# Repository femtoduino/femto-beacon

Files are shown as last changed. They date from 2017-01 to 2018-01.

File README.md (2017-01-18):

# femto-beacon
FemtoBeacon - Atmel SAM R21 (ARM Cortex M0+, SAM D21 with built in AT86RF233)

To contribute work, please do the following:

 - Fork https://github.com/femtoduino/femto-beacon
 - Checkout your fork of femto-beacon to your machine. You should now have something like `https://github.com/<your_username>/femto-beacon`
 - Add the femtoio/femto-beacon repository as the 'upstream' remote repository of your fork.

```
# Inside the checkout of your fork, add us as the remote repository named 'upstream'
git remote add upstream https://github.com/femtoduino/femto-beacon.git

# Remember to fetch from upstream to get all branch information
git fetch upstream
```

Now, you can pull the latest changes from 'upstream' into your fork, and push all work to your own fork
```
# To list branches.
git branch -a

# To pull changes from upstream 'master' branch into your 'master' branch (assuming you're in the master branch already)
git pull upstream master

# To switch into an existing branch named 'develop'
git checkout develop

# To create a new branch based on the develop branch
git checkout develop
# ...then, make sure you get the latest from upstream
git pull upstream develop
# ...now, create your new branch.
git checkout -b my-new-branch

# To push your new branch to your github fork
git push origin my-new-branch
```

...Once you push your changes to your fork, you may submit a Merge Request via github.
We will review and assess the changes before accepting or rejecting your changes.

## Requirements

For Arduino support, see https://github.com/femtoduino/ArduinoCore-atsamd21e18a/

For bare-metal programming, see below.

On Ubuntu machines, you will need Terry Guo's arm-none-eabi-* toolchain, along with the build-essentials package, openocd 0.9.x with cmsis-dap and hidapi-libusb enabled, and the BOSSA utility.

See the following on how to build OpenOCD on your machine: https://github.com/RIOT-OS/RIOT/wiki/OpenOCD
You must assert the required libraries are installed on your machine.

Compile OpenOCD with the following flags to enable cmsis-dap and hidapi support:
```
# Inside the openocd source code folder...
./configure --enable-maintainer-mode --enable-cmsis-dap --enable-hidapi-libusb
make
sudo make install
```

Install Eclipse C++, and the GNU ARM Eclipse plugins.

Install the BOSSA utility.

See https://github.com/shumatech/BOSSA

## Setup
Download the Atmel Software Framework into the libraries/ folder before compiling examples.
If you have the Atmel Software framework files in a directory named `asf-3.21.0`, then you would need it as `femto-beacon/libraries/asf-3.21.0`

Symlink the boards/femtobeacon folder into your copy of the ASF framework (libraries/asf-x.xx.x/sam0/boards/femtobeacon).
Symlink the femtoIO MPU9250 library folder into your copy of the ASF framework (libraries/asf-x.xx.x/thirdparty/MPU9250).

You can symlink the femto-beacon examples to your Eclipse workspace folder. For example, if you want to make the 'sam-r21-blink' project availabe in Eclipse:

```
# Use ~ or full path! Do not use ./
ln -s /path/to/femto-beacon/examples/sam-r21-blink /path/to/eclipse/workspace/sam-r21-blink
```

...Refresh the Project Explorer panel to view it as a project.

Update the example's config.mk file accordingly
```
# Path to top level ASF directory relative to this project directory.
PRJ_PATH = ../../libraries/asf-3.21.0
```

Then, open up the example in Eclipse, and build. This should generate a BIN file you can then upload to your board using the BOSSA shell.

## How to create a new project
Create a new C project in Eclipse, symlink the libraries/ folder from femto-beacon/libraries into your project's directory.
```
cd MyNewProject/
ln -s /path/to/femto-beacon/libraries libraries
```
You can then copy/modify the asf.h, config.mk, and Makefile into your new project. Remember to modify config.mk to include the paths of the ASF modules you wish to use.

## FemtoBeacon BT support (Nordic nRF52832 Bluetooth 4.2 + NFC, ARM Cortex M4L)
This board is unreleased at this time. These notes are here for future use.
For toolchain setup, see https://devzone.nordicsemi.com/tutorials/7/

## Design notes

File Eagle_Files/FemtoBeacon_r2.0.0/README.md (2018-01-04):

eagle-pcb-helpers
=================

A collection of JS utilities to help with Eagle PCB grunt work.

## Panelizer helper
A utility to help you panelize stuff outside the board size limits.

Image of the Panelizer helper

### Requires

 - Node http-server `npm install -g http-server`

### Usage
Use a terminal, navigate to this folder, and run `http-server ./`, then open up [https://localhost:8080/panelizer_helper.html](https://localhost:8080/panelizer_helper.html) in your favorite browser.

### About
Due to the artificially (and arbitrarily) imposed board size limitations of EAGLE PCB licensing, it becomes impossible to panelize large amounts of small boards.
This tool allows one to copy a column of board outlines, components, and text, and create the corresponding XML with updated part names (such as "IC1...IC5" to "IC6...IC10", etc), while applying a shift value to the X coordinates.

You still need to manually open the .brd file, and locate the last column of `<element>` nodes, but you can simply copy and paste that XML into this helper, set an X offset value, and process the text to generate the next column.

EAGLE PCB doesn't have any problem copying vias and traces outside the artificial boundry limits, so you really only need this tool for dimensions and components.

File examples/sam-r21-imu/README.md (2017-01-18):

You will need to symlink the libraries/ directory to your project.

The libraries/ folder should contain a symlink to your copy of the 
Atmel Software Framework (such as asf-3.21.0/).

Symlink the boards/femtobeacon/ folder to make it available as 
libraries/<your asf folder>/sam0/boards/femtobeacon/

Finally, grab a checkout of the Femto.io "MPU9250" library from git at 
https://github.com/femtoio/MPU9250, and symlink it to the 
libraries/<your asf folder>/thirdparty/ folder, resulting in a directory 
that looks like this:

libraries/<your asf folder/thirdparty/MPU9250

...Eclipse C++ with the GNU ARM Eclipse plugin should compile your project 
just fine now.

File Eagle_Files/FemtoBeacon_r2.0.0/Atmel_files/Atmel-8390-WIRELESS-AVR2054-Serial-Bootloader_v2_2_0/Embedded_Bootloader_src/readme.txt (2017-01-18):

Bootloader. Revision 2.1

Supported devices:
         MCU                                           external flash memory          RF4CE boot func  
atxmega128a1  (not tested):                                  nothing                         no 
atxmega256a3  (both compilers):                              at45db041                       no 
atmega1281    (both compilers):                              at25f2048, at45db041            yes
atmega2561    (both compilers):                              nothing                         no 
atmega128rfa1 (both compilers):                              at25f2048, at45db041            yes
atmega256rfr2 (both compilers):                              AT25DF041A                      yes
atxmega256d3  (both compilers):                              at45db041                       no

Fuse bytes for xmega:            (with and without OTAU)
FUSEBYTE0                                 0xFF
FUSEBYTE1                                 0x00
FUSEBYTE2                                 0xBF
FUSEBYTE4                                 0xFE
FUSEBYTE5                                 0xFF

Fuse bytes for atmega:       (without OTAU)     (with OTAU)     (with RF4CE boot functions)
EXTENDED                        0xFF              0xFF                    0xFF  
HIGH                            0x9C              0x9A                    0x9A 
LOW                             0x62              0x62                    0x62

Fuse bytes for atmega128rfa1/256rfr2:(without OTAU)     (with OTAU)     (with RF4CE boot functions)
EXTENDED                                  0xFE              0xFE                    0xFE   
HIGH                                      0x9C              0x9A                    0x9A
LOW                                       0x62              0x62                    0x62

Revision history:

1.0 - Initial revision.

1.1 - ATmega1281\2561 is supported.

1.2 - SPI serializer support is added for xMega, with the following parameters:
 - frequency is less or equal to 200kHz
 - start of SPI clock after slave select greater or equal to 100ns
 - delay between consecutive transfers greater or equal to 100us

spiFlasher is added to test the SPI part of the embedded bootloader (valid for the SAM7X evaluation board only).
Hardware sources used by spiFlasher:
 - IRQ1 - interrupt line for the slave data ready station (A15 on S3)
 - SPI1 - SPI interface (clock - A23, mosi - A24, miso - A25, ss - A26 on S3)

1.3 - Loading from external flash is supported for ATmega1281. The AT25f2048 external SPI flash is used. 
USART0 is used in MSPI mode; pin F3 is set as chip select. Size of boot section is 4 kbytes.

1.4 - Service area are increased (by 1 byte) for the external flash loader.

1.5 - ATmega128rfa1 is supported.

1.6 - ATxmega256d3 is supported. AT45db041 can be used for the bootloader with OTAU support.
xMega(ATxmega256a\d3) supports external flash. Both MCUs use SPI on port D to connect to external flash.
ATmega1281 and ATmega128rfa1 support AT25f2058 and AT45db041.
ATxmega256a3 and ATxmega256d3 support AT45db041.
Workaround is introduced for the following problem with xMega:
"Writing EEPROM or Flash while reading any of them will not work".

1.7 - Functions for RF4CE OTAU are added (only for ATmega1281 and ATmega128rfa1 and compilation with GCC)

1.8 - Start procedure was refactored: several interfaces are supported in a single
bootloader assembly; all interfaces scan for host's activity for 200ms by turn with 
one interface becoming main when host's activity is detected. 
IAR support is dropped.

2.0 - IAR projects are restored. AVR Studio 5 projects are added.

AT91SAM3S4C is supported, and the device firmware upgrade class of usb is supported.
Cortex bootloader is placed in the last 4kb of the internal flash memory (exclude vectors). Vectors are eliminated upon the
first image downloading (exclude reset vector). Bootloader stores the reset vector of the user's application and runs it 
by itself. A user's application can initiate a bootloading process by the use of the DFU application part from the BitCloud package 
or by writing the key byte 0x5A into the fifth byte to the end of the internal flash memory. Besides, the restoring mode 
can be initiated by connecting PB7 to the ground and turning it off\on. To load an image to a device the user can use
Bootloader PC Tool from the BitCloud package or dfu-util.exe (an open source utility, with max packet size equal to 64 bytes).

2.2 - ATmega256RFR2 device support,Atmel Studio 6 projects, Bootloading through TWI interface are added.

TWI interface is added for bootloading. The TWI boot loader allows loading of firmware images to target devices from Bootloader PC tool over the TWI interface.TWI cannot be used for direct communication with PC, an XMEGA-A1 Xplained kit is used in between for bridge functionality. The TWI module on ATxmega128A1 of XMEGA-A1 Xplained kit is configured in TWI master mode and the device running the TWI boot loader is configured in TWI slave mode. ATmega256RFR2 device support is added with projects in Atmel Studio 6 and IAR compiler. RF4CE, OTAU project support is also added for ATmega256RFR2 device. AVR Studio 4 and AVR Studio 5 projects are removed. Atmel Studio 6 projects are created for all supported devices

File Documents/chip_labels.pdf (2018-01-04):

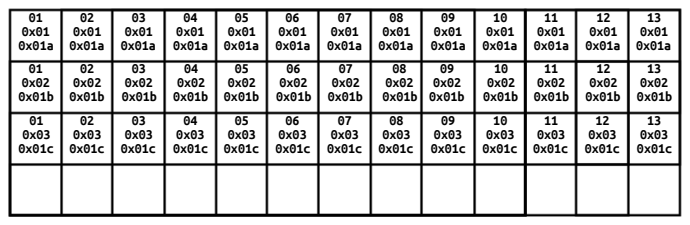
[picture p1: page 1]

02
0x03
0x01c

03
0x03
0x01c

04
0x03
0x01c

05
0x03
0x01c

06
0x03
0x01c

07
0x03
0x01c

08
0x03
0x01c

09
0x03
0x01c

10
0x03
0x01c

11
0x03
0x01c

12
0x03
0x01c

13
0x03
0x01c

01
0x01
0x01a

03
0x01
0x01a

02
0x01
0x01a

04
0x01
0x01a

05
0x01
0x01a

06
0x01
0x01a

07
0x01
0x01a

08
0x01
0x01a

09
0x01
0x01a

10
0x01
0x01a

11
0x01
0x01a
11
0x02
0x01b

12
0x02
0x01b

13
0x02
0x01b
01
0x03
0x01c

12
0x01
0x01a

13
0x01
0x01a
01
0x02
0x01b

02
0x02
0x01b

03
0x02
0x01b

04
0x02
0x01b

05
0x02
0x01b

06
0x02
0x01b

07
0x02
0x01b

08
0x02
0x01b

09
0x02
0x01b

10
0x02
0x01b

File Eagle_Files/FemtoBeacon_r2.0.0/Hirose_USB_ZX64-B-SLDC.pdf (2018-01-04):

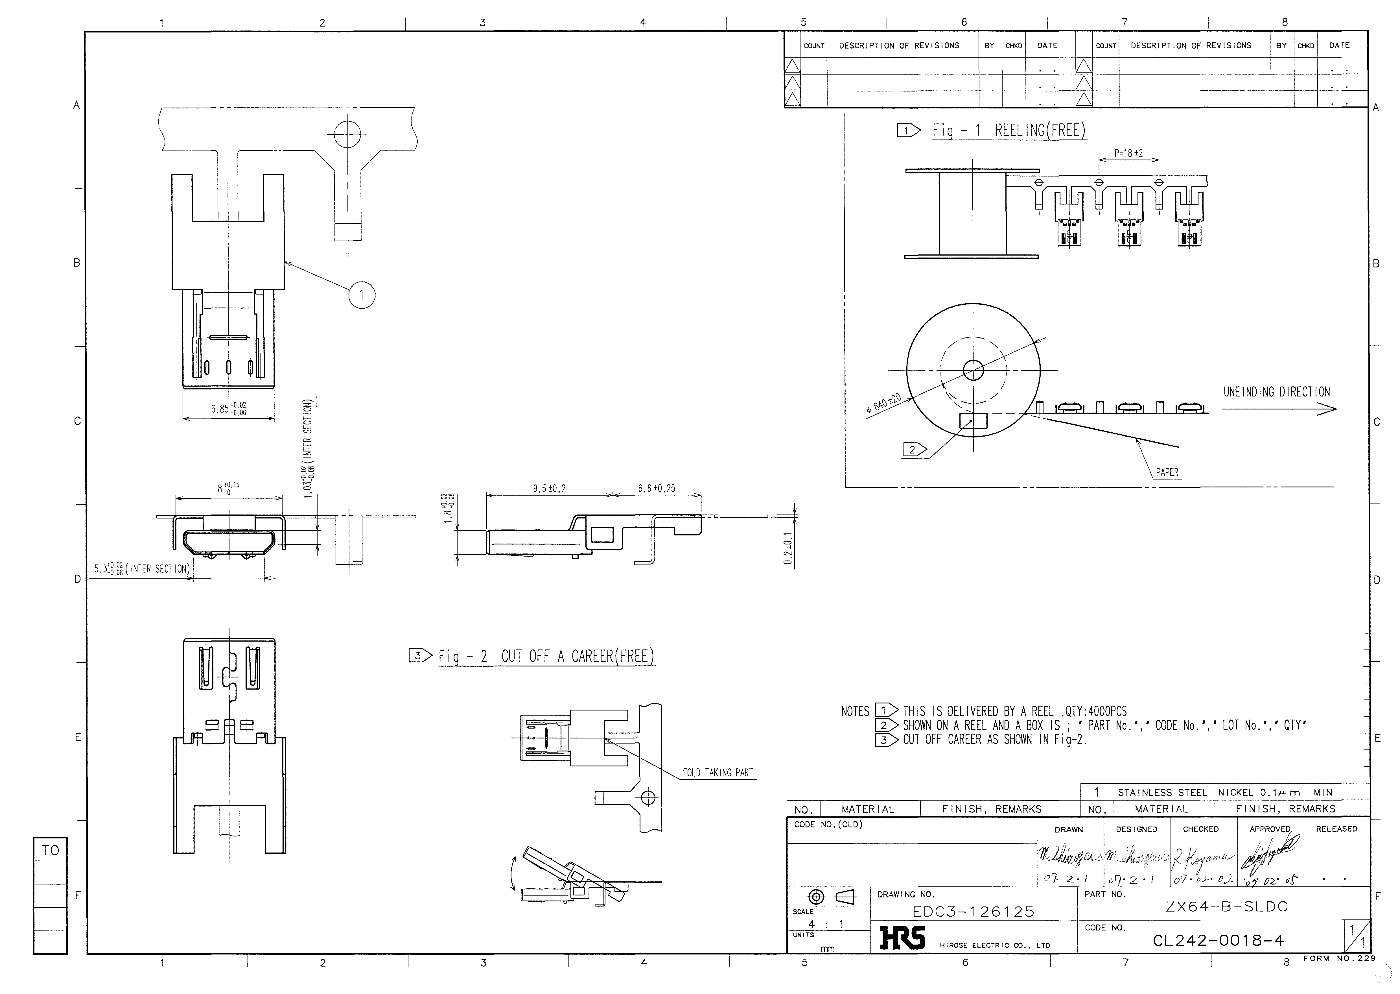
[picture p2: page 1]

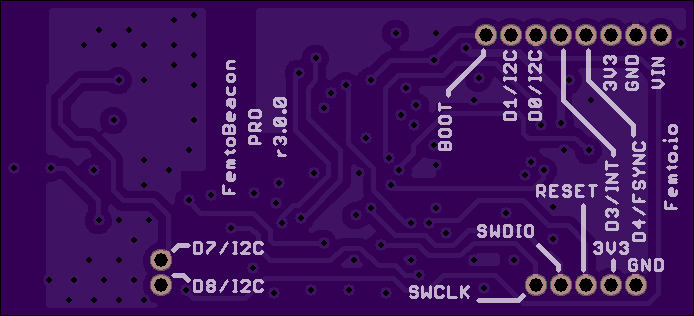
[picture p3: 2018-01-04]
Eagle_Files/FemtoBeacon_r2.0.0/femtoBeacon_PRO_r3.0.0-bottom.png

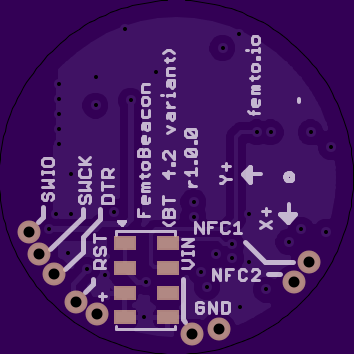
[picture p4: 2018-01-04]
Eagle_Files/FemtoBeacon_BLE_r1.0.0/FemtoBeacon_coin_nRF52832_BT4.2_r1.0.0_bottom.png

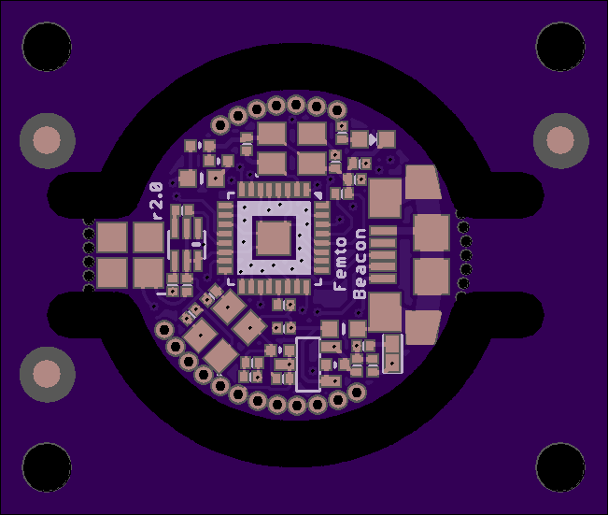
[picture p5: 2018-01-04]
Blender3d_Files/femtoBeacon_r2.0.3_top.png

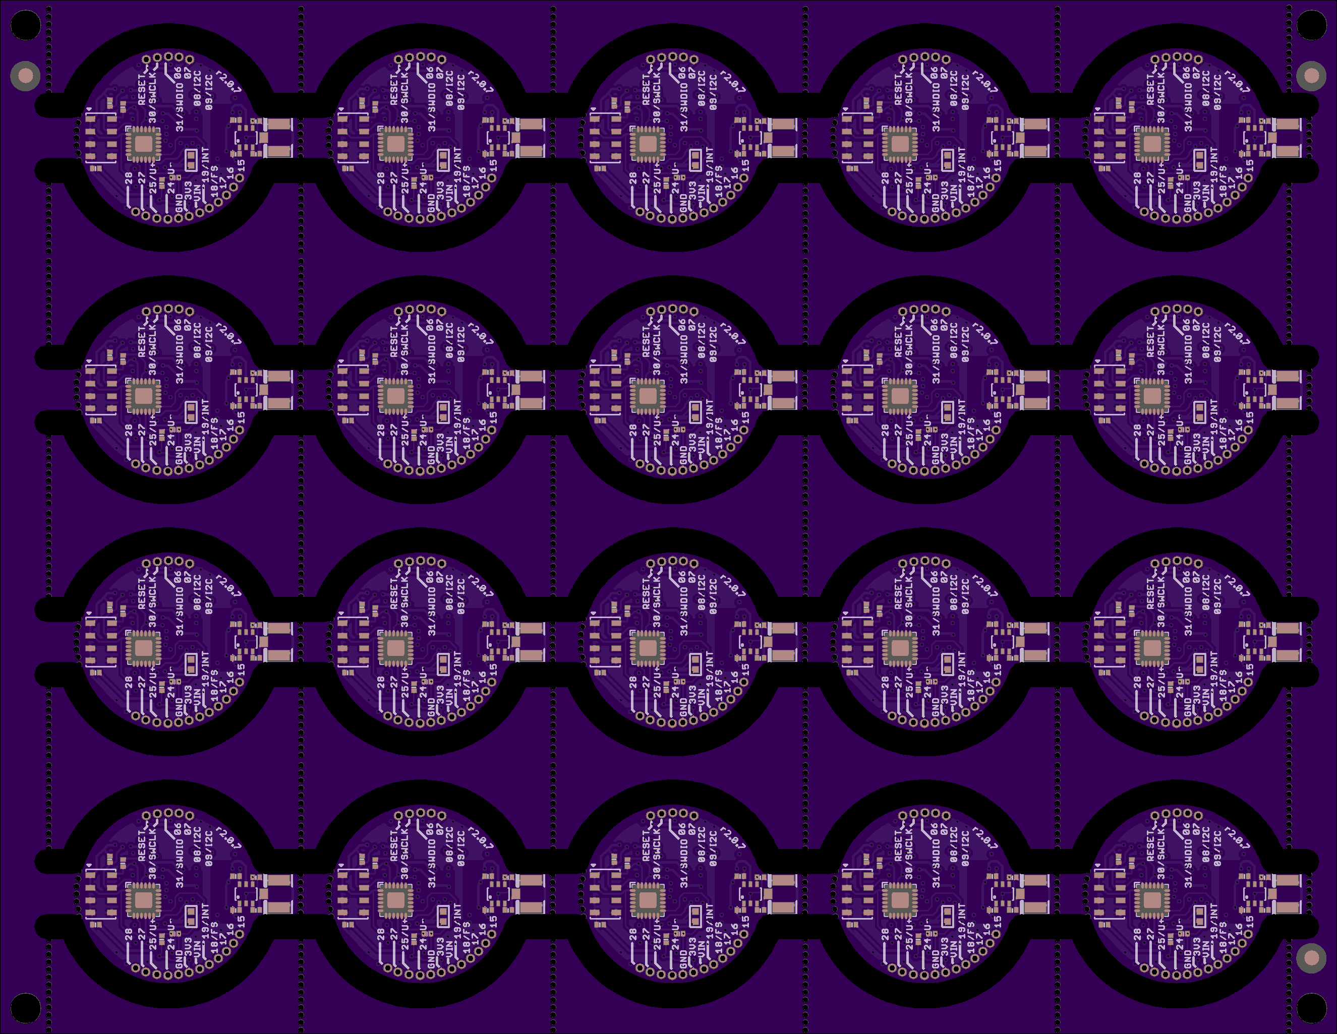
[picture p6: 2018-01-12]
Eagle_Files/FemtoBeacon_r2.0.0/femtoBeacon_r2.0.7_RGB_OTG_PANELIZED-bottom.png

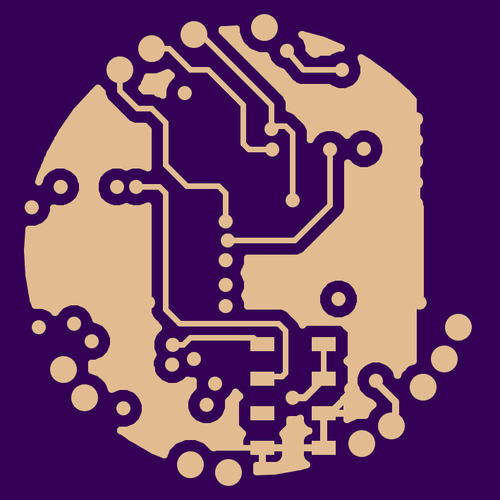
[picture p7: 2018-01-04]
Eagle_Files/FemtoBeacon_BLE_r1.0.0/femtoBeacon_BT_art1.png

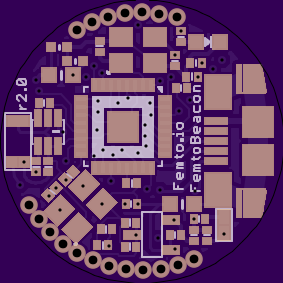
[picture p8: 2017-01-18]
Eagle_Files/FemtoBeacon_r2.0.0/femtoBeacon_r2.0.1-top.png

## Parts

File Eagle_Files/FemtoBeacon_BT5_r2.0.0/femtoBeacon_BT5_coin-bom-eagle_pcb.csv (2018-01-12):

Qty | Value | Device | Package | Parts | Description | MFR_ID
1 |  | PTCFUSE-1206 | R1206 | F1 | PTC fuses, resettable thermistors | 1206L050/15YR
1 | 0.1uF | CAPACITOR_0201 | PART | C2 |  | GRM033C80J104KE84D
1 | 10UH | INDUCTOR_0402MP | _0402MP | L2 | Inductors | LQM18FN100M00D
1 | 15nH | INDUCTOR_FIXED_0201 | PART | L1 |  | LQP03HQ15NJ02D
9 | 1X1_ROUND_MM | 1X1_ROUND_MM | 1X1_ROUND_MM | U$16, U$17, U$18, U$19, U$20, U$21, U$22, U$23, U$24
1 | 1X5_ROUND | 1X5_ROUND | 1X5_ROUND | U$6
3 | 330 | RESISTOR_0201 | PART | R1, R2, R3 |  | CRCW0201330RJNED
1 | 4.7uF | CAP_CERAMIC_0402MP | _0402MP | C1 | Ceramic Capacitors | CC0402KRX5R6BB475
3 | FIDUCIAL | FIDUCIAL | FIDUCIAL_1MM | FID1, FID2, FID3 | For use by pick and place machines to calibrate the vision/machine, 1mm
1 | LRTB_R48G | LRTB_R48G | LRTB_R48G | LED1
1 | SCHOTTKY | LED0603_NOOUTLINE | CHIPLED_0603_NOOUTLINE | LED2 | LED | SD0603S040S0R2
1 | TY_BLE_EYSHSNZWZ | TY_BLE_EYSHSNZWZ | MODULE | IC |  | EYSHSNZWZ

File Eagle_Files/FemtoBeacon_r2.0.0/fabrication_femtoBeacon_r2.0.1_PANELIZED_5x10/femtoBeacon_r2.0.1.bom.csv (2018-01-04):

Qty | Value | Device | Package | Parts | Description | DIGIKEY_PART
1 |  | FERRITE_0603MP | _0603MP | FB1 | Ferrite Bead
10 | 0.1uF | CAPACITOR_0201 | PART | C1, C2, C8, C9, C10, C16, C17, C29, C30, C32 |  | 490-3194-1-ND
1 | 0.47uF | CAPACITOR_0201 | PART | C7
1 | 10K | RESISTOR_0201 | PART | R2
1 | 10nF | CAPACITOR_0201 | PART | C31 |  | 490-3194-1-ND
2 | 10pF | CAPACITOR_0201 | PART | C3, C4 |  | 490-3194-1-ND
2 | 10uF | CAP_CERAMIC_0402MP | _0402MP | C21, C22 | Ceramic Capacitors
1 | 10uH | INDUCTOR_0603MP | _0603MP | L6 | Inductors
1 | 12MHz | TSX-3225 | TSX-3225 | XOSC
1 | 16MHz | TSX-3225 | TSX-3225 | XOSCRF
2 | 2.2K | RESISTOR_0201 | PART | R8, R9
2 | 2.2uF | CAP_CERAMIC_0402MP | _0402MP | C5, C6 | Ceramic Capacitors
2 | 22pF, C0G, 5% | CAPACITOR_0201 | PART | C11, C12 |  | 490-3194-1-ND
2 | 330 | RESISTOR_0201 | PART | R1, R4
2 | 9pF | CAPACITOR_0201 | PART | C14, C15 |  | 490-3194-1-ND
1 | ATSAMR21E18A-MUT | ATSAMR21E18A-MUT | QFN32 | IC | This is the ATMEL SAMR21E QFN-32. ATSAMR21E18A
1 | BLUE | LED0603_NOOUTLINE | CHIPLED_0603_NOOUTLINE | LED2 | LED
1 | JOHANSON_2450BM15A0015E | JOHANSON_2450BM15A0015E | 0805_BALUN | BAL
1 | MCP1700T-3302E/TT | MCP1700T-3302E/TT | MCP1700T-3302E/TT | LDO_VREG | Microchip LDO "MCP1700" in a 3-Pin SOT-23 package.
1 | MPU-9250 | MPU-9250 | QFN_3X3MM | IMU
1 | MS5611-01BA03 | MS5611-01BA03 | MS5611-01BA03 | BARO
1 | PULSE_ANT_2.4GHZ | PULSE_ANT_2.4GHZ | ANT_BAR | ANT1 | Manufacturer part #W3008
1 | USB_MICROB | USB_MICROB | USB_MICROB_PACKAGE | USB | This is the hirose ZX62-B-5PA(11) MICRO-USB B Type female connection.

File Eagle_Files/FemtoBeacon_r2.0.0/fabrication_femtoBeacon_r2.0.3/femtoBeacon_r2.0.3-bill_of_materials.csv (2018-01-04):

Qty | Value | Device | Package | Parts | Description
1 |  | FERRITE_0603MP | _0603MP | FB1 | Ferrite Bead
10 | 0.1uF | CAPACITOR_0201 | PART | C1, C2, C8, C9, C10, C16, C17, C29, C30, C32
1 | 0.47uF | CAPACITOR_0201 | PART | C7
1 | 0479480001 | 0479480001 | 0479480001 | U$8
1 | 10K | RESISTOR_0201 | PART | R2
1 | 10nF | CAPACITOR_0201 | PART | C31
2 | 10pF | CAPACITOR_0201 | PART | C3, C4
2 | 10uF | CAP_CERAMIC_0402MP | _0402MP | C21, C22 | Ceramic Capacitors
1 | 10uH | INDUCTOR_0603MP | _0603MP | L6 | Inductors
1 | 12MHz | TSX-3225 | TSX-3225 | XOSC
1 | 16MHz | TSX-3225 | TSX-3225 | XOSCRF
19 | 1X1_ROUND | 1X1_ROUND | 1X1_ROUND | U$1, U$2, U$5, U$7, U$9, U$10, U$35, U$36, U$37, U$38, U$39, U$41, U$42, U$43, U$45, U$46, U$47, U$48, U$54
2 | 2.2K | RESISTOR_0201 | PART | R8, R9
2 | 2.2uF | CAP_CERAMIC_0402MP | _0402MP | C5, C6 | Ceramic Capacitors
2 | 22pF, C0G, 5% | CAPACITOR_0201 | PART | C11, C12
2 | 330 | RESISTOR_0201 | PART | R1, R4
2 | 9pF | CAPACITOR_0201 | PART | C14, C15
1 | ATSAMR21E18A-MUT | ATSAMR21E18A-MUT | QFN32 | IC | This is the ATMEL SAMR21E QFN-32. ATSAMR21E18A
1 | BLUE | LED0603_NOOUTLINE | CHIPLED_0603_NOOUTLINE | LED2 | LED
1 | DNP | CAPACITOR_0201 | PART | C13
1 | DNP | SPST_SMD | SPST_SMD | BTN
6 | FIDUCIAL | FIDUCIAL | FIDUCIAL_1MM | FID1, FID2, FID3, FID4, FID5, FID6 | For use by pick and place machines to calibrate the vision/machine, 1mm
1 | JOHANSON_2450BM15A0015E | JOHANSON_2450BM15A0015E | 0805_BALUN | BAL
1 | MCP1700T-3302E/TT | MCP1700T-3302E/TT | MCP1700T-3302E/TT | LDO_VREG | Microchip LDO MCP1700" in a 3-Pin SOT-23 package."
1 | MPU-9250 | MPU-9250 | QFN_3X3MM | IMU
1 | MS5611-01BA03 | MS5611-01BA03 | MS5611-01BA03 | BARO
1 | SOLDER_JUMPER_CLOSED | SOLDER_JUMPER_CLOSED | SOLDER_JUMP_CLOSED | SJ1
1 | USB_MICROB | USB_MICROB | USB_MICROB_PACKAGE | USB | This is the hirose ZX62-B-5PA(11) MICRO-USB B Type female connection.

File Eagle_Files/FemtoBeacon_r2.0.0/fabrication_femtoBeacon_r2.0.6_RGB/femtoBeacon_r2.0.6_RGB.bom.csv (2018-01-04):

Qty | Value | Device | Package | Parts | Description | MFR_ID
1 |  | ANTENNA_U.FL | U.FL | UFLANT | U.FL Antenna Connector | 734120110
1 |  | FERRITE_0603MP | _0603MP | FB1 | Ferrite Bead | BLM18RK102SN1D
10 | 0.1uF | CAPACITOR_0201 | PART | C1, C2, C8, C9, C10, C16, C17, C29, C30, C32 |  | CL03A104KP3NNNC
1 | 0.47uF | CAPACITOR_0201 | PART | C7 |  | C0603X5R0J474K030BC
1 | 479480001 | 479480001 | 479480001 | ANT_SMD |  | 479480001
1 | 1.2pF | CAP_CERAMIC_0402MP | _0402MP | C11 | Ceramic Capacitors | GRM1555C1H1R2BA01D
1 | 1.8nH | INDUCTOR_0603MP | _0603MP | L1 | Inductors | L-14C1N8SV4T
1 | 10K | RESISTOR_0201 | PART | R2 |  | RC0402FR-0710KL
1 | 10nF | CAPACITOR_0201 | PART | C31 |  | GRM033R71A103KA01D
2 | 10uF | CAP_CERAMIC_0402MP | _0402MP | C21, C22 | Ceramic Capacitors | 490-13233-1-ND
1 | 10uH | INDUCTOR_0603MP | _0603MP | L6 | Inductors | LQM18FN100M00D
1 | 16MHz | TSX-3225 | TSX-3225 | XOSCRF |  | TSX-3225 16.0000MF09Z-AC0
2 | 2.2K | RESISTOR_0201 | PART | R8, R9 |  | CRCW02012K20JNED
2 | 2.2uF | CAP_CERAMIC_0402MP | _0402MP | C5, C6 | Ceramic Capacitors | C1005X5R1A225K050BC
5 | 22pF, C0G, 5% | CAPACITOR_0201 | PART | C12, C18, C19, C20, C23 |  | GRM0335C1E220JA01D
4 | 330 | RESISTOR_0201 | PART | R1, R4, R6, R7 |  | CRCW0201330RJNED
1 | 330 | RESISTOR_0402 | _0402 | R3 | Resistors | CRCW0402330RJNED
2 | 9pF | CAPACITOR_0201 | PART | C14, C15 |  | C0603C0G1E090B030BG
1 | AS222-92LF | AS222-92LF | AS222-92LF | ASWITCH |  | AS222-92LF
1 | ATSAMR21E18A-MUT | ATSAMR21E18A-MUT | QFN32 | IC | This is the ATMEL SAMR21E QFN-32. ATSAMR21E18A | ATSAMR21E18A-MFT
1 | JOHANSON_2450BM15A0015E | JOHANSON_2450BM15A0015E | 0805_BALUN | BALUN |  | 2450BM15A0015E
1 | LRTB_R48G | LRTB_R48G | LRTB_R48G | RGBLED |  | LRTBR48G-P9Q7-1+R7S5-26+N5P-68-ZB
1 | MCP1700T-3302E/TT | MCP1700T-3302E/TT | MCP1700T-3302E/TT | LDO_VREG | Microchip LDO "MCP1700" in a 3-Pin SOT-23 package. | MCP1700T-3302E/TT
1 | MPU-9250 | MPU-9250 | QFN_3X3MM | IMU |  | MPU-9250
1 | MS5611-01BA03 | MS5611-01BA03 | MS5611-01BA03 | BARO |  | MS561101BA03-50
1 | USB_MICROB | USB_MICROB | USB_MICROB_PACKAGE | USB | This is the hirose ZX62-B-5PA(11) MICRO-USB B Type female connection. | ZX62-B-5PA(33)

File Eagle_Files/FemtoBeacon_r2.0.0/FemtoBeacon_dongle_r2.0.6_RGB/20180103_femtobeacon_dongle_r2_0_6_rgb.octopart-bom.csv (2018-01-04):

Qty | Line Item | Manufacturer | MPN | Octopart URL | Schematic Reference | Internal Part Number | Description | Total Qty (@ Batch Size: 100) | SKU | SKU | SKU | Packaging | Packaging | Packaging | Unit Price (@ Batch Size: 100) | Unit Price (@ Batch Size: 100) | Unit Price (@ Batch Size: 100) | In Stock | In Stock | In Stock | MOQ | MOQ | MOQ | URL | URL | URL | Distributor [Lowest Price (Overall)] | SKU [Lowest Price (Overall)] | Packaging [Lowest Price (Overall)] | Unit Price (@ Batch Size: 100) [Lowest Price (Overall)] | Line Total [Lowest Price (Overall)] | Batch Total [Lowest Price (Overall)] | In Stock [Lowest Price (Overall)] | MOQ [Lowest Price (Overall)] | URL [Lowest Price (Overall)] | Notes
 |  |  |  |  |  |  |  |  | Digi-Key | Mouser | Newark | Digi-Key | Mouser | Newark | Digi-Key | Mouser | Newark | Digi-Key | Mouser | Newark | Digi-Key | Mouser | Newark | Digi-Key | Mouser | Newark
2 | BLM18RK102SN1D | Murata | BLM18RK102SN1D | https://octopart.com/blm18rk102sn1d-murata-755186 | FB1, FB2 | FERRITE_0603MP | Ferrite Bead | 200 | 490-5228-1-ND | BLM18RK102SN1D | 73M9117 | Cut Tape |  | Cut Tape | 0.047 | 0.038 | 0.038 | 465161 | 54056 | 0 | 1 |  | 1 | https://octopart.com/click/track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 | https://octopart.com/click/track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 | https://octopart.com/click/track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 | LCSC | C88986 |  | 0.0139 | 0.0278 | 2.78 | 6050 | 50 | https://octopart.com/click/track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
1 | 931 | Keystone | 931 | https://octopart.com/931-keystone-7166852 | CN1 | USB_TYPEA | USB - Type A Connectors | 100 | 36-931-ND | 931 | 22M3566 | Bulk |  |  | 0.66 | 0.667 | 0.75 | 9287 | 1317 | 0 | 1 |  | 1 | https://octopart.com/click/track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 | https://octopart.com/click/track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 | https://octopart.com/click/track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 | TME | KEYS931 |  | 0.5753 | 0.5753 | 57.53 | 463 | 1 | https://octopart.com/click/track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
7 | GRM033C80J104KE84D | Murata | GRM033C80J104KE84D | https://octopart.com/grm033c80j104ke84d-murata-46692001 | C1, C2, C8, C9, C10, C16, C17 | CAPACITOR_0201 |  | 700 | 490-9980-1-ND | GRM033C80J104KE84D |  | Cut Tape |  |  | 0.00932 | 0.014 |  | 253 | 0 |  | 1 |  |  | https://octopart.com/click/track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 | https://octopart.com/click/track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 |  | Arrow | GRM033C80J104KE84D**MULT |  | 0.0069 | 0.048299999999999996 | 4.83 | 14500 | 1 | https://octopart.com/click/track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
1 | C0603X5R0J474K030BC | TDK | C0603X5R0J474K030BC | https://octopart.com/c0603x5r0j474k030bc-tdk-28166569 | C7 | CAPACITOR_0201 |  | 100 | 445-13653-1-ND | C0603X5R0J474K030BC | 78Y9870 | Cut Tape |  | Cut Tape | 0.0808 | 0.068 | 0.068 | 416854 | 76671 | 3180 | 1 |  | 10 | https://octopart.com/click/track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 | https://octopart.com/click/track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 | https://octopart.com/click/track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 | Chip One Stop Japan | C1S741000789620 | Cut Tape | 0.0262 | 0.0262 | 2.62 | 9926 | 50 | https://octopart.com/click/track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
1 | 51T4020 | Molex | 47948-0001 | https://octopart.com/47948-0001-molex-20326346 | U$6 | 479480001 |  | 100 |  | 47948-0001 | 51T4020 |  |  | Cut Tape |  | 1.18 | 0.819 |  | 5669 | 0 |  |  | 1 |  | https://octopart.com/click/track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 | https://octopart.com/click/track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 | Newark | 51T4020 | Cut Tape | 0.819 | 0.819 | 81.89999999999999 | 0 | 1 | https://octopart.com/click/track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
1 | GRM1555C1H1R2BA01D | Murata | GRM1555C1H1R2BA01D | https://octopart.com/grm1555c1h1r2ba01d-murata-18814399 | C11 | CAP_CERAMIC_0402MP | Ceramic Capacitors | 100 | 490-6209-1-ND | GRM1555C1H1R2BA01D | 31Y1753 | Cut Tape |  | Cut Tape | 0.0223 | 0.023 | 0.023 | 1910 | 101362 | 30286 | 1 |  | 10 | https://octopart.com/click/track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 | https://octopart.com/click/track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 | https://octopart.com/click/track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 | LCSC | C76954 |  | 0.0041 | 0.0041 | 0.41000000000000003 | 750 | 50 | https://octopart.com/click/track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
1 | L-14C1N8SV4T | Johanson | L-14C1N8SV4T | https://octopart.com/l-14c1n8sv4t-johanson-12565139 | L1 | INDUCTOR_0603MP | Inductors | 100 | 712-1426-1-ND | L-14C1N8SV4T |  | Cut Tape |  |  | 0.0411 | 0.035 |  | 4289 | 15070 |  | 1 |  |  | https://octopart.com/click/track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 | https://octopart.com/click/track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 |  | Mouser | L-14C1N8SV4T |  | 0.035 | 0.035 | 3.5000000000000004 | 15070 |  | https://octopart.com/click/track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
1 | RC0402FR-0710KL | Yageo | RC0402FR-0710KL | https://octopart.com/rc0402fr-0710kl-yageo-55458461 | R2 | RESISTOR_0201 |  | 100 | 311-10.0KLRCT-ND | RC0402FR-0710KL | 98K7499 | Cut Tape |  | Cut Tape | 0.0056 | 0.003 | 0.006 | 10142433 | 2551721 | 323566 | 1 |  | 10 | https://octopart.com/click/track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 | https://octopart.com/click/track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 | https://octopart.com/click/track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 | LCSC | C60490 |  | 0.0017 | 0.0017 | 0.16999999999999998 | 493200 | 100 | https://octopart.com/click/track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
2 | AMK105CBJ106MV-F | Taiyo Yuden | AMK105CBJ106MV-F | https://octopart.com/amk105cbj106mv-f-taiyo+yuden-24529245 | C21, C22 | CAP_CERAMIC_0402MP | Ceramic Capacitors | 200 | 587-3237-1-ND | AMK105CBJ106MV-F | 29X9101 | Cut Tape |  | Cut Tape | 0.1 | 0.104 | 0.104 | 346664 | 51023 | 20000 | 1 |  | 1 | https://octopart.com/click/track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 | https://octopart.com/click/track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 | https://octopart.com/click/track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 | Chip One Stop Japan | C1S758100418570 | Cut Tape | 0.0623 | 0.1246 | 12.46 | 11700 | 50 | https://octopart.com/click/track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
1 | LQM18FN100M00D | Murata | LQM18FN100M00D | https://octopart.com/lqm18fn100m00d-murata-387572 | L6 | INDUCTOR_0603MP | Inductors | 100 | 490-4025-1-ND | LQM18FN100M00D |  | Cut Tape |  |  | 0.0893 | 0.089 |  | 137411 | 49320 |  | 1 |  |  | https://octopart.com/click/track?country=US&ak=68b25f31&sig=0e2d062&sid=459&ppid=387572&vpid=1864289&ct=offers | https://octopart.com/click/track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 |  | LCSC | C86083 |  | 0.0455 | 0.0455 | 4.55 | 16910 | 10 | https://octopart.com/click/track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
1 | TSX-3225 16.0000MF09Z-AC0 | Epson | TSX-3225 16.0000MF09Z-AC0 | https://octopart.com/tsx-3225+16.0000mf09z-ac0-epson-12822835 | XOSCRF | TSX-3225 |  | 100 | SER4069CT-ND | TSX-3225 16.0000MF09Z-AC0 |  | Cut Tape |  |  | 0.374 | 0.34 |  | 55482 | 374 |  | 1 |  |  | https://octopart.com/click/track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 | https://octopart.com/click/track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 |  | Mouser | TSX-3225 16.0000MF09Z-AC0 |  | 0.34 | 0.34 | 34 | 374 |  | https://octopart.com/click/track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
2 | C1005X5R1A225K050BC | TDK | C1005X5R1A225K050BC | https://octopart.com/c1005x5r1a225k050bc-tdk-25947534 | C5, C6 | CAP_CERAMIC_0402MP | Ceramic Capacitors | 200 | 445-7392-1-ND | C1005X5R1A225K050BC | 05X9833 | Cut Tape |  | Cut Tape | 0.1518 | 0.112 | 0.112 | 209061 | 0 | 55521 | 1 |  | 10 | https://octopart.com/click/track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 | https://octopart.com/click/track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 | https://octopart.com/click/track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 | TTI | C1005X5R1A225K050BC. |  | 0.101 | 0.202 | 20.200000000000003 | 15200 |  | https://octopart.com/click/track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
5 | GRM0335C1E220JA01D | Murata | GRM0335C1E220JA01D | https://octopart.com/grm0335c1e220ja01d-murata-22235265 | C18, C19, C20, C23, C24 | CAPACITOR_0201 |  | 500 | 490-1253-1-ND | GRM0335C1E220JA01D | 80X8548 | Cut Tape |  | Cut Tape | 0.004 | 0.006 | 0.004 | 7140 | 11200 | 6685 | 1 |  | 10 | https://octopart.com/click/track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 | https://octopart.com/click/track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 | https://octopart.com/click/track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 | LCSC | C76919 |  | 0.0017 | 0.008499999999999999 | 0.8499999999999999 | 600 | 100 | https://octopart.com/click/track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
4 | CRCW0201330RJNED | Vishay | CRCW0201330RJNED | https://octopart.com/crcw0201330rjned-vishay-39985897 | R1, R4, R6, R7 | RESISTOR_0201 |  | 400 | 541-330AGCT-ND | CRCW0201330RJNED | 48P7351 | Cut Tape |  | Tape & Reel | 0.0286 | 0.028 |  | 17953 | 22577 | 0 | 1 |  | 10000 | https://octopart.com/click/track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 | https://octopart.com/click/track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 | https://octopart.com/click/track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 | Mouser | CRCW0201330RJNED |  | 0.028 | 0.112 | 11.200000000000001 | 22577 |  | https://octopart.com/click/track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
2 | C0603C0G1E090B030BG | TDK | C0603C0G1E090B030BG | https://octopart.com/c0603c0g1e090b030bg-tdk-26012936 | C14, C15 | CAPACITOR_0201 |  | 200 | 445-5562-1-ND |  |  | Cut Tape |  |  | 0.1442 |  |  | 22259 |  |  | 1 |  |  | https://octopart.com/click/track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 |  |  | Digi-Key | 445-5562-1-ND | Cut Tape | 0.1442 | 0.2884 | 28.84 | 22259 | 1 | https://octopart.com/click/track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
1 | AS222-92LF | Skyworks Solutions | AS222-92LF | https://octopart.com/as222-92lf-skyworks+solutions-3998133 | ASWITCH | AS222-92LF |  | 100 | 863-1240-1-ND | AS222-92LF |  | Cut Tape |  |  | 0.6369 | 0.603 |  | 48789 | 10101 |  | 1 |  |  | https://octopart.com/click/track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 | https://octopart.com/click/track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 |  | Component Distributors Inc. | AS222-92LF | Tape & Reel | 0.377 | 0.377 | 37.7 | 3000 | 1 | https://octopart.com/click/track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
1 | ATSAMR21E18A-MFT | Microchip | ATSAMR21E18A-MFT | https://octopart.com/atsamr21e18a-mft-microchip-77761734 | U$76 | ATSAMR21E18A-MUT | This is the ATMEL SAMR21E QFN-32. ATSAMR21E18A | 100 | ATSAMR21E18A-MFTTR-ND |  |  | Tape & Reel |  |  |  |  |  | 0 |  |  | 5000 |  |  | https://octopart.com/click/track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 |  |  | Verical | ATSAMR21E18A-MFT |  | 5.814 | 5.814 | 581.4 | 5000 | 7 | https://octopart.com/click/track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
1 | 2450BM15A0015E | Johanson | 2450BM15A0015E | https://octopart.com/2450bm15a0015e-johanson-28515455 | U$12 | JOHANSON_2450BM15A0015E |  | 100 | 712-1576-1-ND | 2450BM15A0015E | 09X1325 | Cut Tape |  | Cut Tape | 0.6753 | 0.692 | 0.661 | 104419 | 12153 | 6433 | 1 |  | 10 | https://octopart.com/click/track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 | https://octopart.com/click/track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 | https://octopart.com/click/track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 | Newark | 09X1325 | Cut Tape | 0.661 | 0.661 | 66.10000000000001 | 6433 | 10 | https://octopart.com/click/track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
1 | LRTBR48G-P9Q7-1+R7S5-26+N5P-68-ZB | Osram Opto | LRTBR48G-P9Q7-1+R7S5-26+N5P-68-ZB | https://octopart.com/lrtbr48g-p9q7-1%2Br7s5-26%2Bn5p-68-zb-osram+opto-71774791 | RGBLED | LRTB_R48G |  | 100 |  | LRTBR48G-P9Q7-1+R7S5-26+N5P-68-ZB |  |  |  |  |  | 0.222 |  |  | 96435 |  |  |  |  |  | https://octopart.com/click/track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 |  | Mouser | LRTBR48G-P9Q7-1+R7S5-26+N5P-68-ZB |  | 0.222 | 0.222 | 22.2 | 96435 |  | https://octopart.com/click/track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
1 | MCP1700T-3302E/TT | Microchip | MCP1700T-3302E/TT | https://octopart.com/mcp1700t-3302e%2Ftt-microchip-535742 | LDO_VREG | MCP1700T-3302E/TT | Microchip LDO "MCP1700"" in a 3-Pin SOT-23 package." | 100 | MCP1700T3302ETTCT-ND | MCP1700T-3302E/TT | 88H9817 | Cut Tape |  | Cut Tape | 0.2968 | 0.28 | 0.28 | 107494 | 83650 | 0 | 1 |  | 1 | https://octopart.com/click/track?country=US&ak=68b25f31&sig=071bb1d&sid=459&ppid=535742&vpid=1805989&ct=offers | https://octopart.com/click/track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 | https://octopart.com/click/track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 | LCSC | C39051 |  | 0.186 | 0.186 | 18.6 | 10229 | 1 | https://octopart.com/click/track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
1 | 734120110 | Molex | 73412-0110 | https://octopart.com/73412-0110-molex-2500696 | UFLANT | ANTENNA_U.FL | U.FL Antenna Connector | 100 |  | 73412-0110 | 35M2151 |  |  | Cut Tape |  | 0.438 | 0.438 |  | 43329 | 0 |  |  | 1 |  | https://octopart.com/click/track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 | https://octopart.com/click/track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 | Arrow | 734120110**MULT1 | Cut Tape | 0.3817 | 0.3817 | 38.17 | 25647 | 1 | https://octopart.com/click/track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

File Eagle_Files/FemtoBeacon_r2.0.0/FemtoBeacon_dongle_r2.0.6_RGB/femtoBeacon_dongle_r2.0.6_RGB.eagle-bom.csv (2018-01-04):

Qty | Value | Device | Package | Parts | Description | MFR_ID
2 |  | FERRITE_0603MP | _0603MP | FB1, FB2 | Ferrite Bead | BLM18RK102SN1D
1 |  | USB_TYPEA | USB_A-SMT | CN1 | USB - Type A Connectors | Keystone 931
7 | 0.1uF | CAPACITOR_0201 | PART | C1, C2, C8, C9, C10, C16, C17 |  | GRM033C80J104KE84D
1 | 0.47uF | CAPACITOR_0201 | PART | C7 |  | C0603X5R0J474K030BC
1 | 479480001 | 479480001 | 479480001 | U$6 |  | 51T4020
1 | 1.2pF | CAP_CERAMIC_0402MP | _0402MP | C11 | Ceramic Capacitors | GRM1555C1H1R2BA01D
1 | 1.8nH | INDUCTOR_0603MP | _0603MP | L1 | Inductors | L-14C1N8SV4T
1 | 10K | RESISTOR_0201 | PART | R2 |  | RC0402FR-0710KL
2 | 10uF | CAP_CERAMIC_0402MP | _0402MP | C21, C22 | Ceramic Capacitors | AMK105CBJ106MV-F
1 | 10uH | INDUCTOR_0603MP | _0603MP | L6 | Inductors | LQM18FN100M00D
1 | 16MHz | TSX-3225 | TSX-3225 | XOSCRF |  | TSX-3225 16.0000MF09Z-AC0
1 | DNP | 1X5_ROUND | 1X5_ROUND | U$1
2 | 2.2uF | CAP_CERAMIC_0402MP | _0402MP | C5, C6 | Ceramic Capacitors | C1005X5R1A225K050BC
5 | 22pF | CAPACITOR_0201 | PART | C18, C19, C20, C23, C24 |  | GRM0335C1E220JA01D
4 | 330 | RESISTOR_0201 | PART | R1, R4, R6, R7 |  | CRCW0201330RJNED
2 | 9pF | CAPACITOR_0201 | PART | C14, C15 |  | C0603C0G1E090B030BG
1 | AS222-92LF | AS222-92LF | AS222-92LF | ASWITCH |  | AS222-92LF
1 | ATSAMR21E18A-MUT | ATSAMR21E18A-MUT | QFN32 | U$76 | This is the ATMEL SAMR21E QFN-32. ATSAMR21E18A | ATSAMR21E18A-MFT
1 | DNP | CAPACITOR_0201 | PART | C13
1 | DNP | SPST_SMD | SPST_SMD | BTN
3 | FIDUCIAL | FIDUCIAL | FIDUCIAL_1MM | FID1, FID2, FID3 | For use by pick and place machines to calibrate the vision/machine, 1mm
1 | JOHANSON_2450BM15A0015E | JOHANSON_2450BM15A0015E | 0805_BALUN | U$12 |  | 2450BM15A0015E
1 | LRTB_R48G | LRTB_R48G | LRTB_R48G | RGBLED |  | LRTB R48G
1 | MCP1700T-3302E/TT | MCP1700T-3302E/TT | MCP1700T-3302E/TT | LDO_VREG | Microchip LDO "MCP1700" in a 3-Pin SOT-23 package. | MCP1700T-3302E/TT
1 | uFL | ANTENNA_U.FL | U.FL | UFLANT | U.FL Antenna Connector | 734120110

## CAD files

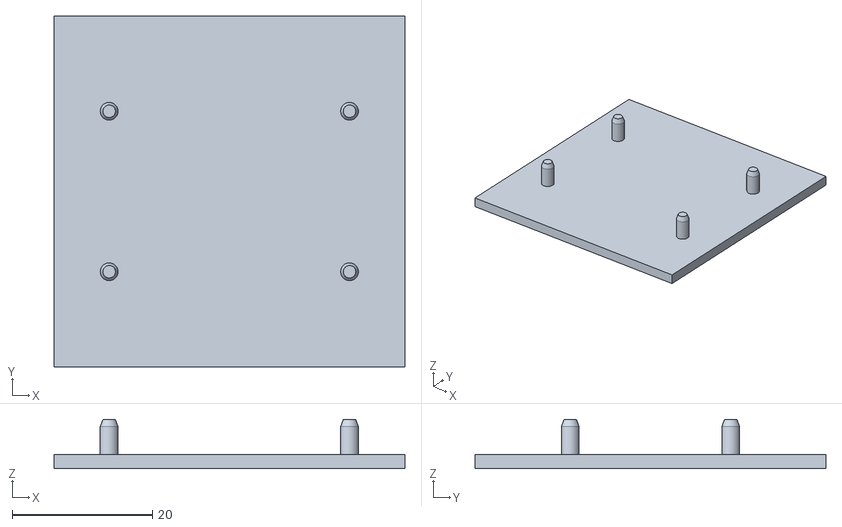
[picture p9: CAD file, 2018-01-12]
Blender3d_Files/femtoBeacon_dongle_r2.0.6_SOLDER_PASTE_JIG-Cube.stl
50.0 x 50.0 x 7.00

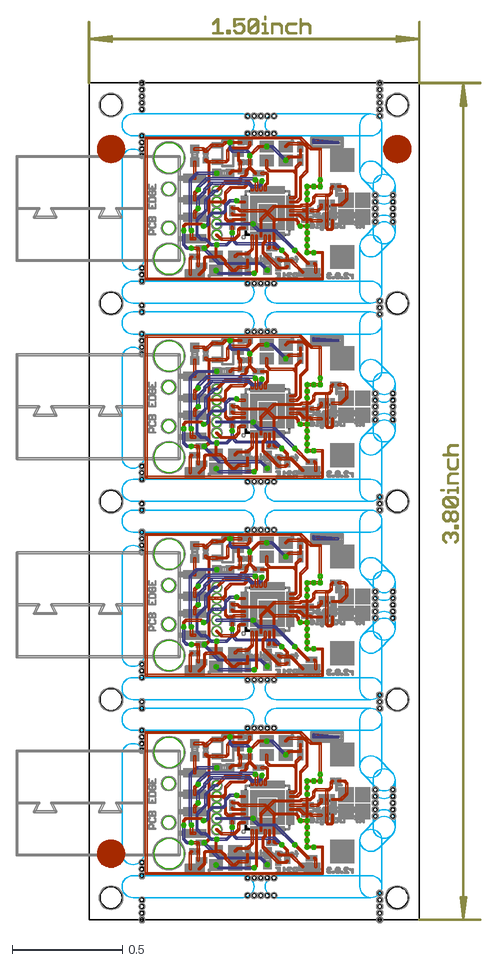
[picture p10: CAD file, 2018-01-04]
Eagle_Files/FemtoBeacon_r2.0.0/fabrication_femtoBeacon_Dongle_r2.0.3_PANELIZED/femtoBeacon_dongle_r2.0.3_PANELIZED.dxf
2.11 x 4.12

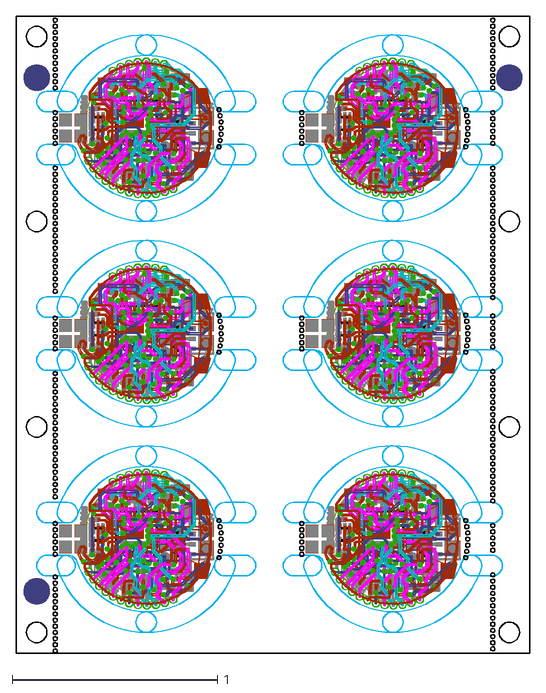
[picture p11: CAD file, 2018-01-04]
Eagle_Files/FemtoBeacon_r2.0.0/fabrication_femtoBeacon_r2.0.3/femtoBeacon_r2.0.3_PANELIZED.dxf
2.50 x 3.10

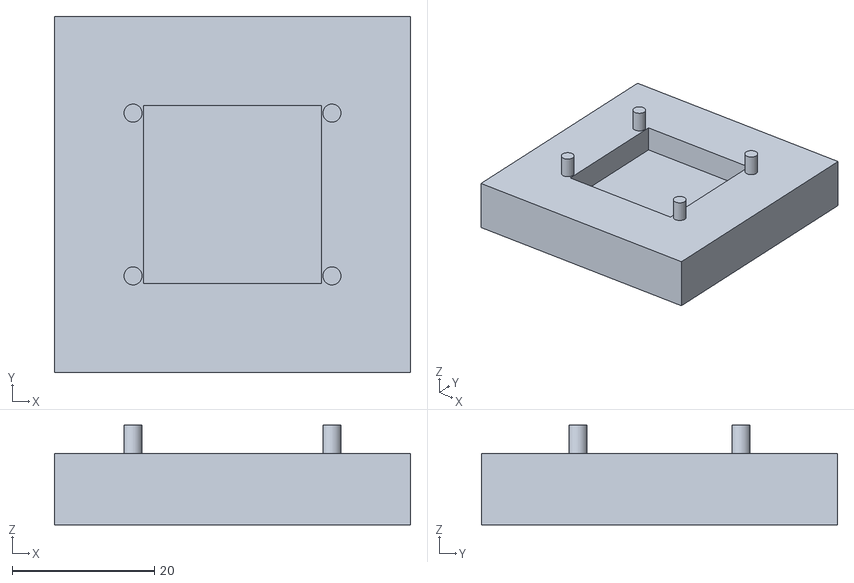
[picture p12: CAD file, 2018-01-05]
Blender3d_Files/femtoBeacon_r2.0.7_SOLDER_PASTE_JIG-Cube_001.stl
50.0 x 50.0 x 14.0

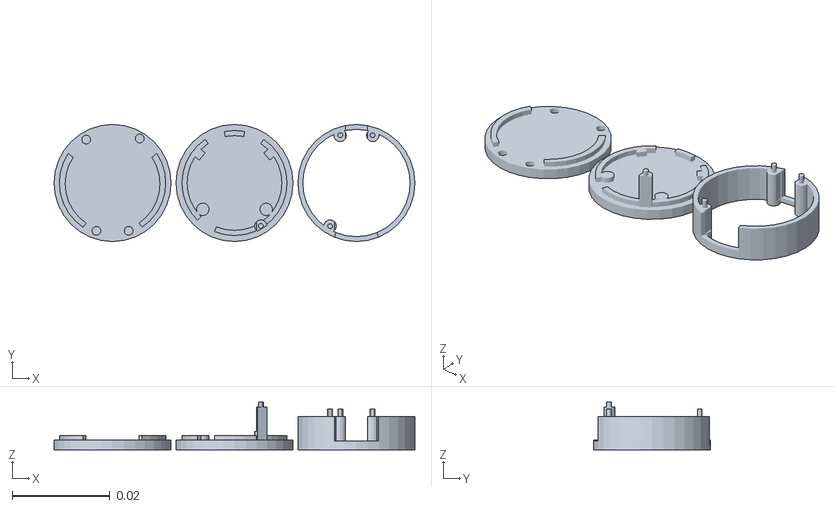
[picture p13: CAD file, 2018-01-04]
Blender3d_Files/femtoBeacon_r2.0.3_casing_v0.0.2-Cylinder_009.stl
0.074 x 0.024 x 0.0098

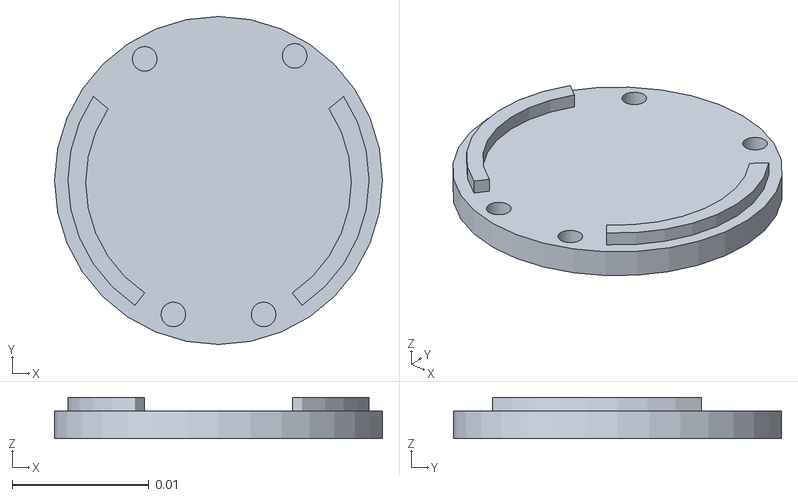
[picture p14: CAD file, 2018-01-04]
Blender3d_Files/femtoBeacon_r2.0.3_LID_TOP_v0.0.2-Cylinder.stl
0.024 x 0.024 x 0.003

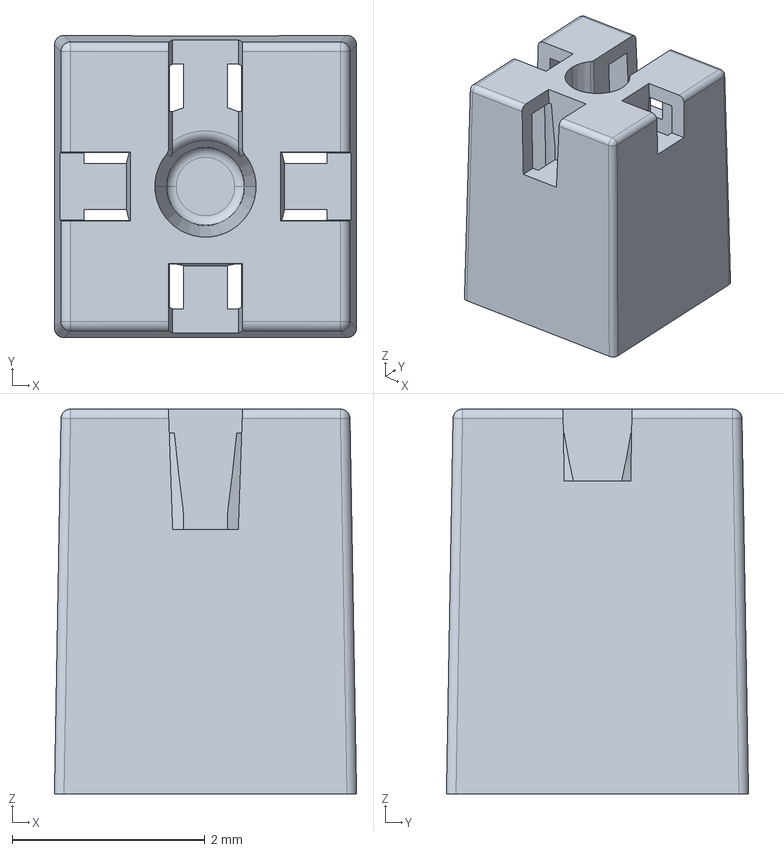
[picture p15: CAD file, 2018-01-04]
Blender3d_Files/479480001-molex-2.4GHz-smd-omnidirectional.stp
3.14 x 3.14 x 4.00 mm

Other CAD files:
Blender3d_Files/femtoBeacon_r2.0.3_casing_v0.0.2-Cylinder_010.stl
Blender3d_Files/479480001-molex-2.4GHz-smd-omnidirectional.igs
Blender3d_Files/479480001-molex-2.4GHz-smd-omnidirectional.prt
Blender3d_Files/femtoBeacon_dongle_r2.0.6_SOLDER_PASTE_JIG.blend
Blender3d_Files/femtoBeacon_r2.0.3.blend
Blender3d_Files/femtoBeacon_r2.0.3_casing_v0.0.2.blend
Blender3d_Files/femtoBeacon_r2.0.7_SOLDER_PASTE_JIG.blend

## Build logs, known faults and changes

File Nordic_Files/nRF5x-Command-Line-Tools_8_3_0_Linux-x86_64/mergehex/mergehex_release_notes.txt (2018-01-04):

Release 8.3.0
Changelog
---------------------------------------
- No changes, updated to synchronize with nRFTools.

Release 8.2.0
Changelog
---------------------------------------
- OSX support.

Release 8.1.0
Changelog
---------------------------------------
- No changes, updated to synchronize with nRFTools.

Release 8.0.0
Changelog
---------------------------------------
- Linux support.

Release 7.6.0
Changelog
---------------------------------------
- Updated the help.

Release 7.5.2
Changelog
---------------------------------------
- No changes, updated to synchronize with nRFTools

Release 7.5.1
Changelog
---------------------------------------
- No changes, updated to synchronize with nRFTools

Release 7.5.0
Changelog
---------------------------------------
- Added the possibility of a third hex file to merge in the same command.

Release 7.2.0
Changelog
---------------------------------------
- Adapted mergehex to nRF52 devices.
- Solved some bugs in parsing of the arguments.

Release 1.1.4
Changelog
---------------------------------------
- Modified a library. No change in  functionality.

Release 1.1.3
Changelog
---------------------------------------
- Modified a library. No change in  functionality.

Release 1.1.2
Changelog
---------------------------------------
- Modified a library. No change in  functionality.

Release 1.1.1
Changelog
---------------------------------------
- Corrected a minor typo in the help.

Release 1.1.0
Changelog
---------------------------------------
- Cleaned up general structure, and use the facilities existing developed for nrfjprog. 
    It should now be faster to merge two files.

Release 1.0.0
Changelog
---------------------------------------
- First version of Mergehex.exe

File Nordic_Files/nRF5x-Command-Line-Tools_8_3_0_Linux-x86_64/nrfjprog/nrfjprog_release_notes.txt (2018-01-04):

Release 8.3.0
Changelog
---------------------------------------
- (Exe)     Fixed bug in parsing a hex file in --program and --verify when hex file contained a line with less than 4 bytes of data.

- (Dll)     Improved write() function to handle non multiple of 4 write lengths.
- (Dll)     Added NRFJPROG_rtt_is_control_block_found() function.
- (Dll)     Fixed bug in NRFJPROG_rtt_stop(). If the sequence NRFJPROG_rtt_start() -> NRFJPROG_rtt_stop() -> NRFJPROG_rtt_start() was executed, the second
            NRFJPROG_rtt_start () only searched for the RTT Control Block in the address the block was found in the first NRFJPROG_rtt_start().  The side-effect  
            of this fix is that if you were performing NRFJPROG_rtt_start() -> NRFJPROG_rtt_stop() -> NRFJPROG_rtt_start() with the RTT Control Block in the 
            same address, the second NRFJPROG_rtt_start() will take longer than before.
- (Dll)     Modifed the way devices are identified.

- (Python)  Change made in API.py to remove Python 3 warning of deprecated os function call.
- (Python)  Added rtt_is_control_block_found() function.

Release 8.2.0
Changelog
---------------------------------------
- (Dll)     Corrected header file documentation for function NRFJPROG_disconnect_from_emulator(). One possible return value for nRF52 devices was missing.

Changelog
---------------------------------------
- (WindowsRelease)    Updated Segger JLinkARM installer to Setup_JLinkV510i.exe

- (OSXRelease)  Added OSX release in nRF5x-Command-Line-Tools_8_2_0_OSX.tar

- (Exe)     Ported to OSX.
- (Exe)     Fixed bug in --recover for NRF52 devices.
- (Exe)     Fixed bug in --reset and --run. The CPU core was halted some ms after the operation took effect and restarted restart later.

- (Dll)     Ported to OSX.
- (Dll)     Fixed bug in NRFJPROG_recover() function for NRF52 devices.

- (Python)  Ported to OSX.
- (Python)  Added object MultiAPI to be able to debug more than one device at the same time.
- (Python)  Fixed bug in get_latest_dll() in file JLink.py. In Python 3 this function failed because you cannot compare an int to a string.

Release 8.1.0
Changelog
---------------------------------------
- (Exe)     Eliminated sys_reset when performing --erasepage operation.
- (Exe)     Fixed small bug in --memrd. If the device was an nRF52 EngA version, the checking of the power state of the RAM was wrong. See Errata-65 for nRF52 devices for details.
- (Exe)     Fixed small bug in --memwr. If the device was an nRF52 EngA version, the checking of the power state of the RAM was wrong. See Errata-65 for nRF52 devices for details.
- (Exe)     Fixed small bug in --ramwr. If the device was an nRF52 EngA version, the checking of the power state of the RAM was wrong. See Errata-65 for nRF52 devices for details.

- (Dll)     Added NRFJPROG_step() function.
- (Dll)     Updated commentary in NRFJPROG_unpower_ram_section() function. Referenced Errata-65 for nRF52 devices EngA version.
- (Dll)     Updated commentary in NRFJPROG_is_ram_powered() function. Referenced Errata-65 for nRF52 devices EngA version.

- (Python)  Added step() function.
- (Python)  Fixed mix of tabs and spaces in program_multiple_hex_files.py.

Release 8.0.0
Changelog
---------------------------------------
- (WindowsRelease)    Renamed installer to nRF5x-Command-Line-Tools_x_x_x_Installer.exe.
- (WindowsRelease)    Added nrfjprog.h to release.
- (WindowsRelease)    Updated installer to Setup_JLinkV510d.exe

- (LinuxRelease)    Added nrfjprog.h to release. 
- (LinuxRelease)    Changed structure of release. 
- (LinuxRelease)    Included 32-bit versions of tools.

- (Exe)     Fixed bug in --sectoranduicrerase option for NRF51.
- (Exe)     Changed how shared libraries are found on Linux.
- (Exe)     Fixed minor bug in Segger JLinkARM dll version when minor version was 0x in --version.
- (Exe)     Added 32-bit support for Linux.
- (Exe)     Updated help text for clockspeed option.
- (Exe)     Added --debugreset option.
- (exe)     Improved detection of error in --family parameter.

- (Dll)     Fixed bug in enum_emu_snr() and connect_to_emu_without_snr(). Could sometimes cause a freeze of the Segger emulator.
- (Dll)     Sped up read_u32() and write_u32() functions.
- (Dll)     Added functions for RTT.
- (Dll)     Renamed exported functions to avoid collision with a C++ library in OSX.
- (Dll)     Renamed device NRF52_FP1_MPW3 to NRF52_FP1_ENGA and NRF52_FP1 to NRF52_FP1_ENGB.
- (Dll)     Added device NRF52_FP1.
- (Dll)     Added 32-bit support for Linux.
- (Dll)     Changed JLINKARM_SWD_MAX_SPEED_KHZ from 12000 to 50000.
- (Dll)     Change all functions calls that are with connection to the device to return a new error if the device is not of the family used in open_dll() function.

- (Python)  Added functions for RTT.
- (Python)  Adapted to name change in exported functions.
- (Python)  Changed location of dll in installation.
- (Python)  Renamed DeviceVersion enumerations NRF52_FP1_MPW3 to NRF52_FP1_ENGA and NRF52_FP1 to NRF52_FP1_ENGB.
- (Python)  Added DeviceVersion enumeration NRF52_FP1.
- (Python)  Added 32-bit support for Linux.
- (Python)  Added debug_reset function.
- (Python)  Added new error from the dll.
- (Python)  Updated examples to changes from the dll.
- (Python)  In Windows, JLink.py now finds most recent JLinkARM.dll in default SEGGER directory when folders other than Jlink software packs are present.

Release 7.7.0
Changelog
---------------------------------------
- (Exe)     Ported to linux.
- (Exe)     Clockspeed default is now read from the nrfjprog.ini file.

- (Dll)     Ported to linux.
- (Dll)     Added fix for write function for FPGA problem.

- (Python)  Ported to linux.
- (Python)  Changed import of nrfjprog dll from ordinal linking to symbolic linking.

Release 7.6.0
Changelog
---------------------------------------
- (Bundle)  Updated installer to Setup_JLinkV502.exe

- (Exe)     Added --sectoranduicrerase for --program operations and NRF52.
- (Exe)     Added --verify as a stand alone operation.
- (Exe)     Improved the --help output.

- (Dll)     Updated minimum JLinkARM.dll version to 5.02.
- (Dll)     Eliminated disabling of Supply Power to device in connexion to the emulator.
- (Dll)     Cleared the header commentaries.

- (Python)  Added new example for pynrfjprog (program_multiple_hex_files.py).
- (Python)  Updated hex files used by program_hex.py to work on development boards.
- (Python)  Cleared the commentaries.

Release 7.5.2
Changelog
---------------------------------------
- (Exe)     Changed functionality of --program --sectorerase with respects to UICR.

- (Dll)     Fixed problem in dll closing.

Release 7.5.1
Changelog
---------------------------------------
- (Exe)     Fixed problem with programming files whose length of segments were not multiple of 4.
- (Exe)     Eliminated --clean option in --program.
- (Exe)     Added --chiperase and --sectorerase in --program.

- (Dll)     Added disabling of trace resources when disconnecting.
- (Dll)     Improved speed.
- (Dll)     Corrected problems in recover() for nrf52.
- (Dll)     Corrected problems in pin_reset() for nrf52.
- (Dll)     Workaround for Errata 44 "Read flash after erase is unpredictable" added for nrf52.

- (Python)  Added BSD license to project.
- (Python)  Fixed api for function disconnect_from_emu().
- (Python)  Updated Hex.py with extended segment address.
- (Python)  Added comments and new example.

Release 7.5.0
Changelog
---------------------------------------
- (Bundle)  Updated installer to Setup_JLinkV498c.exe. Corrects a bug in OBD for our device programming.

- (Msi)     Pynrfjprog is no longer copied with nrfjprog installation. Own installation will be provided.
- (Msi)     Solved problem of installing into older versions.
- (Msi)     Added documentation folder for the release notes.
- (Msi)     Added header folder for the dll header files.

- (Exe)     Modified default family, it is now taken from nrfjprog.ini file.
- (Exe)     Modified --family and --rbp to accept the parameters in any combination of lower and upper case.
- (Exe)     Added --quiet option.
- (Exe)     Eliminated change introduced in 7.3.2 to avoid problems with our OBD. Program is fast again.
- (Exe)     Fixed bug in --eraseuicr. It could not be executed.
- (Exe)     Made return codes for nrfjprog POSIX compliant.
- (Exe)     Added --erasepage function.
- (Exe)     Eliminated --erasecode function.
- (Exe)     Enforcing that PC address in --run must be thumb mode.
- (Exe)     It is now possible to make unaligned reads. Default width depends on the alignment.
- (Exe)     Fixed bug in --ficrwr. It will not masserase if it is not necessary.
- (Exe)     Modified --memwr so it fails if the area to write is not erased.

- (Dll)     Renamed power_ram() function to power_ram_all().
- (Dll)     Added unpower_ram_section() function.
- (Dll)     Modified read() function so addresses no longer need to be word aligned.
- (Dll)     Corrected bug in readback_protect for XLR and XLR2 devices.

- (Python)  Adapted to dll api changes.
- (Python)  Eliminated Enums.py. Used library available in Python 2.7.9 enum34. Installed automatically by the egg.
- (Python)  Eliminated unnecessary check for length 0 in read(). The dll already takes care of that case.
- (Python)  Added header files to the egg.
- (Python)  Added examples to egg.
- (Python)  Moved headers to own folder.

Release 7.4.0
Changelog
---------------------------------------
- (Bundle)  Updated installer to Setup_JLinkV498b.exe
- (Exe)     Corrected bug introduced in 7.2.2 release. -d will reset the device and run.
- (Exe)     Eliminated --disablepinreset and --enablepinreset. The functionality is not going to be present in the ASIC.
- (Dll)     Updated minimum JLinkARM.dll version to 4.98.
- (Dll)     Extending waiting time for NVMC operations hundredfold. Some operations were failing.
- (Dll)     Eliminated disable_pin_reset() and enable_pin_reset(). The functionality is not going to be present in the ASIC.
- (Dll)     Eliminated read_debug_register(). Added read_debug_port_register() and read_access_port_register() instead.
- (Dll)     Eliminated write_debug_register(). Added write_debug_port_register() and write_access_port_register() instead.
- (Python)  Adapted to dll api changes.
- (Python)  Added JLink.py that helps in finding the latest dll.
- (Python)  Modified open() function api. Eliminated redundant parameter, since the constructor already receives it.

Release 7.3.2
Changelog
---------------------------------------
- (Exe)     Fixed bug in --program for NRF51 introduced in 7.3.1
- (Exe)     Modified --program to avoid problems with the OBD debugger in our boards. Side effect is that now program uses more time.

Release 7.3.1
Changelog
---------------------------------------
- (Exe)     Adapted for NRF52_FP1.
- (Dll)     Eliminated all use of pin_reset() for NRF52. It might not be enabled in the UICR.
- (Dll)     Added NRF52_FP1 type device.
- (Python)  Make a proper package installation for pynrfjprog.

Release 7.2.3
Changelog
---------------------------------------
- (Exe)     Corrected bug introduced in 7.2.2 release. -r and -p will reset the device and run. all other operations will not.
- (Python)  Optimized Hex.py to accelerate downloading.

Release 7.2.2
Changelog
---------------------------------------
- (Exe)     Corrected serious bug. When closing the core was restarted. If there was no code in the device, a hardfault and lockup reset was produced, resetting the device and clearing write operations.

Release 7.2.1
Changelog
---------------------------------------
- (Exe)     Corrected serious bug. When the Dll returned error, the close_dll() function was not called. After several errors the Segger emulator needed to be unpowered since there were too many connexions open to it.
- (Exe)     Corrected minor bug. After erasing an nRF51 device protected by MPU, a reset was not performed, so the device still thought it was protected. A sys_reset is performed after --eraseall and --clean during program.

Release 7.2.0
Changelog
---------------------------------------
- (Exe)     Renamed --rawwr to --ramwr.
- (Dll)     recover() functions now switches on all RAM.
- (Dll)     Segger debugger unpowers the debug port when close_dll() is called.
- (Python)  Added Hex.py to parse hex files to use with API.API.write function.

Release 7.1.0
Changelog
---------------------------------------
- (Exe) Added --clean option to --program. --clean erases all user available flash (including UICR).
- (Exe) RAM is turned on in the --program operation.
- (Exe) Added error and corresponding user feedback for a too old version of JLinkARM.dll used in the machine.
- (Exe) Added warning when --family is not used.
- (Exe) A --memrd, --memwr, --rawwr and --readram will fail if the target RAM is unpowered.
- (Dll) Added function is_ram_powered().
- (Dll) Added function power_ram().
- (Dll) Added function read_debug_register().
- (Dll) Added function write_debug_register().
- (Dll) Function open_dll() returns new error JLINKARM_DLL_TOO_OLD.
- (Dll) Fixed connexion problems under certain circumstances. Device selection was missing.
- (Dll) Fixed caching problems when reading after erase.

Release 7.0.0
Changelog
---------------------------------------
- (Exe) Added support for NRF52. In order to accomplish this, required option --family is added.
- (Exe) Added used JLinkARM.dll version to --version output.
- (Exe) Simplified interface. No longer is possible to concatenate program, erase and reset operations.
- (Exe) Simplified interface. Eliminated all options that dealt with SoftDevice: --programs, --recovers, --eraseapp, --erasecr1 and --programapp.
- (Exe) Simplified interface. --program can no longer have two hex files as parameters.
- (Exe) --program does not automatically erase target area. --clean option added to --program to erase all flash (same as --eraseall) before programming.
- (Exe) Eliminated --quiet option.
- (Exe) Eliminated --logids option. Use pipes for the same effect.
- (Exe) Eliminated deprecated option --dso.
- (Exe) Modified --eraseall. Now it erases all user available flash. It will automatically handle SoftDevice programmed at Nordic factory.
- (Exe) Added --erasecode operation.
- (Exe) Eliminated --erasepage operation.
- (Exe) Eliminated --hexuicrinfo operation.
- (Exe) Memory operations do not automatically check result. Added --verify for verification. Eliminated --ramwr since it does not have sense any more.
- (Dll) Published dll interface and python bindings for use by customer.

Release 5.1.3
Changelog
---------------------------------------
- (Micro) Now nrfjprog.dll and nrfjprog.exe versions upgrade together.

Release 5.1.1
Changelog
---------------------------------------
- (Major) Corrected error with --dfu option of --programs.

Release 5.1.0
Changelog
---------------------------------------
- (Dll.Minor) Eliminated all pop-ups.
- (Dll.Micro) Corrected minor error in loading several JLinkARM.dll functions that were not used.
- (Dll.Micro) Added loading of JLinkARM.dll GetHWInfo() function.

Release 5.0.1
Changelog
---------------------------------------
- (EXE.Micro) Corrected bug in new SDV download (SDV.hex does not contain UICR values). Version 5.0.0 is useless for the purpose it was intended.

Release 5.0.0
Changelog
---------------------------------------
- (EXE.Major) Changed to look for the location of the nrfjprog.dll in the local directory of the executable, not in the registry.
- (EXE.Major) Adapted --recovers, --eraseapp,  --eraseall, --eraseuicr, --erasecr1, programapp and --programs to take into account the new SDV Info struct and maybe no protection.
- (EXE.Minor) Eliminated options --clenr0 and --fwid to --programs.
- (EXE.Micro) Added several parameters for the SoftDevice information. Memory buffers now take into account the size of the SDV, not of region 0.
- (EXE.Micro) Cleaned --ids and --logids to prepare for future changes.
- (EXE.Micro) Cleaned the initialization of path strings.
- (EXE.Micro) Corrected the feedback with incompatible arguments in the --help option.
- (EXE.Micro) Corrected the loading of the nrfjprog dll library. It now occurs with LoadLibraryW as it should.
- (DLL.Major) Added new function read_softdevice_info().
- (DLL.Micro) Corrected minor bug in length of the m_jlink_arm_dll_path array.
- (DLL.Micro) Eliminated extra popup window when disabling system off.
- (DLL.Micro) Changed default value for no emulator selected.
- (DLL.Micro) Disabled caching of the flash.

Release 4.0.5
Changelog
---------------------------------------
- (Micro) Adapted to XLR3+ device.
- (Micro) UICR is not read from the device when programming unless the hex file(s) provided have UICR. Speeds programming.

Release 4.0.4
Changelog
---------------------------------------
- (Micro) Optimized the dynamic memory allocation and deallocation.
- (Micro) Optimized the information functions to DeviceInfo.
- (DLL) Made function pin_reset_ignore_pall work for Quark MPW1.

Release 4.0.3
Changelog
---------------------------------------
- (Micro) Eliminated some safety check that was not needed.
- (Micro) Eliminated a deprecated safety check.
- (Micro) For some device FICR and UICR sizes and code page sizes are different. Now really changed everywhere.

Release 4.0.2
Changelog
---------------------------------------
- (Micro) For some device FICR and UICR sizes and code page sizes are different. Changed everywhere.

Release 4.0.1
Changelog
---------------------------------------
- (DLL)   Fixed problem identifying MPW1.
- (DLL)   Added a lot of functionality related to the MPU to the nrf51dll.dll.

Release 4.0.0
Changelog
---------------------------------------
- (DLL)   Adapted to deprecation in SIZERAMBLOCK[i] registers.
- (Major) Added Quark MPW1 as one of the valid devices.
- (Micro) Eliminated several bugs in parsing the page number in --erasepage.
- (Micro) Added some formating to log.log and error.log so we can see the different commands. Command line is also written.
- (Micro) Corrected default values of RAM and Flash size depending on the device.

Release 3.1.1
Changelog
---------------------------------------
- (DLL)   --pinreset makes now a system reset, halts and then pinresets to avoid a problem with emulated system off.
- (Micro) System Reset is perfrom before any erase operations to avoid problems with emulated system off.

Release 3.1.0
Changelog
---------------------------------------
- (DLL)   Added function check_region_access_ignore_protenset.
- (DLL)   Hardcoded protenset to 4kb as is in XLR2, XLR3 and L3.
- (DLL)   Solved problem with download of programs in XLR in certain circumstances. RAM was off after certain resets.
- (Minor) Added --halt option.
- (Minor) Disable protenset during a memory write operation will only happen during a --memwr to flash area.
- (Micro) Added some information to the help of erase and program operations.
- (Micro) Disable protenset during a program operation will only happen if there is a download to flash area.
- (Micro) Disable protenset will not happen during check flash region access operations.

Release 3.0.1
Changelog
---------------------------------------
- (Micro) Corrected typo in --programs help.

Release 3.0.0
Changelog
---------------------------------------
- (Major) Pin reset and reset cannot be combined.
- (Major) Added --deviceversion option.
- (Minor) Improved recover operation again.
- (Minor) Now --help and --version can be combined.
- (Minor) Corrected error with --pinreset when we have just protected with PALL.
- (Minor) Improved all erase operations, including adding system reset after them.
- (Minor) Added check for PALL protection before programming.
- (Minor) Better check for UICR conflicts when programming.
- (Micro) Corrected bug in programming under weird circunstances. Probably nobody hit this error.
- (Micro) Corrected typo in name of our company.
- (Micro) Cleaned up the calls for the information functions.
- (Micro) Corrected bug with pinreset when PALL. Now I inform the user that it may not work.
- (Micro) Eliminated bug, by checking PALL before calling disable_proten.
- (Micro) Corrected several errors in --programapp check for correctness.
- (Micro) Corrected bug in fwid option.
- (Micro) Updated device info after erasing.
- (Micro) Using default values for flash and ram sizes if the FICR is a little wrong.
- (Micro) Corrected bug in --fwid option check.
- (Micro) Corrected bug --recovers and --eraseapp. BOOTLOADERADDR in UICR was not being erased.
- (Micro) Corrected return value when only a secondary argument is given.
- (Micro) Corrected bug in --recovers.
- (Micro) Corrected bug in --memwr, --ramwr and --rawwr trying to write into FICR area.
- (Micro) Improve feedback on failed --recover.
- (Micro) Corrected small bug with --memrd and wrong --n parameter.
- (Micro) Corrected error when --memwr and PALL for certain registers.

Release 2.6.0
Changelog
---------------------------------------
- (Minor) Improved recover operation. Several attempts are made to recover the device, not just one.
- (Micro) Corrected some erros in error reporting.

Release 2.5.0
Changelog
---------------------------------------
- Clarified error messages and help of --programs.
- Added --fwid secondary option to --programs option.
- Corrected minor bug in --logids activity report.
- Corrected typo in error MisalignedOperation name.
- Corrected minor typo in --version report.
- Improved --ficrwritereg to avoid the erasing when only 1s are changed.
- Corrected typos in error reporting.
- Provided warnings with meaningless erase operations in the presence of --eraseall.
- UICR locations to download are checked during --program, --programapp and --programs to see if they are erased.
    If not, it will give an error.
- Removed bug in --ficrwritereg CLENR0 values.

Release 2.4.0
Changelog
---------------------------------------
- Corrected help for coderead.
- Added hexdump printing to memrd functionality.
- Corrected 2 typos in user feedback printing.
- Correct error in --quiet option. One command was not quiet.
- Provided popup window if several devices are present but none is sellected by -s or --snr in options.

Release 2.2.0
Changelog
---------------------------------------
- Corrected bug in --program checking the last byte is in code.
- Added --readregs function into the nrfjprog.
- Improved the check of the erased region when programming.

Release 2.1.1
Changelog
---------------------------------------
- Corrected bug in --readcode under certain conditions.
- Corrected bug in reporting of error in programs for missing CLENR0.

Release 2.1.0
Changelog
---------------------------------------
- Added support for old FICR files.
- Added read code area function, including checking if the user has read access tot he area requested.

Release 2.0.4
Changelog
---------------------------------------
- Registry search for the nrfjprog.dll location takes into account the version of nrfjprog.

Release 2.0.3
Changelog
---------------------------------------
- Beta release of new nrfjprog. Complete redesign of nrfjprog tool.

Release 1.0.7
Changelog
---------------------------------------
- Fixed the crash caused when using --verify option.
- --verify option speed optimized to be 4 times faster.

Release 1.0.6
Changelog
---------------------------------------
- Recompilation.

Release 1.0.5
Changelog
---------------------------------------
- Fixed a problem in --program and --programs.

Release 1.0.4
Changelog
---------------------------------------
- Fixed an incorrect parameter when reading a registry value.
- Fixed minor typos in the std out comment.
- Fixed pin reset bug.

Release 1.0.3
Changelog
---------------------------------------
- Fixed the utility to work again with WinXP-32-bit machines
- Added verify option that can verify device memory contents with given hex file.

Release 1.0.2
Changelog
---------------------------------------
- Minor bug fix.

Release 1.0.1
Changelog
---------------------------------------
- fixing bug with buffer size.

Release 1.0.0
Changelog
---------------------------------------
- Code Reviewed: Bug fixes + optimizations.
- default output for --memrd + --n option, when not using --w, is changed from 8-bit to 32-bit as that will be used more.
- adding -q --quiet option (do not print any log)
- adding --dso disable system off until next reset.
- fixing bug with pin reset that did not switch the debug mode back to SWD from JTAG

Release 0.2.5
Changelog
---------------------------------------
-- removing uicrwritereg option as same functionality can be achieved using memwr option.
-- using --memwr for non-flash addresses will not configure nvmc for write/read/erase enable.
-- adding --hexuicrinfo that reads the hex file and dumps (to stdout) UICR-> CR0, RBPCONF and/or FWID if they are to be programmed from hex file
-- changed the default J-Link speed to 10MHz (previous 1MHz) if not set expplicitly by --clockspeed option
-- added --dmemwr option, dumb write instruction to cpu. This option is not flash aware. It takes the same arguments like memwr, 

Known Issuees
----------------------
-- writing to a flash memory using --memwr option is erasing the page first before write, this is done within segger dll and this issue
   will be addressed very soon. 

Release 0.2.4
Differences from the previous release
---------------------------------------
-- implemented --w option for --memrd. you can dump values in either 8(Default). 16 or 32 bit format
-- implemented --recover option which can be used to disable system off and erase code regions and then enable system off again
       can be used to recover chips in system off without wakeup source configured

Release 0.2.3
Differences from the previous release
---------------------------------------
- fixed a bug that is causing the pop up window with multiple seggers connected and even if serial number was given as argument.

Release 0.2.2
Differences from the previous release
---------------------------------------
 - fixed bug that --n option (as in --memrd 0XSomething --n 20) was considering the number in hex, its a number of bytes
       in decimal radix 10.
 - added -p, --pinreset option to do a hard pin reset
 - adding --run option to set --pc (program counter) and --sp (stack pointer)
 - added  --hexuicrinfo    <hex_file>         Reads the hex file and dumps (to stdout) UICR-> CR0, RBPCONF and/or FWID if they are to be programmed from hex file
                                              Note: only those registers are shown whose addresses exist in the hex file
 - more bug fixes.

Release 0.2.1
Differences from the previous release
---------------------------------------
 - bug with the utility that did not work on XP (now fixed)
 - "--rbp CR0" is not allowed when CR0 is not defined in FICR or UICR. (use --clenr0 to set the CR0 first)
 - --rbp is allowed to be used with --program (application) option 
 - auto backup file extention changed from .txt to .log which are easy for auto clean operations.
 - --eraseuicr option added
 - added info that -e, --eraseall is not available for factory programmed chips
 - added more checks for eraseall and eraseuicr for factory programmed and non factory programmed.
 - added --memrd option (courtesy nrfprog, works exactly the same way)
 - added --memwr option

Release 0.2
Differences from the previous release
---------------------------------------
 - Adding -v or --version option to know the version of this utility
 - EraseAll will not do an implicit reset (but --programs will do implicit eraseall and a reset)
 - --clenr0 and/or --rbp options cannot be used with --program
 - cannot use --clenr0 option with --programs if the hex file is programming to UICR->CLENR0 
 - cannot use --rbp option with --programs if the hex file is programming to UICR->RBP
 - hex files can now contain uicr address ranges (usable only by --programs).
 - bufferring all flash segment writes so that user sees only one write operation per hex file
 - check first in the local directory for JLinkARM.dll (useful for standalone apps) before checking registry for its installed path.
 - hex files cannot contain uicr address range with --program option
 - check application base address to match CR1 base address (on protected chips), if not match then return error with flash untouched.
 - removing --bin option to keep it simple
 - added few more error codes
 - wrong serial number given as the argument will return error and the program will quit

Release 0.1.3
Differences from the previous release
----------------------------------------
 - added error codes to handle different errors and return to the caller (for error codes @ref nrfjprog.h)
 - added --rbp option to enable readback protection for cr0 and cr0+cr1
 - when using --programs option readback protection is not changed (in earlier version using this option would set RBPCONF to CR0)
 - --clenr0 option must now be used with --programs to protect the softdevice else programming softdevice will fail
 - added --readuicr option to read uicr page into given file
 - removed flashing binary file check and support for --program 
 - able to read uicr address range from hex file and write to UICR page

Release 0.1.2
differences from the previous release
---------------------------------------
 - few bug fixes
 - reducing wait time for each operation by correctly waiting on the ready flag
 - adding reset -r option (-e option does an reset implicitly)
 - added --uicrwritereg value to write to uicr register (remember only 1's can be changed to 0's)
 - Searching segger installation in HKEY_LOCAL_MACHINE also for buildservers to work properly. Segger will include
            in their next release to add a key to HKEY_LOCAL_MACHINE root

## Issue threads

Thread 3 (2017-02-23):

Help on using femto-beacon

allenyin, 2017-02-23:
Hi Femtoduino,

I bought a FemtoBeacon starter kit from Tindie (https://www.tindie.com/products/femtoduino/femtobeacon-kit-starter/?pt=full_prod_search).

I am a bit confused about the steps needed to start using them. Trying to get the /examples/sam-r21-imu to work as a start on Ubuntu14.04 in bare metal, here is what I have done so far:
1) Downloaded the Atmel Software Framework, made the symlinks as mentioned in /examples/sam-r21-imu/README.md
2) Checked out and sym-linked the MPU9250 repo
3) Installed gcc-arm-none-eabi
4) Changed in `config.mk`:   `PRJ_PATH=libraries/xdk-asf-3.33.0`
5) Changed in `Makefile`:    `MAKEFILE_PATH=libraries/xdk-asf-3.33.0/sam0/utils/make/Makefile.sam.in`

When I do `make` within the /examples/sam-r21-imu directory, I get the following error

```
CC      sam_r21_imu.o
In file included from libraries/xdk-asf-3.33.0/common2/services/delay/sam0/systick_counter.h:50:0,
                 from libraries/xdk-asf-3.33.0/common2/services/delay/delay.h:64,
                 from asf.h:60,
                 from sam_r21_imu.c:2:
libraries/xdk-asf-3.33.0/sam0/drivers/system/clock/clock.h:51:27: fatal error: clock_feature.h: No such file or directory
 #include <clock_feature.h>
                           ^
compilation terminated.
make: *** [sam_r21_imu.o] Error 1
```
I have yet to install openocd and BOSSA, but this error seems to be not related to those, probably because a change in ASF...is there a patch to this?

On another note, is installing eclipse c++ absolutely necessary?

zrecore, 2017-02-23:
If you are going to use baremetal C with the Atmel Software Framework, I would suggest going directly to the ASF examples related to the SAM R21 examples on their website. I've been using the Arduino core and bootloader instead. (See https://github.com/femtoduino/ArduinoCore-atsamd21e18a )

allenyin, 2017-02-23:
Ok, for the sake of learning, could you point me to some resources for writing libraries adapting MCUs to work within the Arduino framework?

zrecore, 2017-08-23:
@allenyin I don't know of any. I had to figure it out by grabbing a copy of the official Arduino Zero core, and asking questions in the Arduino developers google group. I really wish I knew of one, or at least had enough time/resources to make one.

Closed 2017-08-23.

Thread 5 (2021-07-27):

Multiple Sensor Nodes packet collision

jsouriadakis, 2021-07-27:
When multiple sensors are streaming their IMU data to the dongle, there is packet collision and not all packets arrive. Have you implemented any time synchronization when more sensor nodes are connected?

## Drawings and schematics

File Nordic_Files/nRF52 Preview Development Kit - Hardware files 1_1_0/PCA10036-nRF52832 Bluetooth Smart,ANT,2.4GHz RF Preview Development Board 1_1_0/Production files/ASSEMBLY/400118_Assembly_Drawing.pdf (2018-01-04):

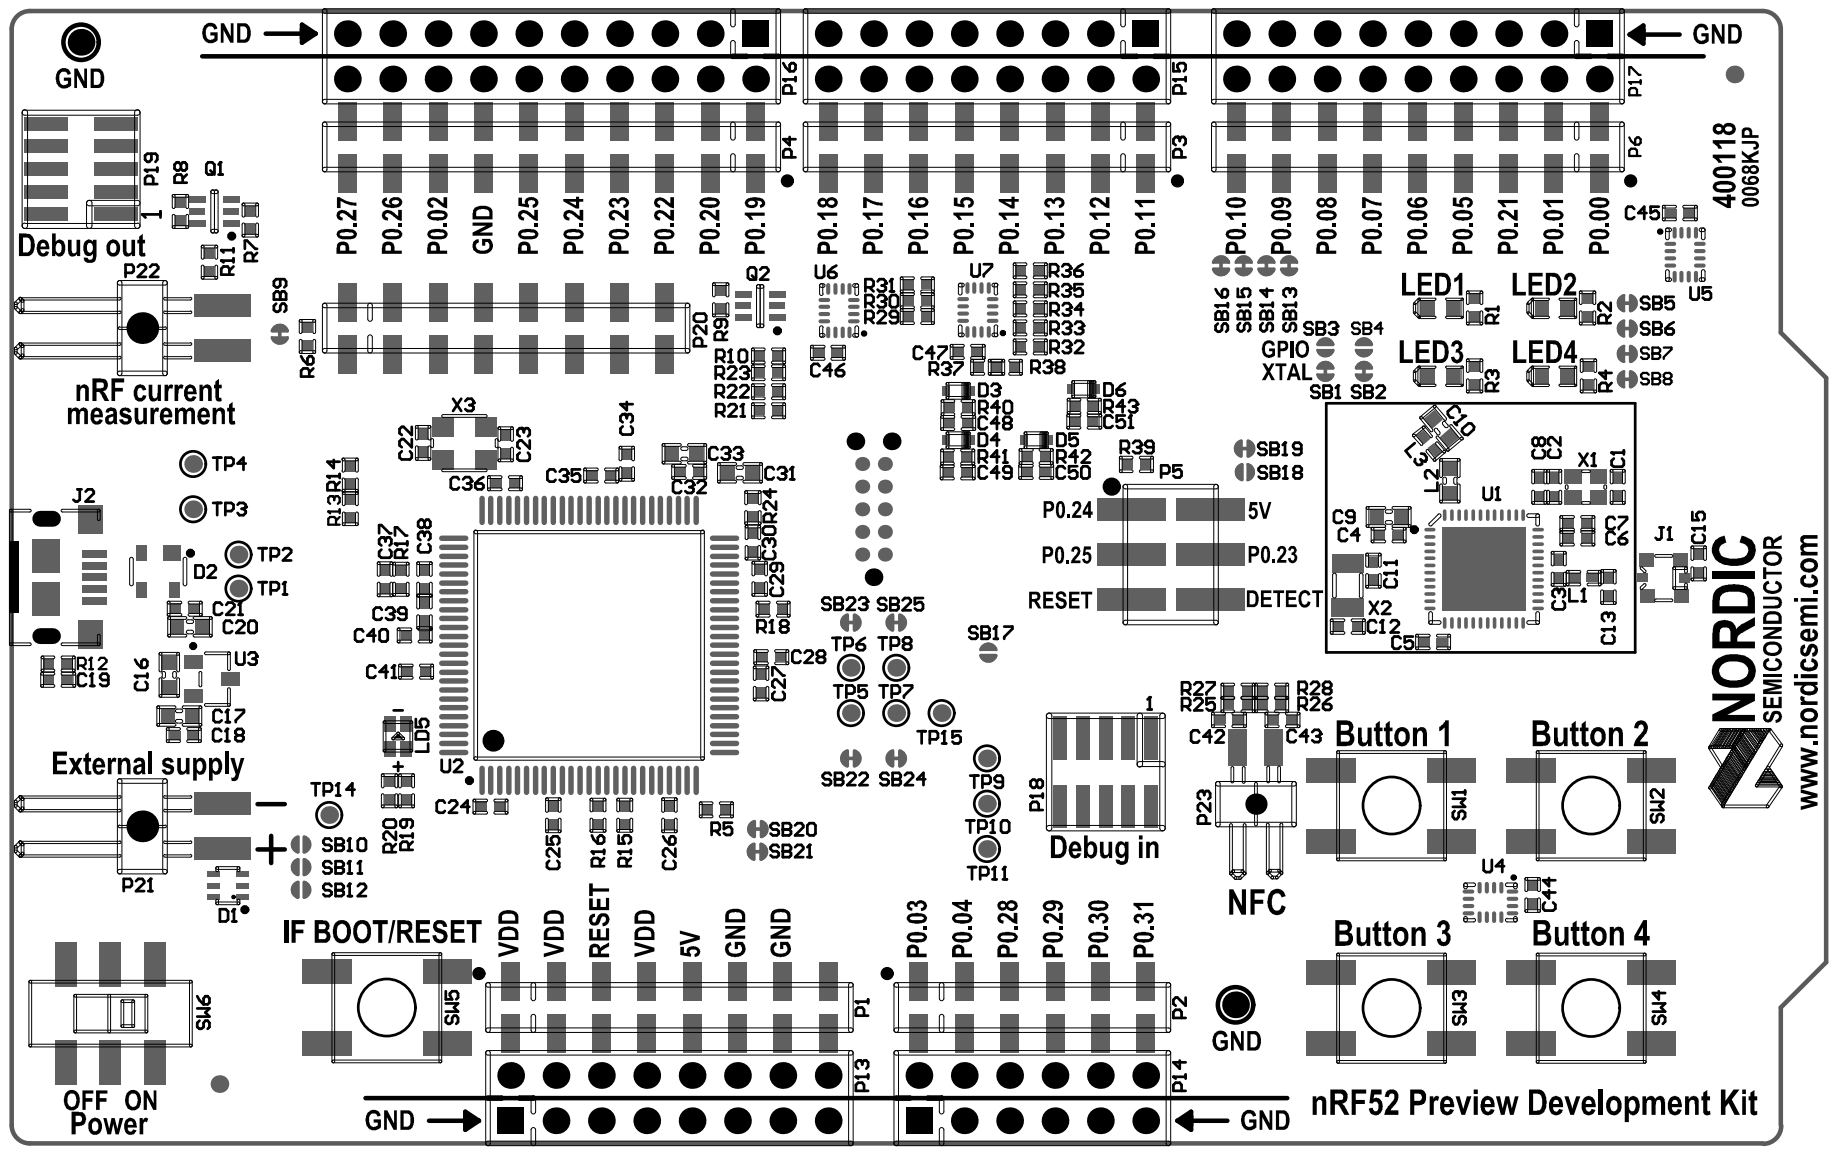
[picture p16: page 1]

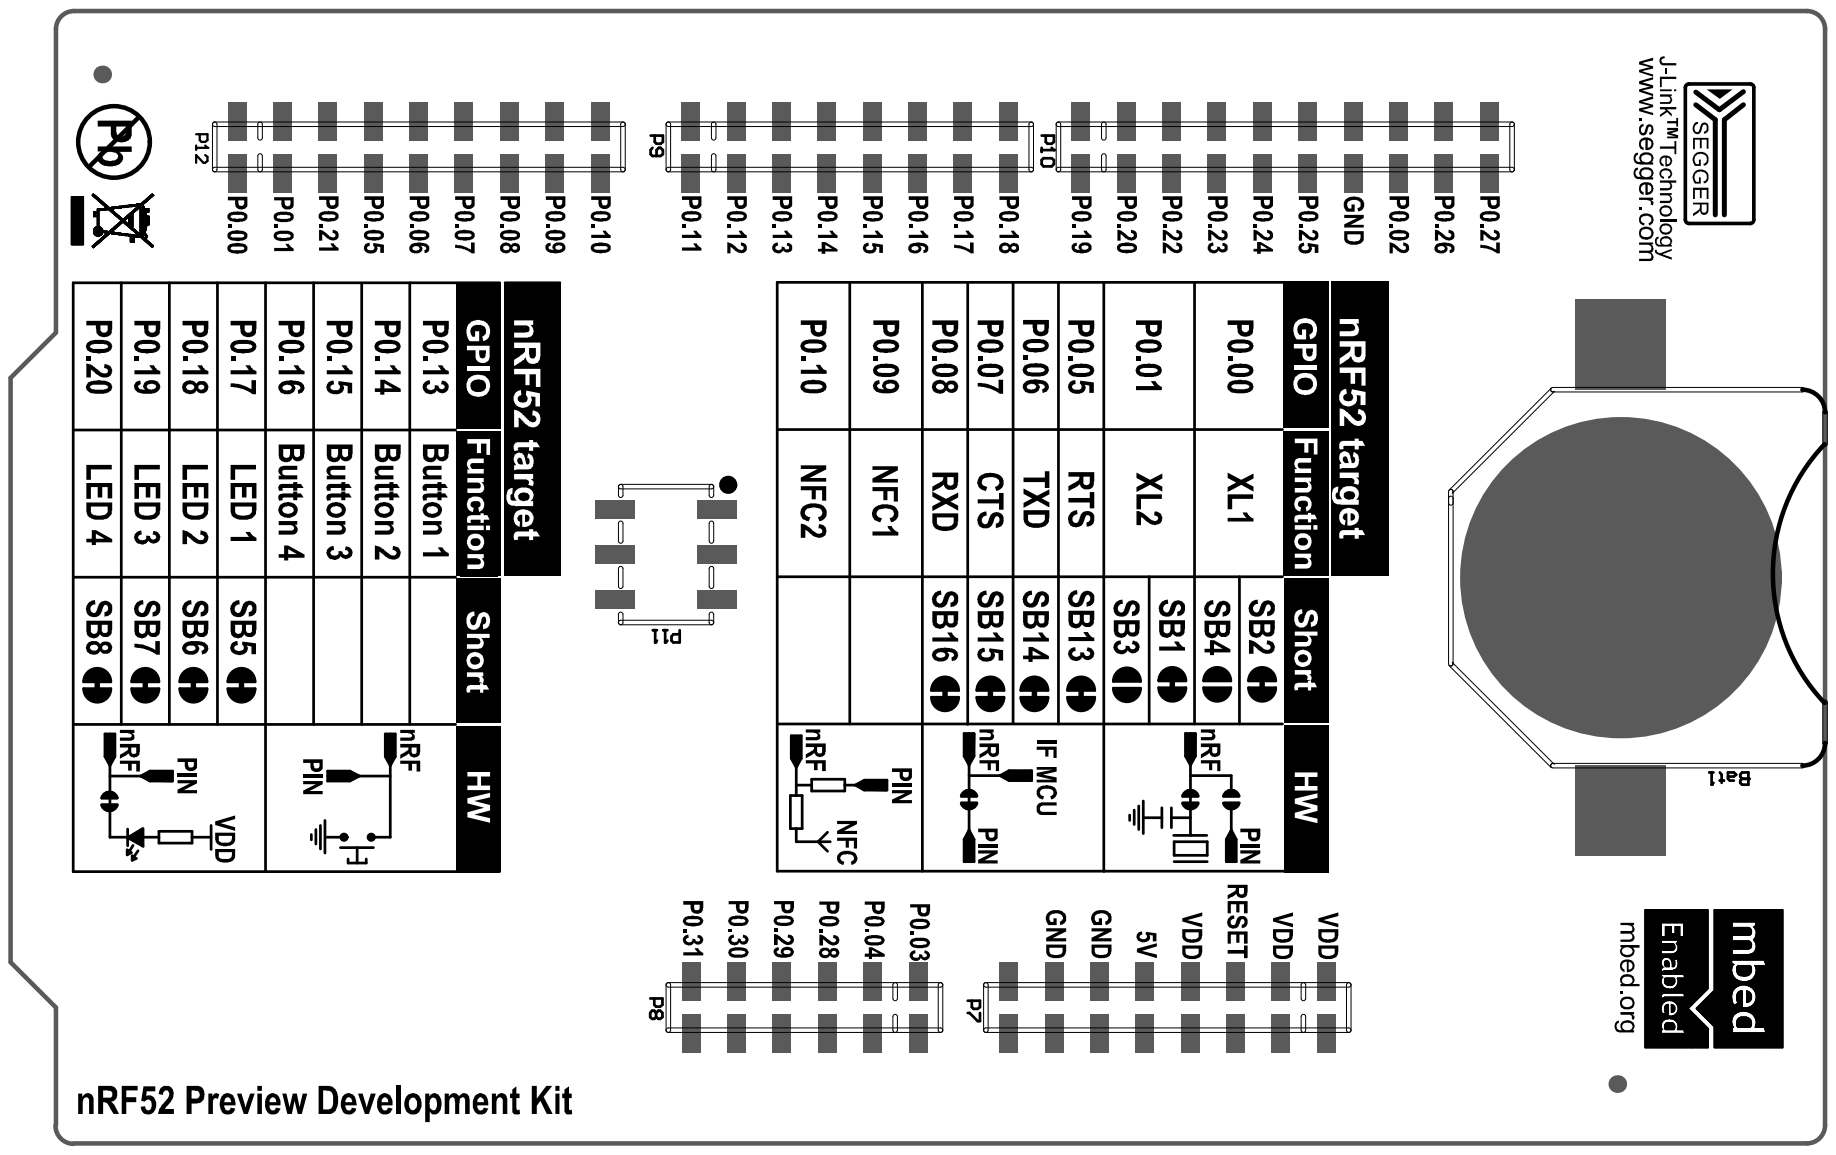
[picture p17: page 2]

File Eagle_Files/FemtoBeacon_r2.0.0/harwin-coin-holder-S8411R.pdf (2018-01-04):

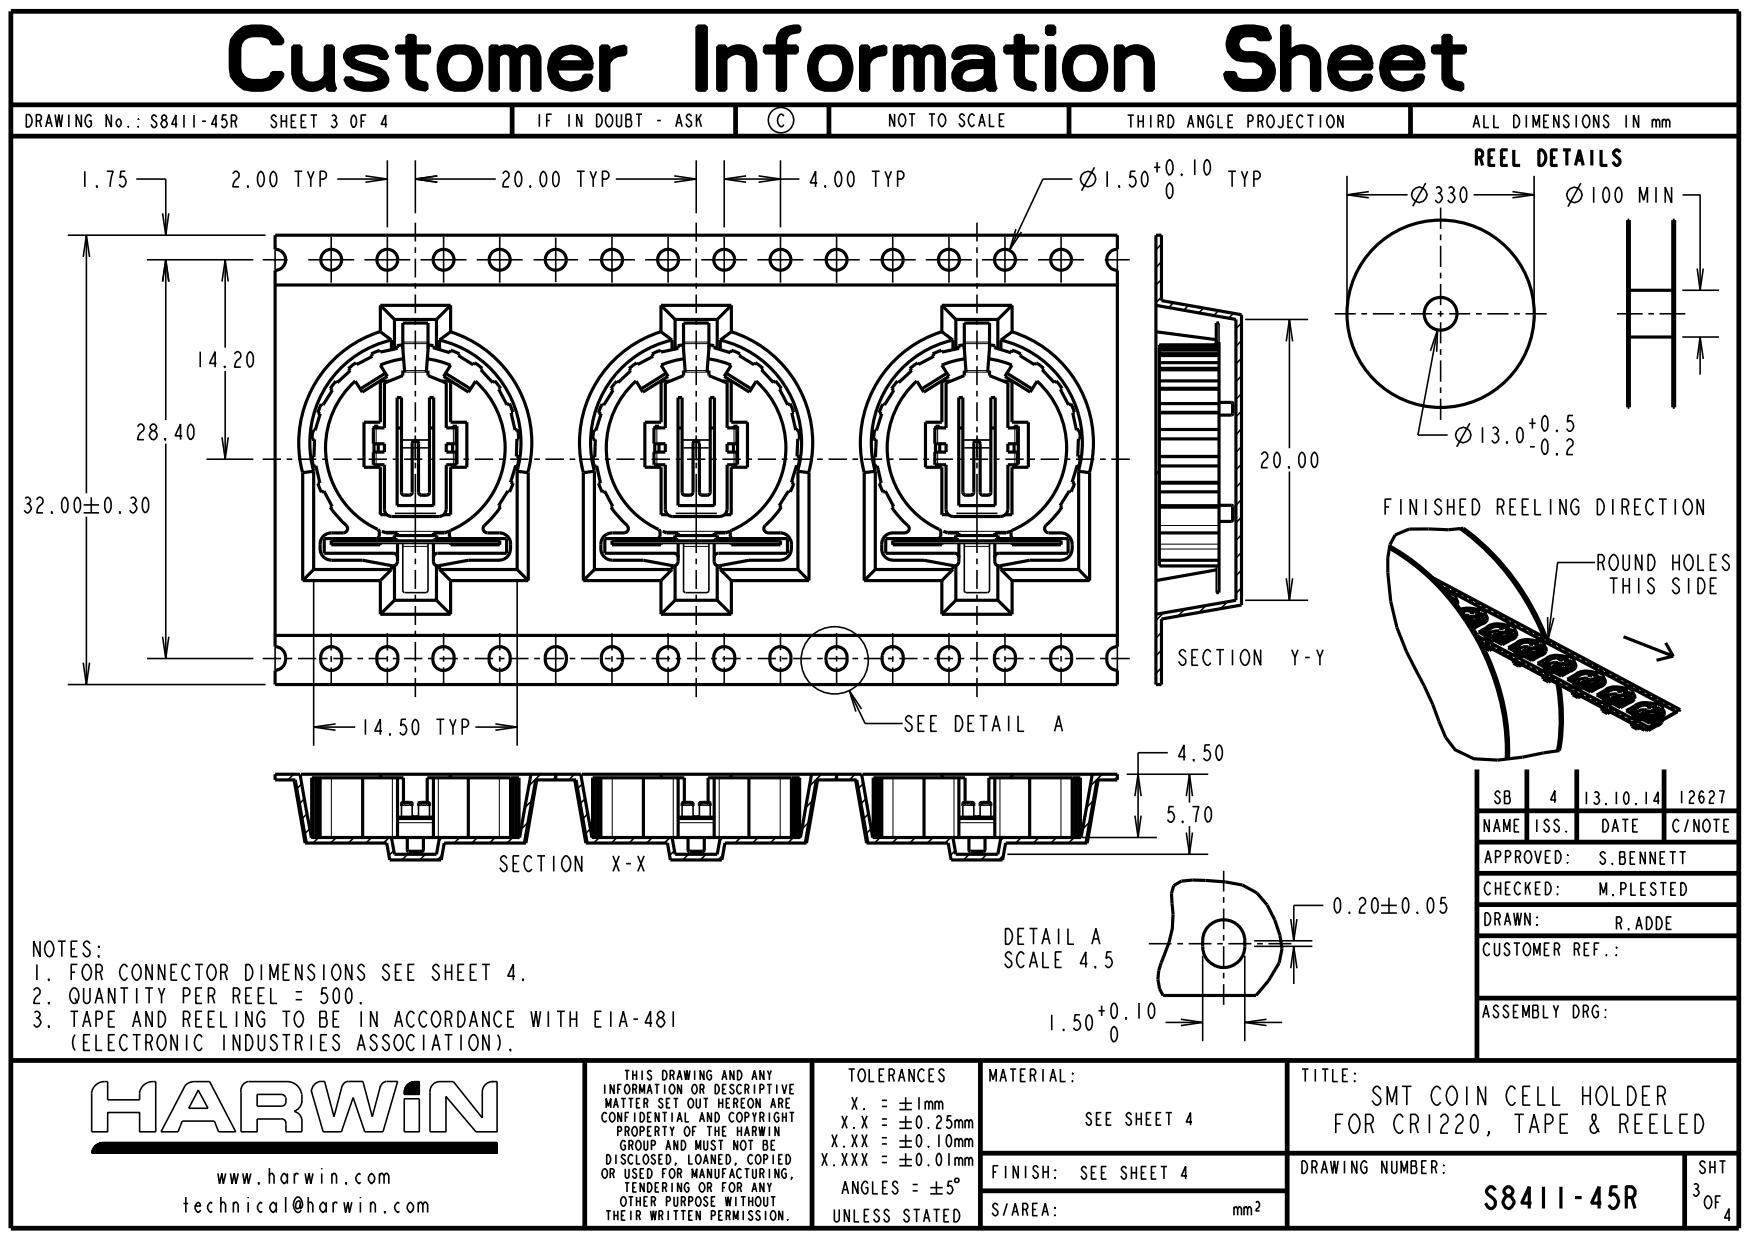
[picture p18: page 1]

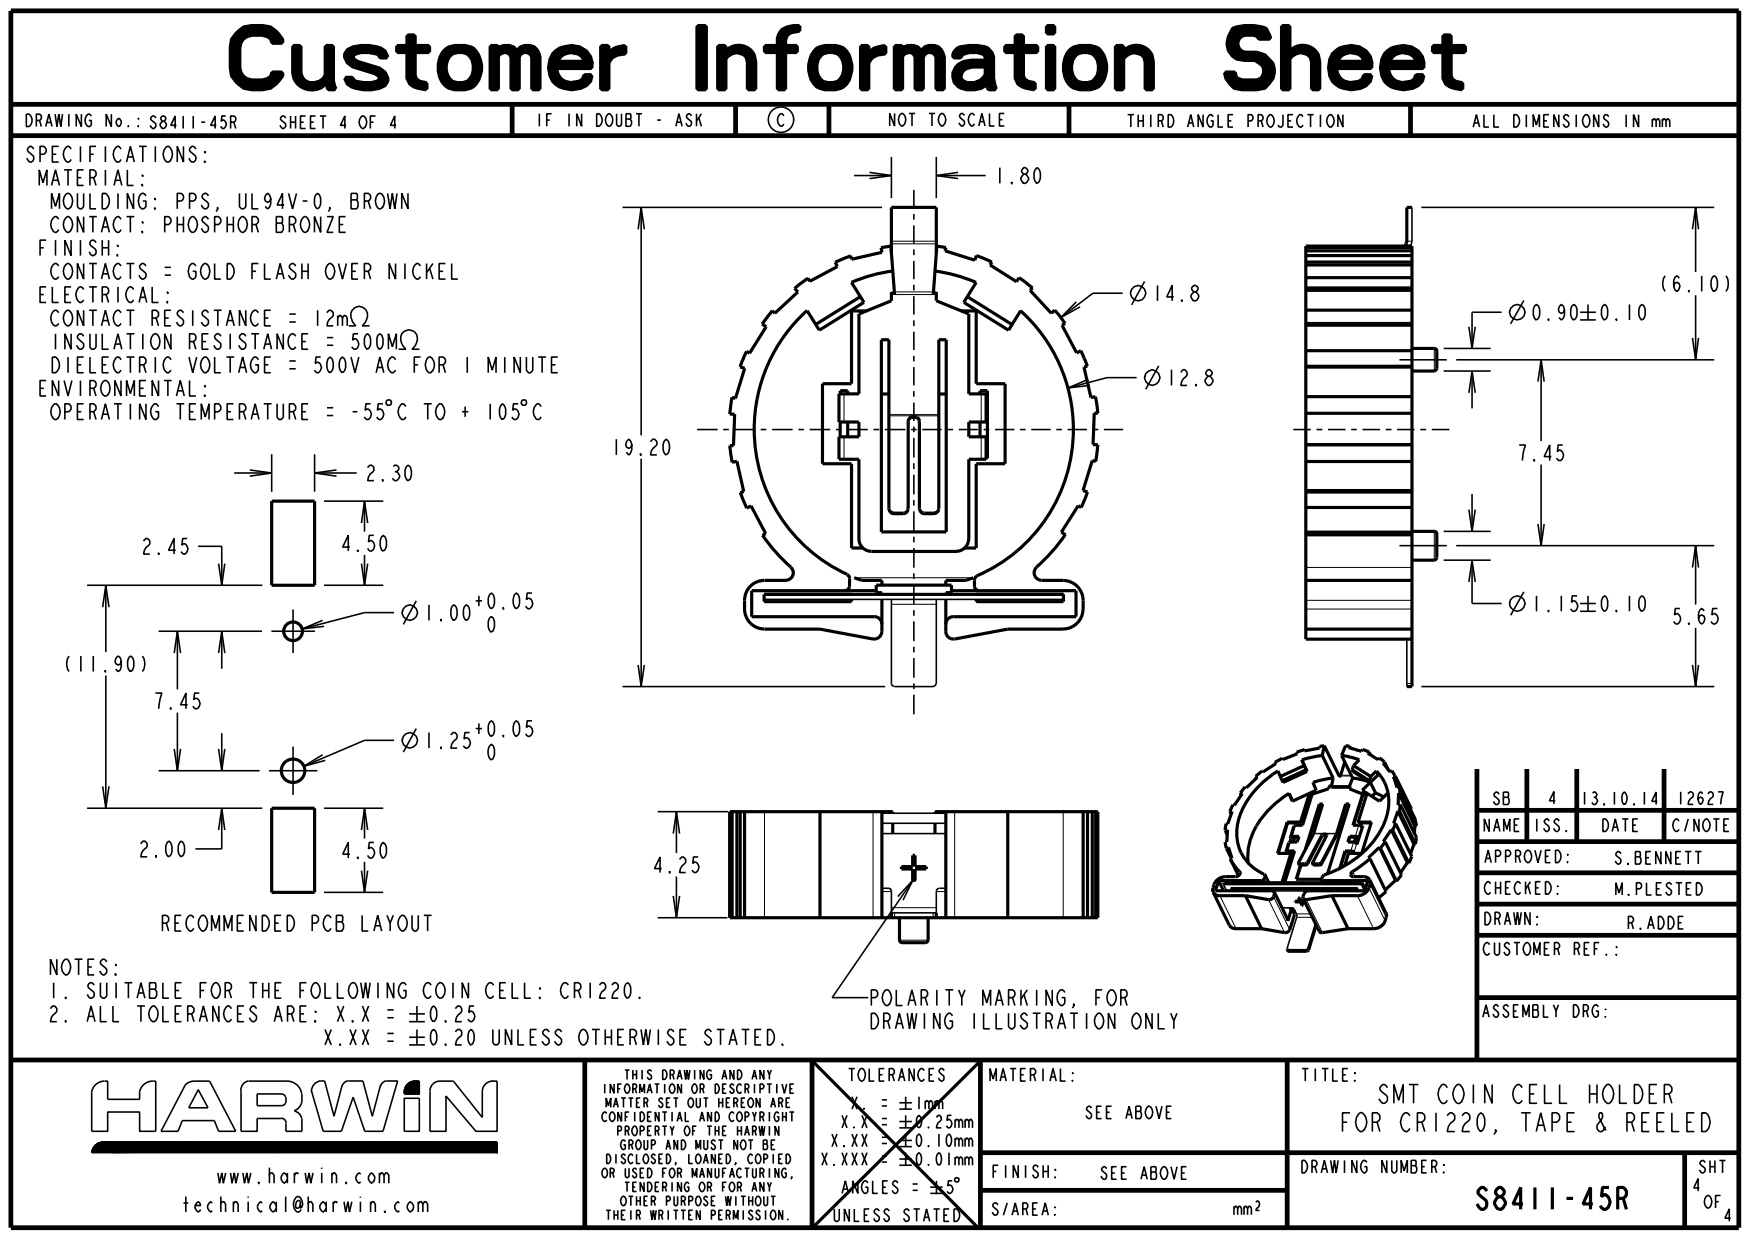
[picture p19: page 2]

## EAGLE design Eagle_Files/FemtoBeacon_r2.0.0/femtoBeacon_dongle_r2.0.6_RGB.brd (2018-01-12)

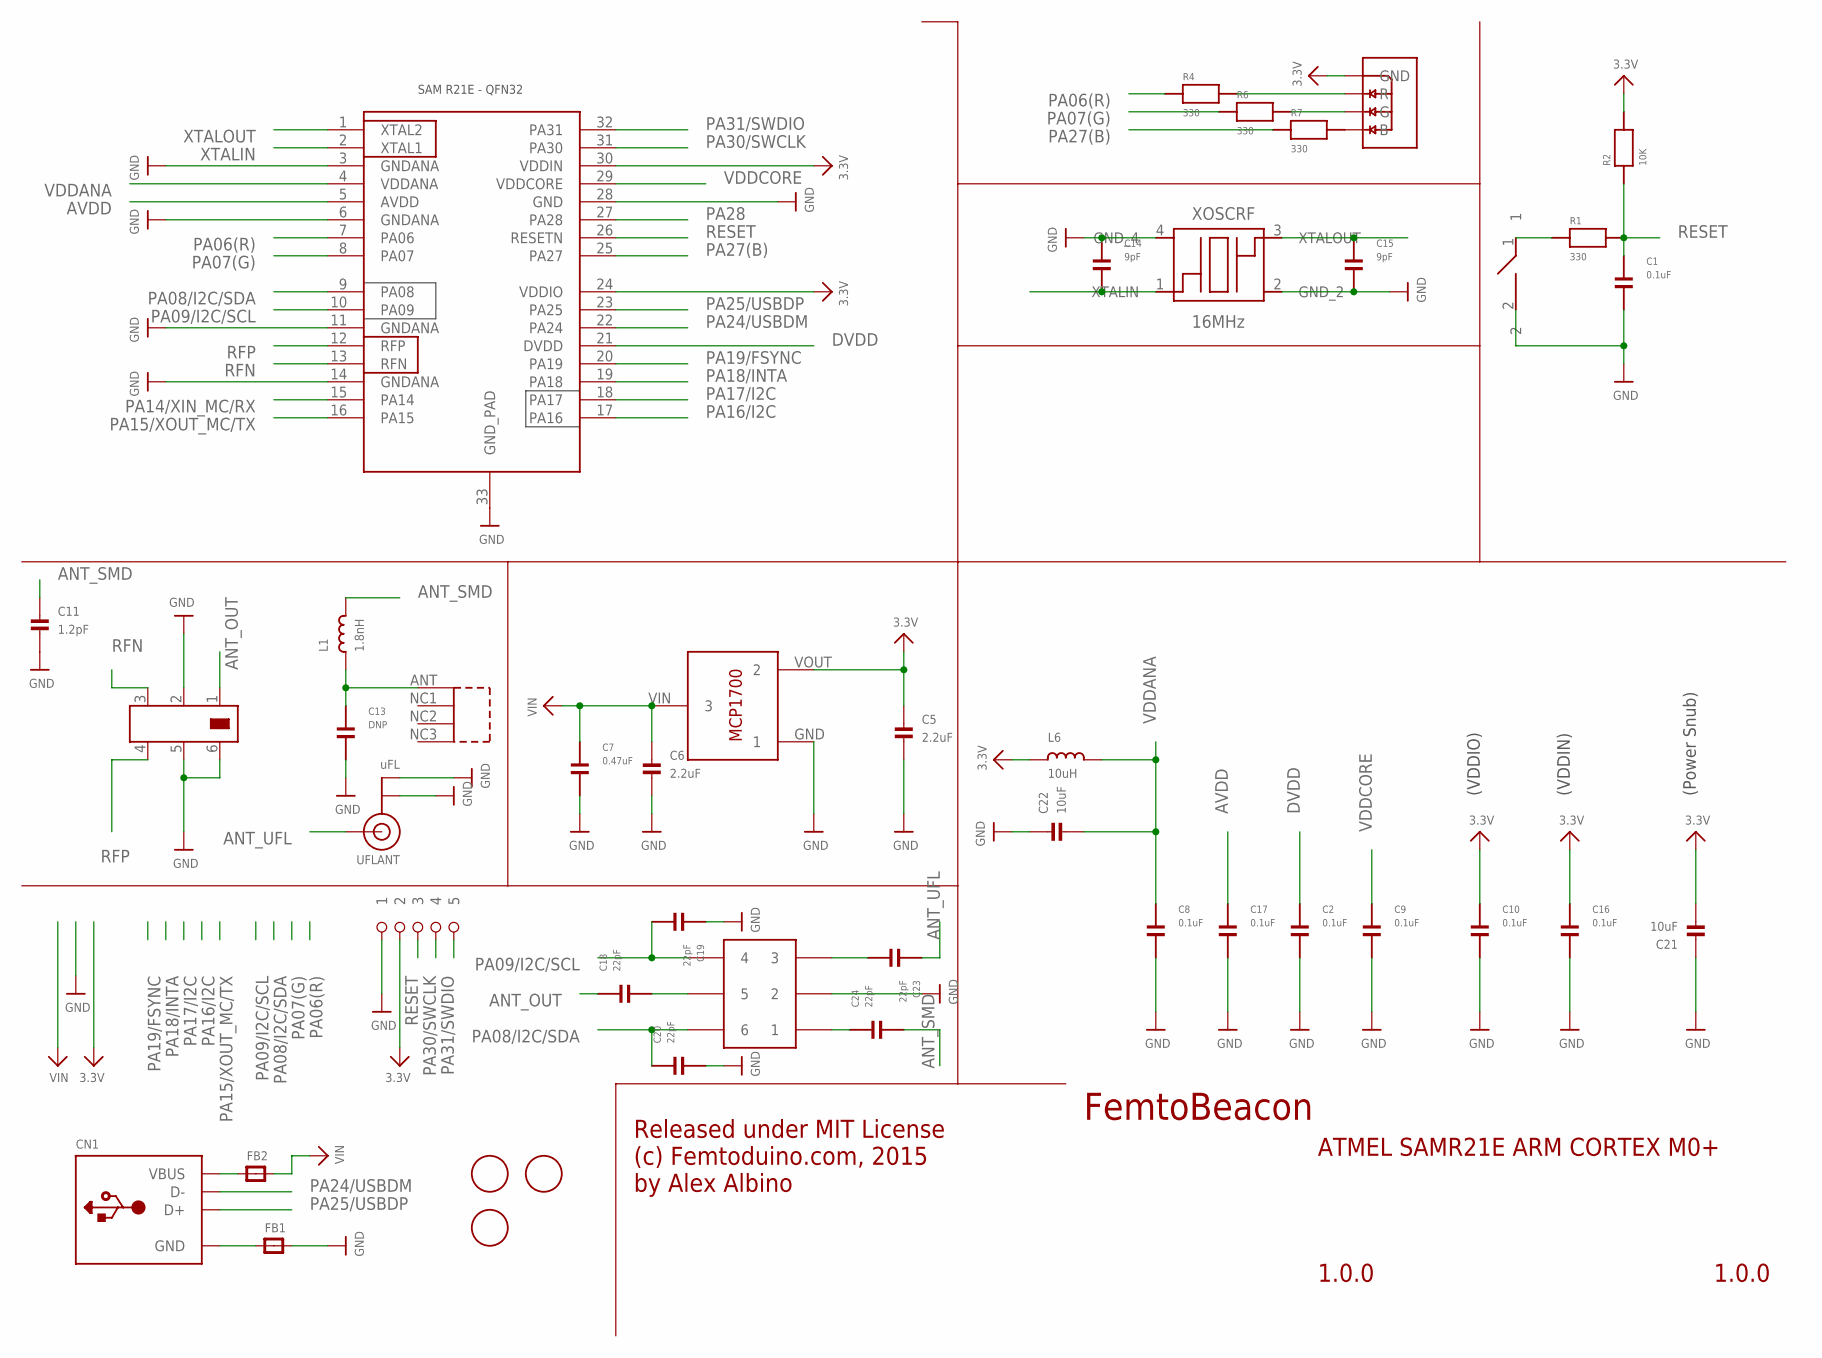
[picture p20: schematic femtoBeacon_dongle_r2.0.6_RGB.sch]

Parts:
ASWITCH: AS222-92LF
BTN: DNP; SPST_SMD
C1, C2, C8, C9, C10, C16, C17: 0.1uF; PART
C5, C6: 2.2uF; _0402MP
C7: 0.47uF; PART
C11: 1.2pF; _0402MP
C13: DNP; PART
C14, C15: 9pF; PART
C18, C19, C20, C23, C24: 22pF; PART
C21, C22: 10uF; _0402MP
CN1: USB_TYPEA; USB_A-SMT
FB1, FB2: FERRITE_0603MP; _0603MP
FID1, FID2, FID3: FIDUCIAL; FIDUCIAL_1MM
L1: 1.8nH; _0603MP
L6: 10uH; _0603MP
LDO_VREG: MCP1700T-3302E/TT
R1, R4, R6, R7: 330; PART
R2: 10K; PART
RGBLED: LRTB_R48G
U$1: 1X5_ROUND
U$6: 0479480001
U$12: JOHANSON_2450BM15A0015E; 0805_BALUN
U$76: ATSAMR21E18A-MUT; QFN32
UFLANT: uFL; U.FL
XOSCRF: 16MHz; TSX-3225

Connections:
3.3V: C5.1, C10.1, C16.1, C21.2, L6.1, LDO_VREG.VOUT (2), R2.2, RGBLED.1 (GND), U$1.P$2 (2), U$76.24 (VDDIO), U$76.30 (VDDIN)
ANT_LINE: C13.1, L1.1, U$6.ANT (1)
ANT_OUT: C18.1, U$12.1
ANT_SMD: C11.1, C24.2, L1.2
ANT_UFL: C23.1, UFLANT.3 (SIGNAL)
AVDD: C17.1, U$76.5 (AVDD)
DVDD: C2.1, U$76.21 (DVDD)
GND: ASWITCH.PIN2 (2), BTN.2, C1.2, C2.2, C5.2, C6.2, C7.2, C8.2, C9.2, C10.2, C11.2, C13.2, C14.1, C15.2, C16.2, C17.2, C19.1, C20.2, C21.1, C22.1, FB1.2, LDO_VREG.GND (1), U$1.P$1 (1), U$12.2, U$12.5, U$12.6, U$76.3 (GNDANA), U$76.6 (GNDANA), U$76.11 (GNDANA), U$76.14 (GNDANA), U$76.28 (GND), U$76.33 (GND_PAD), UFLANT.1 (GND), UFLANT.2 (GND), XOSCRF.2 (GND_2), XOSCRF.4 (GND_4)
unnamed: R6.2, RGBLED.3 (G)
unnamed: CN1.VBUS, FB2.1
unnamed: CN1.GND, FB1.1
unnamed: R7.2, RGBLED.4 (B)
unnamed: R4.2, RGBLED.2 (R)
unnamed: BTN.1, R1.1
PA06(R): R4.1, U$76.7 (PA06)
PA07(G): R6.1, U$76.8 (PA07)
PA08/I2C/SDA: ASWITCH.PIN6 (6), C20.1, U$76.9 (PA08)
PA09/I2C/SCL: ASWITCH.PIN4 (4), C19.2, U$76.10 (PA09)
PA14/XIN_MC/RX: U$76.15 (PA14)
PA15/XOUT_MC/TX: U$76.16 (PA15)
PA16/I2C: U$76.17 (PA16)
PA17/I2C: U$76.18 (PA17)
PA18/INTA: U$76.19 (PA18)
PA19/FSYNC: U$76.20 (PA19)
PA24/USBDM: CN1.D-, U$76.22 (PA24)
PA25/USBDP: CN1.D+, U$76.23 (PA25)
PA27(B): R7.1, U$76.25 (PA27)
PA28: U$76.27 (PA28)
PA30/SWCLK: U$1.P$4 (4), U$76.31 (PA30)
PA31/SWDIO: U$1.P$5 (5), U$76.32 (PA31)
RESET: C1.1, R1.2, R2.1, U$1.P$3 (3), U$76.26 (RESETN)
RFN: U$12.3, U$76.13 (RFN)
RFP: U$12.4, U$76.12 (RFP)
RFSWITCH_PIN1: ASWITCH.PIN1 (1), C24.1
RFSWITCH_PIN3: ASWITCH.PIN3 (3), C23.2
RFSWITCH_PIN5: ASWITCH.PIN5 (5), C18.2
VDDANA: C8.1, C22.2, L6.2, U$76.4 (VDDANA)
VDDCORE: C9.1, U$76.29 (VDDCORE)
VIN: C6.1, C7.1, FB2.2, LDO_VREG.VIN (3)
XTALIN: C14.2, U$76.2 (XTAL1), XOSCRF.1 (XTALIN)
XTALOUT: C15.1, U$76.1 (XTAL2), XOSCRF.3 (XTALOUT)

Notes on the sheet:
FemtoBeacon
1.0.0
ATMEL SAMR21E ARM CORTEX M0+
Released under MIT License (c) Femtoduino.com, 2015 by Alex Albino
(Power Snub)
(VDDIO)
(VDDIN)

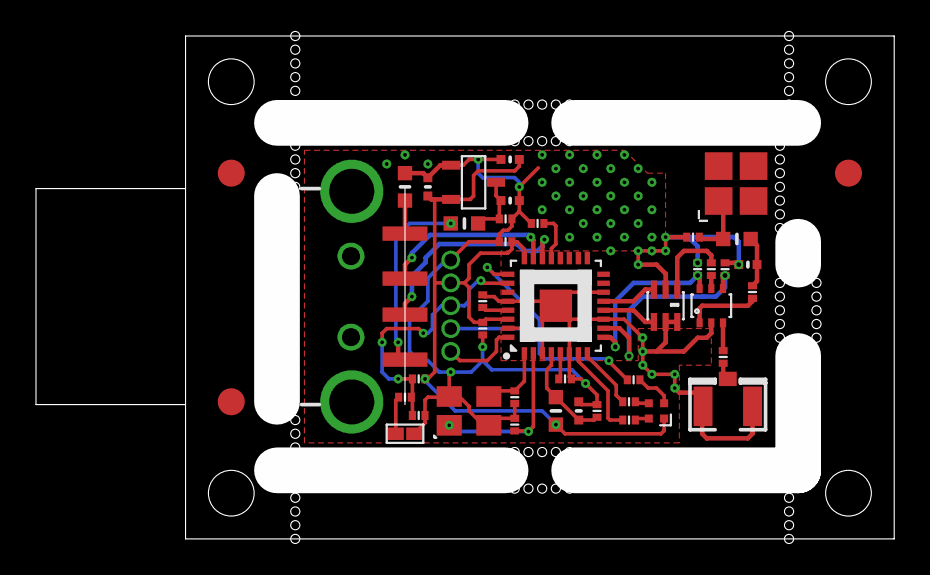
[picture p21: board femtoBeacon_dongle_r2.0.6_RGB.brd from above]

Board: 2 copper layers, 47.7 x 27.9 mm, 44 parts (0 on the bottom side), 34 nets.

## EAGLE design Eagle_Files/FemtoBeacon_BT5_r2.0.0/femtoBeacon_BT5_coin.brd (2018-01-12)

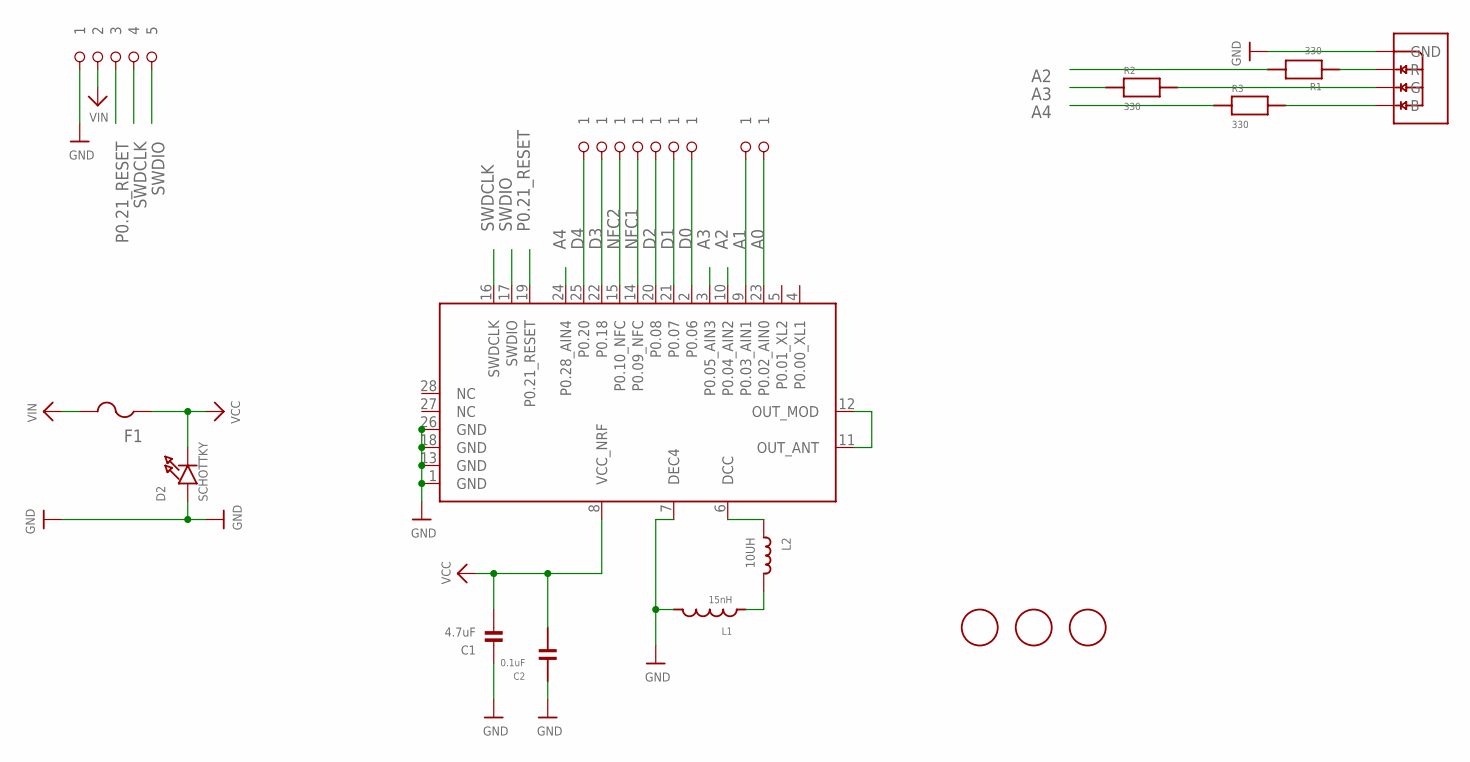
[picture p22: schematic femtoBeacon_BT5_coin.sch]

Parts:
C1: 4.7uF; _0402MP
C2: 0.1uF; PART
D2: SCHOTTKY; CHIPLED_0603_NOOUTLINE
F1: PTCFUSE-1206; R1206
FID1, FID2, FID3: FIDUCIAL; FIDUCIAL_1MM
IC: TY_BLE_EYSHSNZWZ; MODULE
L1: 15nH; PART
L2: 10UH; _0402MP
LED1: LRTB_R48G
R1, R2, R3: 330; PART
U$6: 1X5_ROUND
U$16, U$17, U$18, U$19, U$20, U$21, U$22, U$23, U$24: 1X1_ROUND_MM

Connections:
A0: IC.23 (P0.02_AIN0), U$16.P$1
A1: IC.9 (P0.03_AIN1), U$17.P$1
A2: IC.10 (P0.04_AIN2), R1.2
A3: IC.3 (P0.05_AIN3), R2.1
A4: IC.24 (P0.28_AIN4), R3.1
D0: IC.2 (P0.06), U$18.P$1
D1: IC.21 (P0.07), U$19.P$1
D2: IC.20 (P0.08), U$20.P$1
D3: IC.22 (P0.18), U$23.P$1
D4: IC.25 (P0.20), U$24.P$1
GND: C1.1, C2.1, D2.A, IC.1 (GND), IC.7 (DEC4), IC.13 (GND), IC.18 (GND), IC.26 (GND), L1.2, LED1.1 (GND), U$6.P$1 (1)
INTERNAL_ANT: IC.11 (OUT_ANT), IC.12 (OUT_MOD)
unnamed: IC.6 (DCC), L2.1
unnamed: LED1.2 (R), R1.1
unnamed: L1.1, L2.2
unnamed: LED1.3 (G), R2.2
unnamed: LED1.4 (B), R3.2
NFC1: IC.14 (P0.09_NFC), U$21.P$1
NFC2: IC.15 (P0.10_NFC), U$22.P$1
P0.21_RESET: IC.19 (P0.21_RESET), U$6.P$3 (3)
SWDCLK: IC.16 (SWDCLK), U$6.P$4 (4)
SWDIO: IC.17 (SWDIO), U$6.P$5 (5)
VCC: C1.2, C2.2, D2.C, F1.1, IC.8 (VCC_NRF)
VIN: F1.2, U$6.P$2 (2)

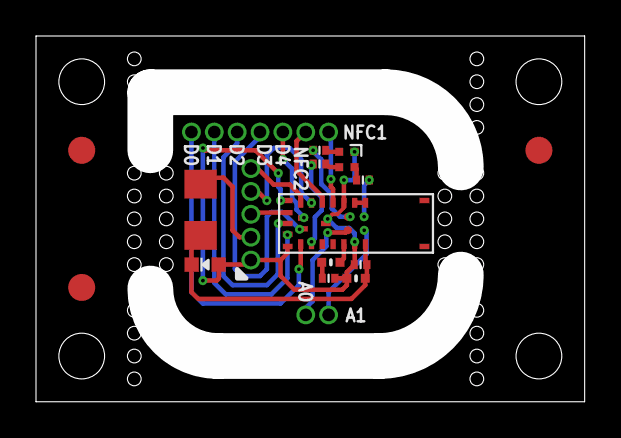
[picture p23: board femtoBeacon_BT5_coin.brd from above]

Board: 2 copper layers, 30.5 x 20.3 mm, 24 parts (0 on the bottom side), 24 nets.

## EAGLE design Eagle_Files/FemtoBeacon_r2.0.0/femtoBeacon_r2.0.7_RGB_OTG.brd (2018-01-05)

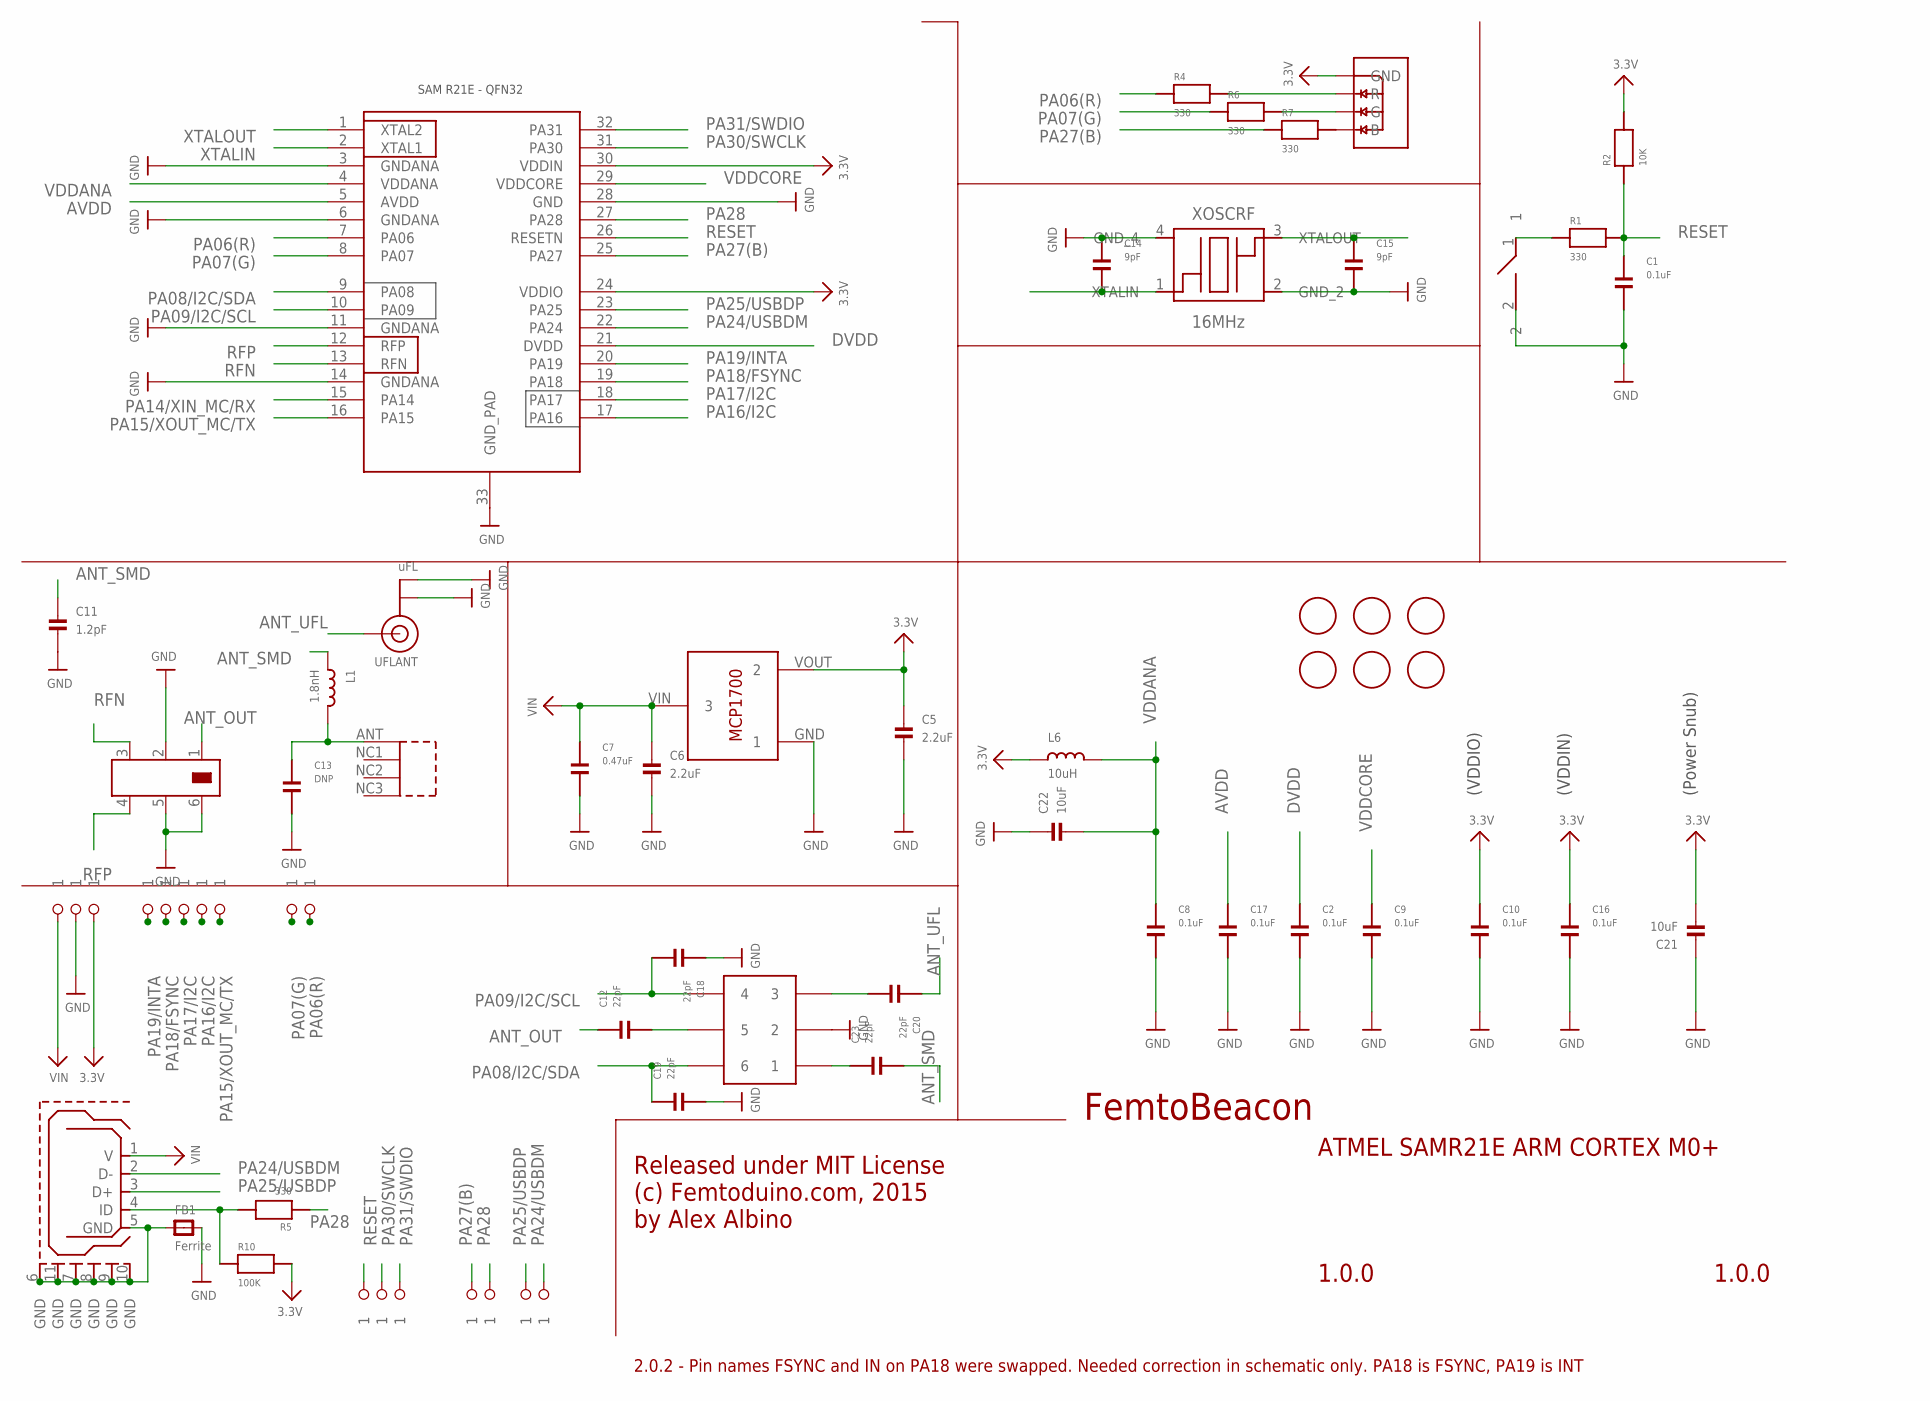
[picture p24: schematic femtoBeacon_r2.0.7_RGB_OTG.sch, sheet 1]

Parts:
ANT_SMD: 0479480001
ASWITCH: AS222-92LF
BALUN: JOHANSON_2450BM15A0015E; 0805_BALUN
BTN: DNP; SPST_SMD
C1, C8, C9, C10, C16, C17: 0.1uF; PART; DIGIKEY_PART 490-3194-1-ND
C2: 0.1uF; PART
C5, C6: 2.2uF; _0402MP
C7: 0.47uF; PART
C11: 1.2pF; _0402MP
C12, C18, C19, C20, C23: 22pF; PART; DIGIKEY_PART 490-3194-1-ND
C13: DNP; PART; DIGIKEY_PART 490-3194-1-ND
C14, C15: 9pF; PART
C21, C22: 10uF; _0402MP
FB1: Ferrite; _0603MP
FID1, FID2, FID3, FID4, FID5, FID6: FIDUCIAL; FIDUCIAL_1MM
IC: ATSAMR21E18A-MUT; QFN32
L1: 1.8nH; _0603MP
L6: 10uH; _0603MP
LDO_VREG: MCP1700T-3302E/TT
R1, R4, R5, R6, R7: 330; PART
R2: 10K; PART
R10: 100K; PART
RGBLED: LRTB_R48G
U$1, U$2, U$5, U$7, U$9, U$10, U$35, U$36, U$37, U$38, U$39, U$43, U$45, U$46, U$47, U$48, U$54: 1X1_ROUND
UFLANT: uFL; U.FL
USB: USB_MICROB; USB_MICROB_PACKAGE
XOSCRF: 16MHz; TSX-3225

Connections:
3.3V: C5.1, C10.1, C16.1, C21.2, IC.24 (VDDIO), IC.30 (VDDIN), L6.1, LDO_VREG.VOUT (2), R2.2, R10.2, RGBLED.1 (GND), U$5.P$1; also elsewhere on the board
ANT_LINE: ANT_SMD.ANT (1), C13.1, L1.2
ANT_OUT: BALUN.1, C12.1
ANT_SMD: C11.1, C23.2, L1.1
ANT_UFL: C20.1, UFLANT.3 (SIGNAL)
AVDD: C17.1, IC.5 (AVDD)
DVDD: C2.1, IC.21 (DVDD)
GND: ASWITCH.PIN2 (2), BALUN.2, BALUN.5, BALUN.6, BTN.2, C1.2, C2.2, C5.2, C6.2, C7.2, C8.2, C9.2, C10.2, C11.2, C13.2, C14.1, C15.2, C16.2, C17.2, C18.1, C19.2, C21.1, C22.1, FB1.2, IC.3 (GNDANA), IC.6 (GNDANA), IC.11 (GNDANA), IC.14 (GNDANA), IC.28 (GND), IC.33 (GND_PAD), LDO_VREG.GND (1), U$2.P$1, UFLANT.1 (GND), UFLANT.2 (GND), XOSCRF.2 (GND_2), XOSCRF.4 (GND_4); also elsewhere on the board
unnamed: R5.2, R10.1, USB.4 (ID)
unnamed: FB1.1, USB.5 (GND), USB.6 (GND), USB.7 (GND), USB.8 (GND), USB.9 (GND), USB.10 (GND), USB.11 (GND)
unnamed: R6.2, RGBLED.3 (G)
unnamed: R7.2, RGBLED.4 (B)
unnamed: R4.2, RGBLED.2 (R)
unnamed: BTN.1, R1.1
PA06(R): IC.7 (PA06), R4.1, U$54.P$1
PA07(G): IC.8 (PA07), R6.1, U$43.P$1
PA08/I2C/SDA: ASWITCH.PIN6 (6), C19.1, IC.9 (PA08)
PA09/I2C/SCL: ASWITCH.PIN4 (4), C18.2, IC.10 (PA09)
PA14/XIN_MC/RX: IC.15 (PA14)
PA15/XOUT_MC/TX: IC.16 (PA15), U$39.P$1
PA16/I2C: IC.17 (PA16), U$38.P$1; also elsewhere on the board
PA17/I2C: IC.18 (PA17), U$37.P$1; also elsewhere on the board
PA18/FSYNC: IC.19 (PA18), U$36.P$1; also elsewhere on the board
PA19/INTA: IC.20 (PA19), U$35.P$1; also elsewhere on the board
PA24/USBDM: IC.22 (PA24), U$9.P$1, USB.2 (D-)
PA25/USBDP: IC.23 (PA25), U$10.P$1, USB.3 (D+)
PA27(B): IC.25 (PA27), R7.1, U$7.P$1
PA28: IC.27 (PA28), R5.1, U$48.P$1
PA30/SWCLK: IC.31 (PA30), U$46.P$1
PA31/SWDIO: IC.32 (PA31), U$47.P$1
RESET: C1.1, IC.26 (RESETN), R1.2, R2.1, U$45.P$1
RFN: BALUN.3, IC.13 (RFN)
RFP: BALUN.4, IC.12 (RFP)
RFSWITCH_PIN1: ASWITCH.PIN1 (1), C23.1
RFSWITCH_PIN3: ASWITCH.PIN3 (3), C20.2
RFSWITCH_PIN5: ASWITCH.PIN5 (5), C12.2
VDDANA: C8.1, C22.2, IC.4 (VDDANA), L6.2
VDDCORE: C9.1, IC.29 (VDDCORE)
VIN: C6.1, C7.1, LDO_VREG.VIN (3), U$1.P$1, USB.1 (V)
XTALIN: C14.2, IC.2 (XTAL1), XOSCRF.1 (XTALIN)
XTALOUT: C15.1, IC.1 (XTAL2), XOSCRF.3 (XTALOUT)

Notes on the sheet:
FemtoBeacon
1.0.0
ATMEL SAMR21E ARM CORTEX M0+
Released under MIT License (c) Femtoduino.com, 2015 by Alex Albino
(Power Snub)
(VDDIO)
(VDDIN)
2.0.2 - Pin names FSYNC and IN on PA18 were swapped. Needed correction in schematic only. PA18 is FSYNC, PA19 is INT

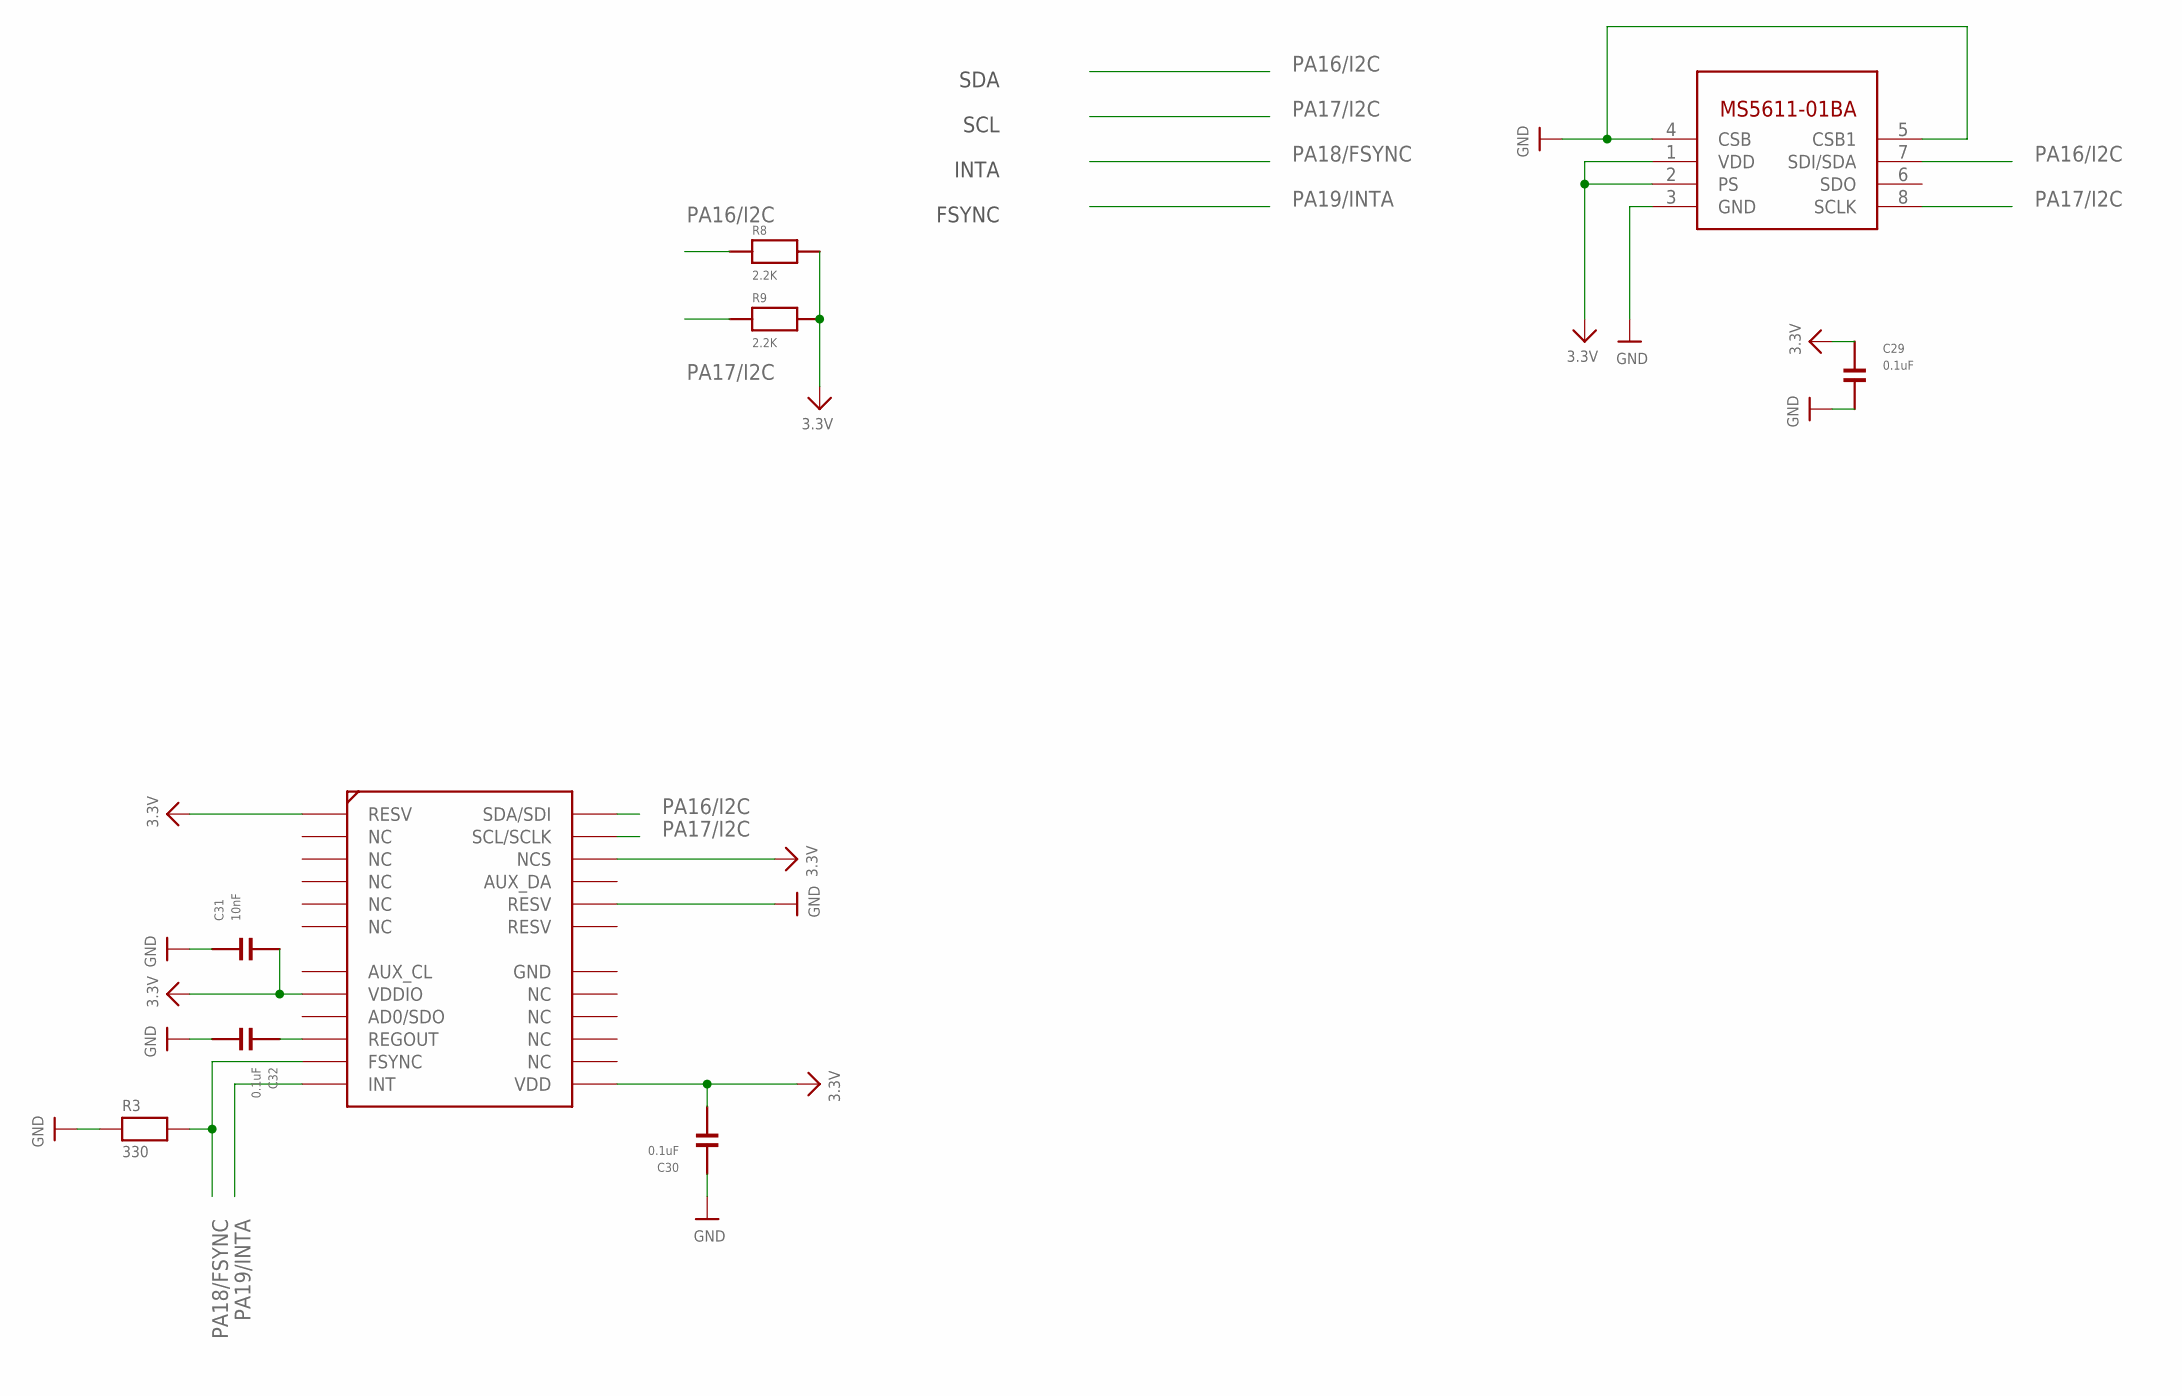
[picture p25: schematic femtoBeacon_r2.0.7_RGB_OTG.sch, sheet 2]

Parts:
BARO: MS5611-01BA03
C29, C30, C32: 0.1uF; PART; DIGIKEY_PART 490-3194-1-ND
C31: 10nF; PART; DIGIKEY_PART 490-3194-1-ND
IMU: MPU-9250; QFN_3X3MM
R3: 330; _0402
R8, R9: 2.2K; PART

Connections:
3.3V: BARO.1 (VDD), BARO.2 (PS), C29.1, C30.2, C31.2, IMU.P$1 (RESV), IMU.P$8 (VDDIO), IMU.P$13 (VDD), IMU.P$22 (NCS), R8.2, R9.2; also elsewhere on the board
GND: BARO.3 (GND), BARO.4 (CSB), BARO.5 (CSB1), C29.2, C30.1, C31.1, C32.2, IMU.P$20 (RESV), R3.1; also elsewhere on the board
unnamed: C32.1, IMU.P$10 (REGOUT)
PA16/I2C: BARO.7 (SDI/SDA), IMU.P$24 (SDA/SDI), R8.1; also elsewhere on the board
PA17/I2C: BARO.8 (SCLK), IMU.P$23 (SCL/SCLK), R9.1; also elsewhere on the board
PA18/FSYNC: IMU.P$11 (FSYNC), R3.2; also elsewhere on the board
PA19/INTA: IMU.P$12 (INT); also elsewhere on the board

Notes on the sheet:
SDA
SCL
INTA
FSYNC

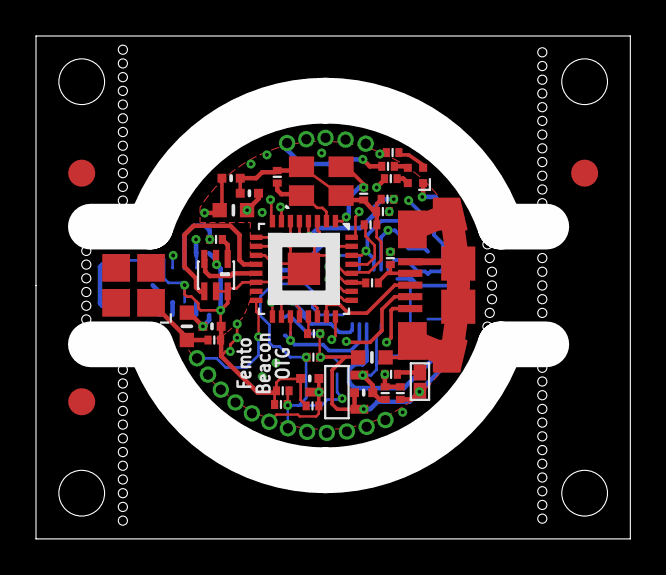
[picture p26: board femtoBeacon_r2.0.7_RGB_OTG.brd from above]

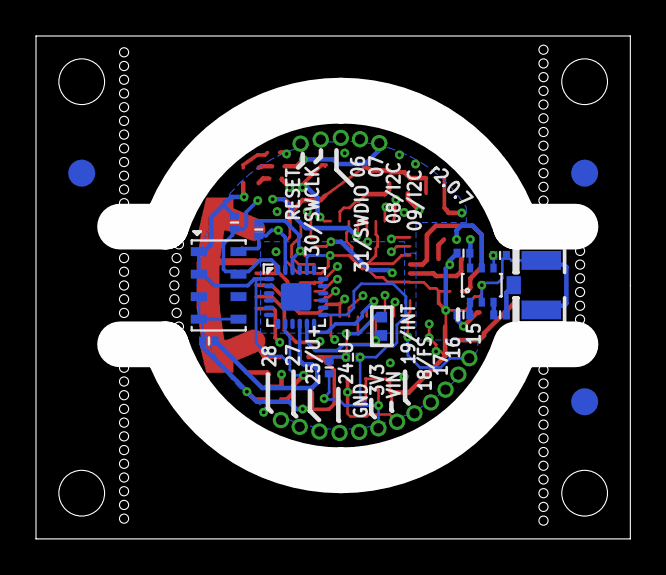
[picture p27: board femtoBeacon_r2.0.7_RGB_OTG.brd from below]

Board: 4 copper layers, 33.0 x 27.9 mm, 73 parts (17 on the bottom side), 41 nets.

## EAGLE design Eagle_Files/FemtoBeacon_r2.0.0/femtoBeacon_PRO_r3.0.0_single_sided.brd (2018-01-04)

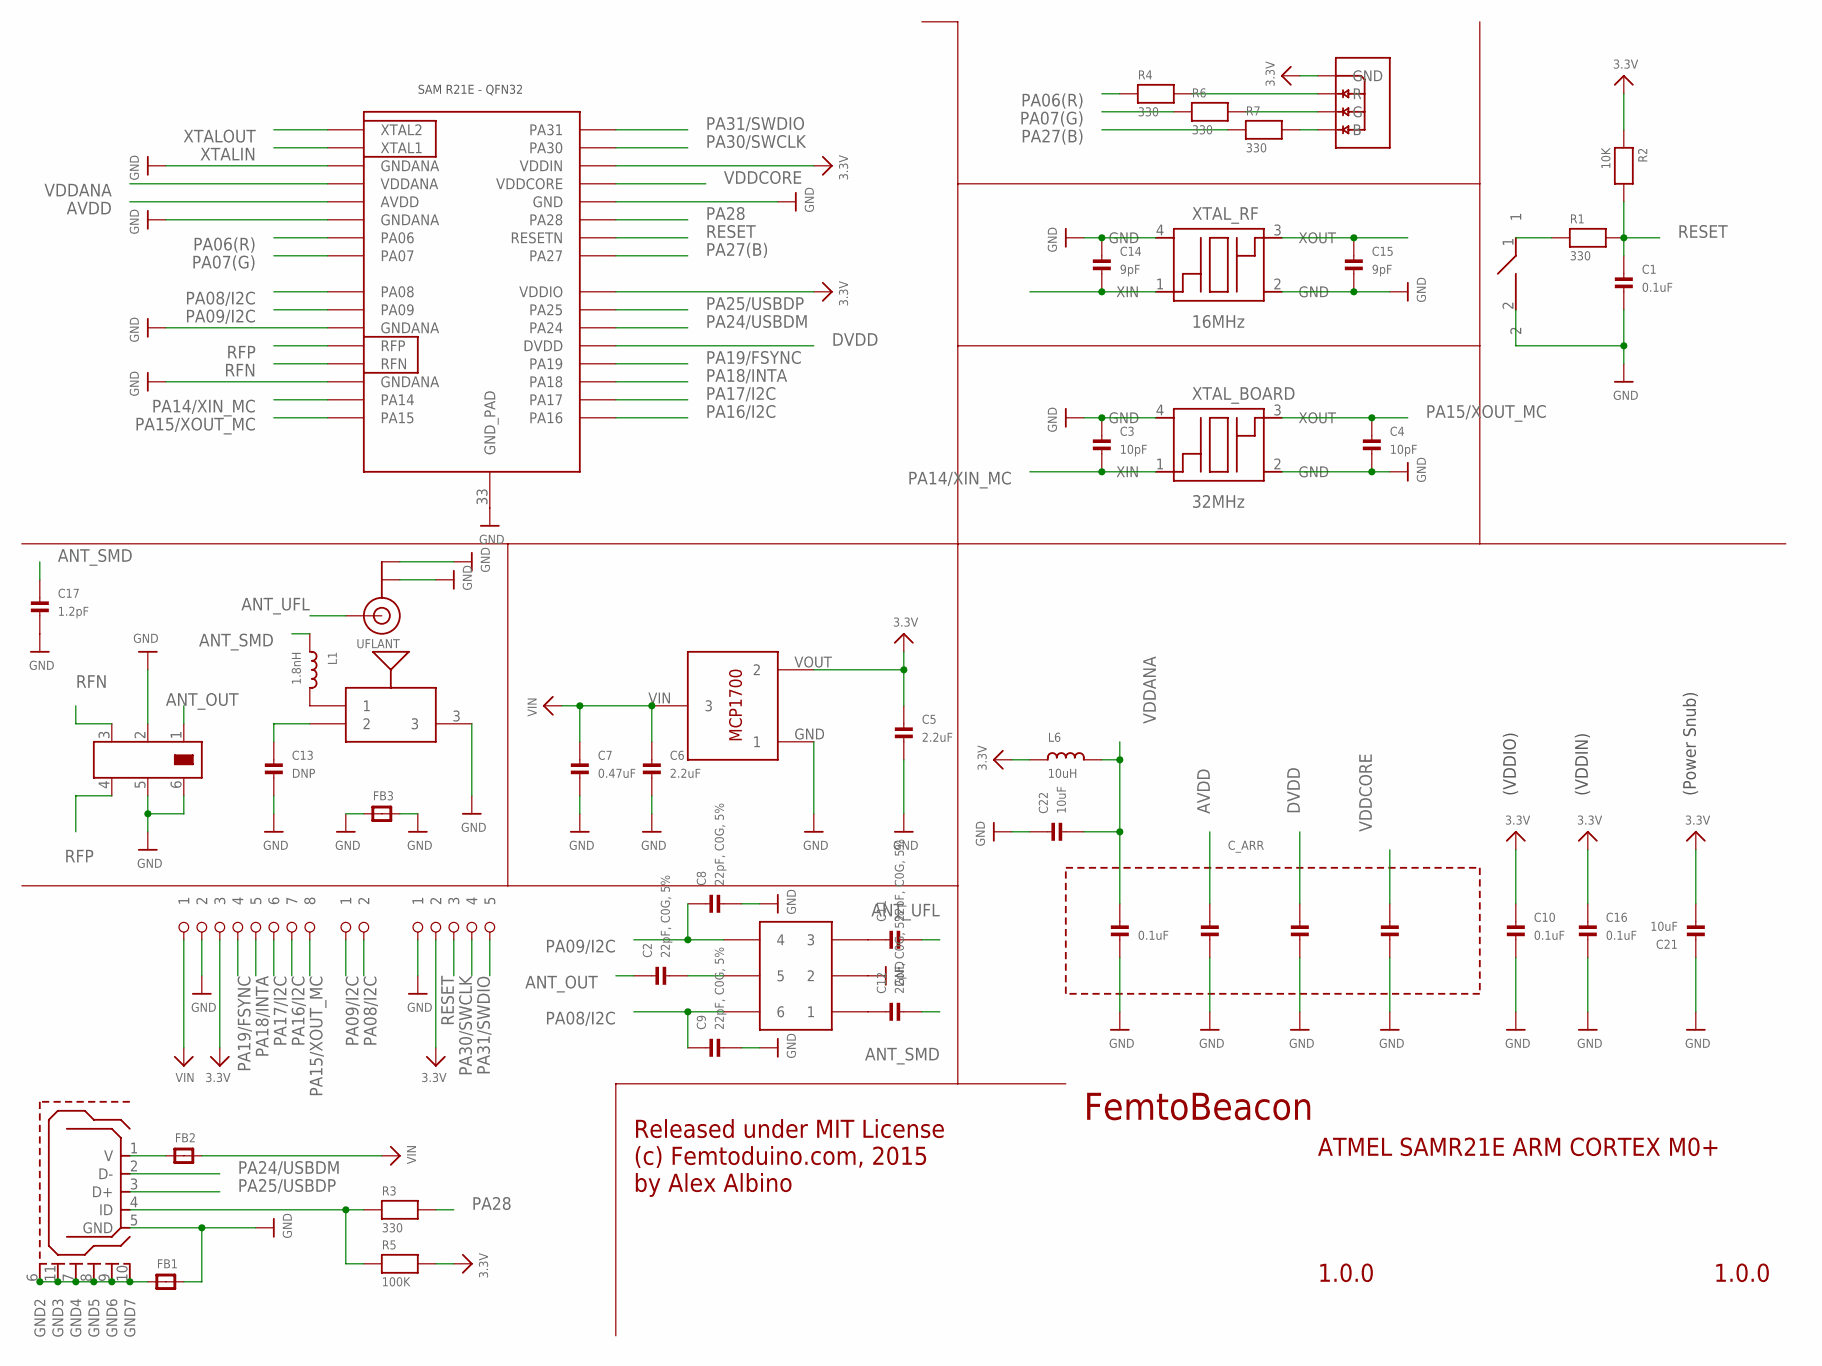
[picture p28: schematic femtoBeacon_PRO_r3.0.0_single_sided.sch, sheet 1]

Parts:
ASWITCH: AS222-92LF
BALUN: JOHANSON_2450BM15A0015E; 0805_BALUN
BTN_RESET: DNP; SPST_SMD
C1, C10, C16: 0.1uF; _0402MP; DIGIKEY_PART 490-3194-1-ND
C2, C8, C9, C11, C12: 22pF, C0G, 5%; _0402MP; DIGIKEY_PART 490-3194-1-ND
C3, C4: 10pF; _0402MP; DIGIKEY_PART 490-3194-1-ND
C5, C6: 2.2uF; _0402MP
C7: 0.47uF; _0402MP
C13: DNP; _0402MP; DIGIKEY_PART 490-3194-1-ND
C14, C15: 9pF; _0402MP; DIGIKEY_PART 490-3194-1-ND
C17: 1.2pF; _0402MP
C21, C22: 10uF; _0402MP
C_ARR: 0.1uF; CAPACITOR_ARRAY_1206_MONO_1X4
FB1, FB2, FB3: FERRITE_0603MP; _0603MP
IC: ATSAMR21E18A-MUT; QFN32
L1: 1.8nH; _0603MP
L6: 10uH; _0603MP
LDO_VREG: MCP1700T-3302E/TT
R1, R3, R4, R6, R7: 330; _0402MP
R2: 10K; _0402MP
R5: 100K; _0402MP
RGBLED: LRTB_R48G
SMDANT: PULSE_ANT_2.4GHZ; ANT_BAR
U$5: 1X8_ROUND
U$9: 1X2_ROUND
U$10: 1X5_ROUND
UFLANT: ANTENNA_U.FL; U.FL
USB: USB_MICROB; USB_MICROB_PACKAGE
XTAL_BOARD: 32MHz; FA-128
XTAL_RF: 16MHz; TSX-3225

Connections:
3.3V: C5.1, C10.1, C16.1, C21.2, IC.24 (VDDIO), IC.30 (VDDIN), L6.1, LDO_VREG.VOUT (2), R2.1, R5.2, RGBLED.1 (GND), U$5.P$3 (3), U$10.P$2 (2); also elsewhere on the board
ANT_OUT: BALUN.1, C2.1
ANT_SMD: C12.2, C17.1, L1.1
ANT_UFL: C11.2, UFLANT.3 (SIGNAL)
AVDD: C_ARR.3, IC.5 (AVDD)
DVDD: C_ARR.5, IC.21 (DVDD)
GND: ASWITCH.PIN2 (2), BALUN.2, BALUN.5, BALUN.6, BTN_RESET.2, C1.2, C3.1, C4.2, C5.2, C6.2, C7.2, C8.2, C9.2, C10.2, C13.2, C14.1, C15.2, C16.2, C17.2, C21.1, C22.1, C_ARR.2, C_ARR.4, C_ARR.6, C_ARR.8, FB1.2, FB3.1, FB3.2, IC.3 (GNDANA), IC.6 (GNDANA), IC.11 (GNDANA), IC.14 (GNDANA), IC.28 (GND), IC.33 (GND_PAD), LDO_VREG.GND (1), SMDANT.3, U$5.P$2 (2), U$10.P$1 (1), UFLANT.1 (GND), UFLANT.2 (GND), USB.5 (GND), XTAL_BOARD.2 (GND), XTAL_BOARD.4 (GND), XTAL_RF.2 (GND), XTAL_RF.4 (GND); also elsewhere on the board
unnamed: L1.2, SMDANT.1
unnamed: C13.1, SMDANT.2
unnamed: ASWITCH.PIN5 (5), C2.2
unnamed: FB1.1, USB.6 (GND2), USB.7 (GND4), USB.8 (GND5), USB.9 (GND6), USB.10 (GND7), USB.11 (GND3)
unnamed: R3.1, R5.1, USB.4 (ID)
unnamed: FB2.1, USB.1 (V)
unnamed: R6.2, RGBLED.3 (G)
unnamed: R7.2, RGBLED.4 (B)
unnamed: ASWITCH.PIN3 (3), C11.1
unnamed: ASWITCH.PIN1 (1), C12.1
unnamed: R4.2, RGBLED.2 (R)
unnamed: BTN_RESET.1, R1.1
PA06(R): IC.7 (PA06), R4.1
PA07(G): IC.8 (PA07), R6.1
PA08/I2C: ASWITCH.PIN6 (6), C9.1, IC.9 (PA08), U$9.P$2 (2)
PA09/I2C: ASWITCH.PIN4 (4), C8.1, IC.10 (PA09), U$9.P$1 (1)
PA14/XIN_MC: C3.2, IC.15 (PA14), XTAL_BOARD.1 (XIN)
PA15/XOUT_MC: C4.1, IC.16 (PA15), U$5.P$8 (8), XTAL_BOARD.3 (XOUT)
PA16/I2C: IC.17 (PA16), U$5.P$7 (7); also elsewhere on the board
PA17/I2C: IC.18 (PA17), U$5.P$6 (6); also elsewhere on the board
PA18/INTA: IC.19 (PA18), U$5.P$5 (5); also elsewhere on the board
PA19/FSYNC: IC.20 (PA19), U$5.P$4 (4); also elsewhere on the board
PA24/USBDM: IC.22 (PA24), USB.2 (D-)
PA25/USBDP: IC.23 (PA25), USB.3 (D+)
PA27(B): IC.25 (PA27), R7.1
PA28: IC.27 (PA28), R3.2
PA30/SWCLK: IC.31 (PA30), U$10.P$4 (4)
PA31/SWDIO: IC.32 (PA31), U$10.P$5 (5)
RESET: C1.1, IC.26 (RESETN), R1.2, R2.2, U$10.P$3 (3)
RFN: BALUN.3, IC.13 (RFN)
RFP: BALUN.4, IC.12 (RFP)
VDDANA: C22.2, C_ARR.1, IC.4 (VDDANA), L6.2
VDDCORE: C_ARR.7, IC.29 (VDDCORE)
VIN: C6.1, C7.1, FB2.2, LDO_VREG.VIN (3), U$5.P$1 (1)
XTALIN: C14.2, IC.2 (XTAL1), XTAL_RF.1 (XIN)
XTALOUT: C15.1, IC.1 (XTAL2), XTAL_RF.3 (XOUT)

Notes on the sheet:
FemtoBeacon
1.0.0
ATMEL SAMR21E ARM CORTEX M0+
Released under MIT License (c) Femtoduino.com, 2015 by Alex Albino
(Power Snub)
(VDDIO)
(VDDIN)

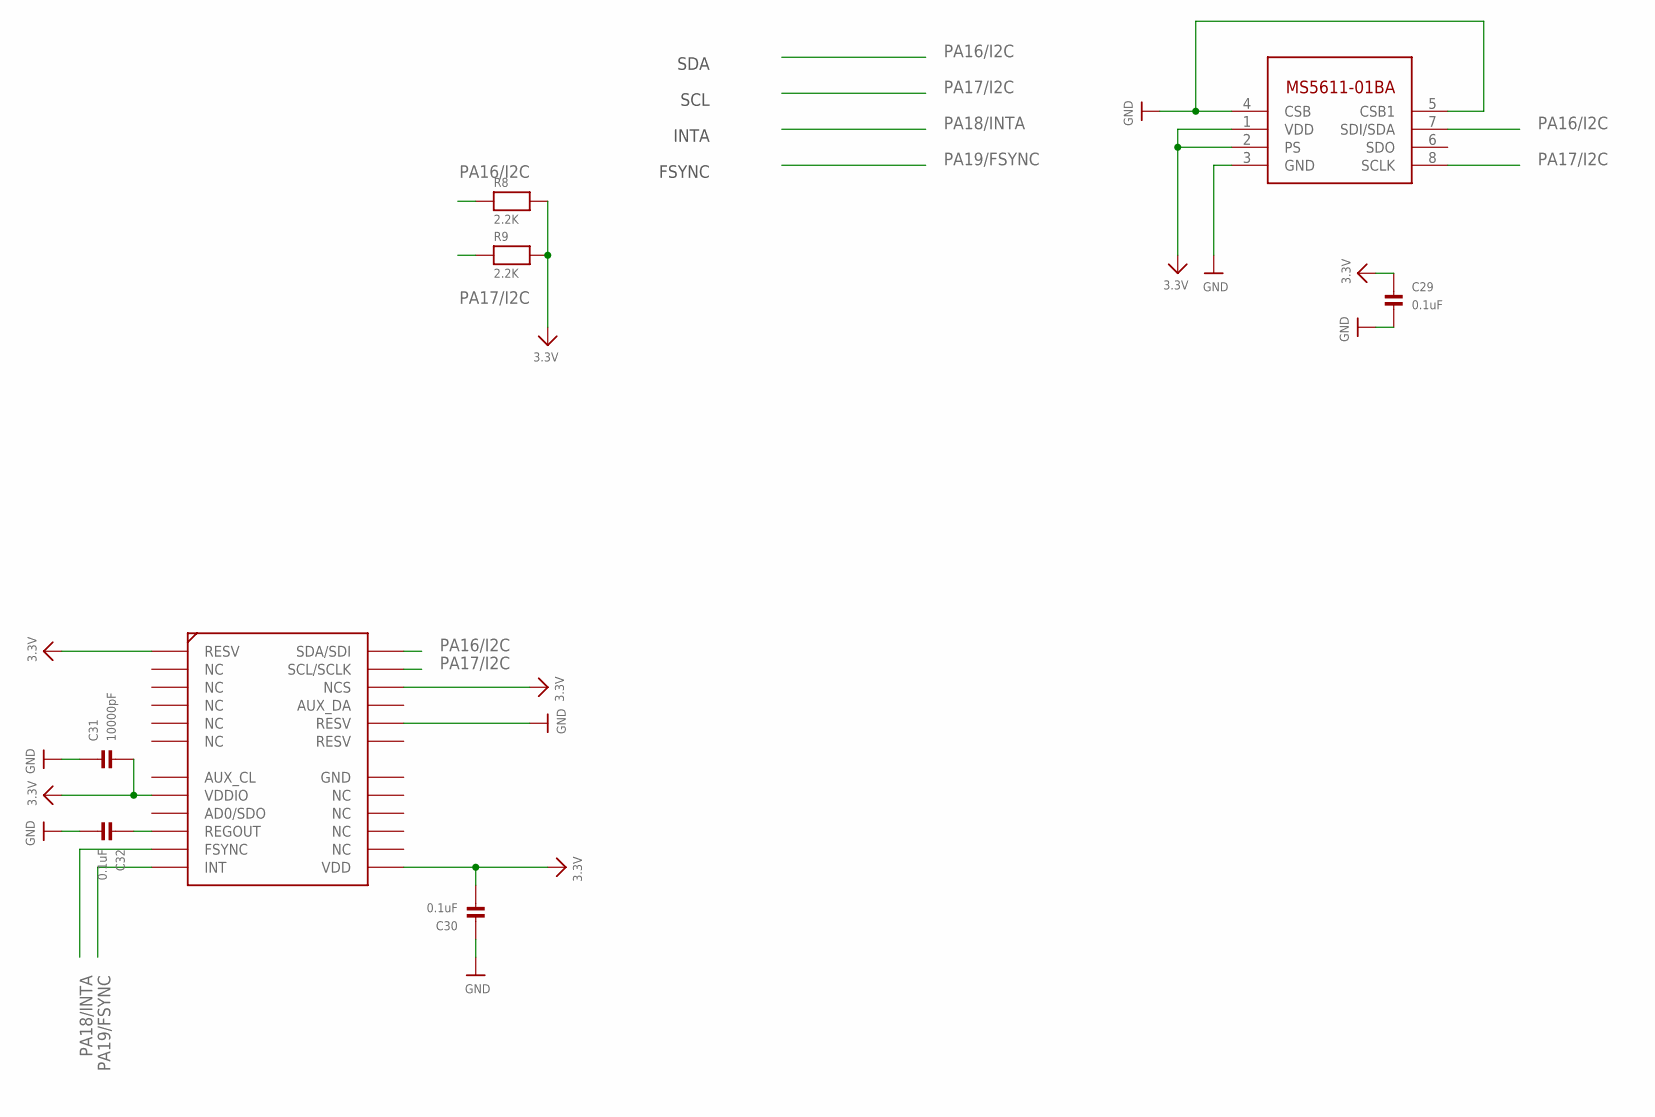
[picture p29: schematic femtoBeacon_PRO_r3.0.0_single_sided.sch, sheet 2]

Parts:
BARO: MS5611-01BA03
C29, C30, C32: 0.1uF; _0402MP; DIGIKEY_PART 490-3194-1-ND
C31: 10000pF; _0402MP; DIGIKEY_PART 490-3194-1-ND
IMU: MPU-9250; QFN_3X3MM
R8, R9: 2.2K; _0402MP

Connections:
3.3V: BARO.1 (VDD), BARO.2 (PS), C29.1, C30.2, C31.2, IMU.P$1 (RESV), IMU.P$8 (VDDIO), IMU.P$13 (VDD), IMU.P$22 (NCS), R8.2, R9.2; also elsewhere on the board
GND: BARO.3 (GND), BARO.4 (CSB), BARO.5 (CSB1), C29.2, C30.1, C31.1, C32.2, IMU.P$20 (RESV); also elsewhere on the board
unnamed: C32.1, IMU.P$10 (REGOUT)
PA16/I2C: BARO.7 (SDI/SDA), IMU.P$24 (SDA/SDI), R8.1; also elsewhere on the board
PA17/I2C: BARO.8 (SCLK), IMU.P$23 (SCL/SCLK), R9.1; also elsewhere on the board
PA18/INTA: IMU.P$11 (FSYNC); also elsewhere on the board
PA19/FSYNC: IMU.P$12 (INT); also elsewhere on the board

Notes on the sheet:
SDA
SCL
INTA
FSYNC

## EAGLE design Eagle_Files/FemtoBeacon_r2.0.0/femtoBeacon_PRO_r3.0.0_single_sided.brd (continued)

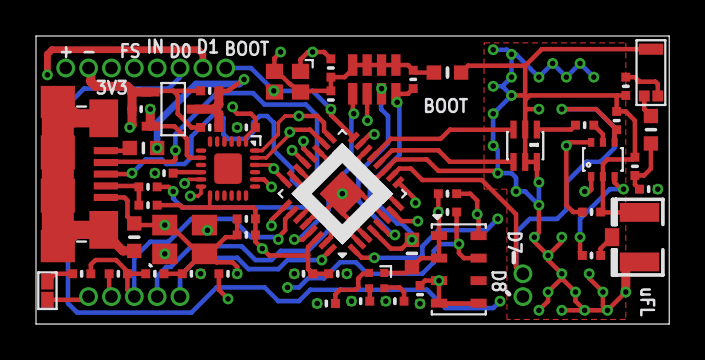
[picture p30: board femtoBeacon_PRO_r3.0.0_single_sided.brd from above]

Board: 4 copper layers, 35.2 x 16.0 mm, 54 parts (0 on the bottom side), 44 nets.

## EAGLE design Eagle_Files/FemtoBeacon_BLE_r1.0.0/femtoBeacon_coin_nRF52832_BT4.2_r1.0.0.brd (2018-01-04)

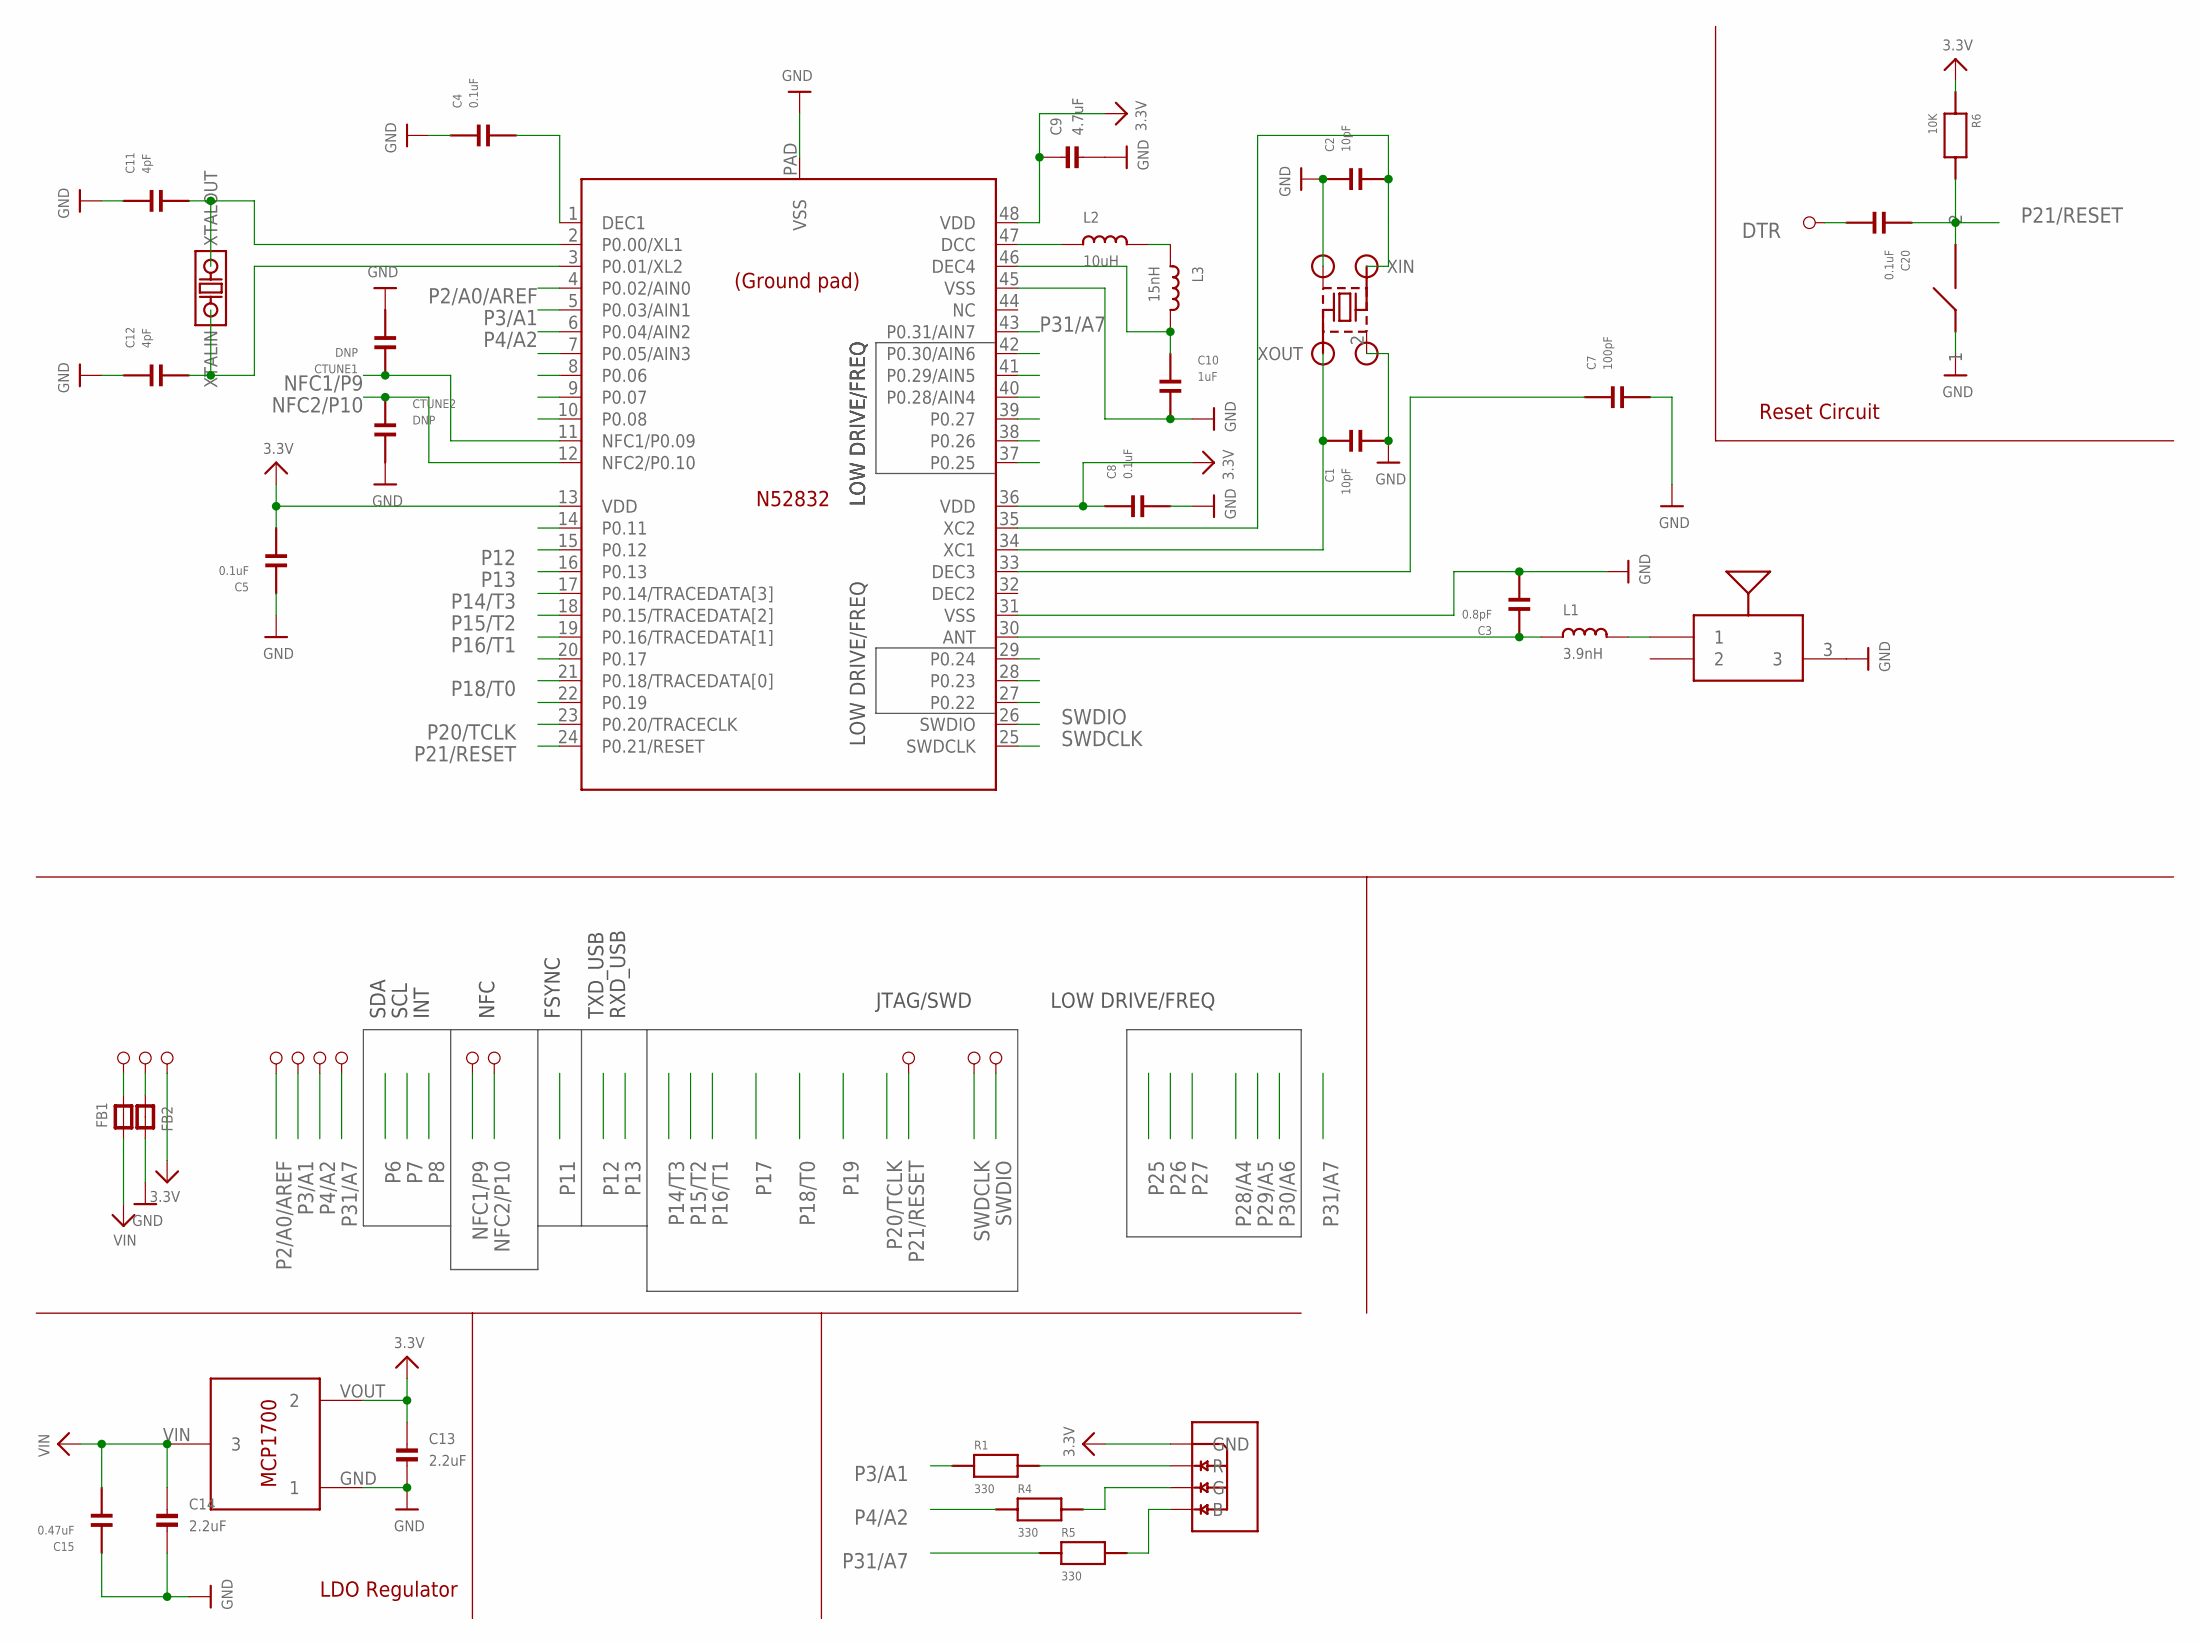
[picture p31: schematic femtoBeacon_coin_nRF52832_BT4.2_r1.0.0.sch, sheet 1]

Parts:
ANTBAR: PULSE_ANT_2.4GHZ; ANT_BAR
C1, C2: 10pF; PART
C3: 0.8pF; PART
C4, C5, C8, C20: 0.1uF; PART
C7: 100pF; PART
C9: 4.7uF; _0402MP
C10: 1uF; PART
C11, C12: 4pF; PART
C13, C14: 2.2uF; _0402MP
C15: 0.47uF; PART
CTUNE1, CTUNE2: DNP; PART
FB1, FB2: FERRITE_0603MP; _0603MP
IC1: NRF52832_QFN48; QFN48
L1: 3.9nH; _0402MP
L2: 10uH; _0603MP
L3: 15nH; _0402MP
LDO_VREG: MCP1700T-3302E/TT
LED1: LRTB_R48G
PIN1, PIN2, PIN3, PIN4, PIN7, PIN8, PIN9, PIN10, PIN13, PIN14, PIN25, PIN26, PIN27: 1X1_ROUND
R1, R4, R5: 330; PART
R6: 10K; PART
RESET_JMP: SPST_SMD
XOSC32K: ABS06-107-32.768KHZ-T
XTAL: 32MHz; ABM11

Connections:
3.3V: C5.2, C8.1, C9.1, C13.1, IC1.13 (VDD), IC1.36 (VDD), IC1.48 (VDD), LDO_VREG.VOUT (2), LED1.1 (GND), PIN3.P$1, R6.1; also elsewhere on the board
B: LED1.4 (B), R5.2
DTR: C20.2, PIN4.P$1
G: LED1.3 (G), R4.2
GND: ANTBAR.3, C1.2, C2.1, C3.2, C4.1, C5.1, C7.2, C8.2, C9.2, C10.2, C11.1, C12.1, C13.2, C14.2, C15.1, CTUNE1.2, CTUNE2.2, FB2.2, IC1.31 (VSS), IC1.45 (VSS), IC1.PAD (VSS), LDO_VREG.GND (1), RESET_JMP.1, XTAL.2 (GND), XTAL.4 (GND); also elsewhere on the board
unnamed: C4.2, IC1.1 (DEC1)
unnamed: L2.2, L3.1
unnamed: IC1.47 (DCC), L2.1
unnamed: C7.1, IC1.33 (DEC3)
unnamed: FB2.1, PIN2.P$1
unnamed: C10.1, IC1.46 (DEC4), L3.2
unnamed: FB1.2, PIN1.P$1
unnamed: C3.1, IC1.30 (ANT), L1.1
NFC1/P9: CTUNE1.1, IC1.11 (NFC1/P0.09), PIN13.P$1
NFC2/P10: CTUNE2.1, IC1.12 (NFC2/P0.10), PIN14.P$1
P0/XIN32: C11.2, IC1.2 (P0.00/XL1), XOSC32K.2 (XTALOUT)
P1/XOUT32: C12.2, IC1.3 (P0.01/XL2), XOSC32K.1 (XTALIN)
P2/A0/AREF: IC1.4 (P0.02/AIN0), PIN9.P$1
P3/A1: IC1.5 (P0.03/AIN1), PIN10.P$1, R1.1
P4/A2: IC1.6 (P0.04/AIN2), PIN7.P$1, R4.1
P5/A3: IC1.7 (P0.05/AIN3)
P6: IC1.8 (P0.06); also elsewhere on the board
P7: IC1.9 (P0.07); also elsewhere on the board
P8: IC1.10 (P0.08); also elsewhere on the board
P11: IC1.14 (P0.11); also elsewhere on the board
P12: IC1.15 (P0.12)
P13: IC1.16 (P0.13)
P14/T3: IC1.17 (P0.14/TRACEDATA[3])
P15/T2: IC1.18 (P0.15/TRACEDATA[2])
P16/T1: IC1.19 (P0.16/TRACEDATA[1])
P17: IC1.20 (P0.17)
P18/T0: IC1.21 (P0.18/TRACEDATA[0])
P19: IC1.22 (P0.19)
P20/TCLK: IC1.23 (P0.20/TRACECLK)
P21/RESET: C20.1, IC1.24 (P0.21/RESET), PIN25.P$1, R6.2, RESET_JMP.2
P22: IC1.27 (P0.22)
P23: IC1.28 (P0.23)
P24: IC1.29 (P0.24)
P25: IC1.37 (P0.25)
P26: IC1.38 (P0.26)
P27: IC1.39 (P0.27)
P28/A4: IC1.40 (P0.28/AIN4)
P29/A5: IC1.41 (P0.29/AIN5)
P30/A6: IC1.42 (P0.30/AIN6)
P31/A7: IC1.43 (P0.31/AIN7), PIN8.P$1, R5.1
R: LED1.2 (R), R1.2
RF: ANTBAR.1, L1.2
SWDCLK: IC1.25 (SWDCLK), PIN26.P$1
SWDIO: IC1.26 (SWDIO), PIN27.P$1
VIN: C14.1, C15.2, FB1.1, LDO_VREG.VIN (3)
XIN: C1.1, IC1.34 (XC1), XTAL.3 (XOUT)
XOUT: C2.2, IC1.35 (XC2), XTAL.1 (XIN)

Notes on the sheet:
LOW DRIVE/FREQ
SDA
SCL
INT
FSYNC
TXD_USB
RXD_USB
Reset Circuit
LDO Regulator
JTAG/SWD
NFC


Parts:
BARO1: MS5611-01BA03
C16, C17, C19: 0.1uF; PART
C18: 10nF; PART
IMU1: MPU-9250; QFN_3X3MM
R2, R3: 2.2K; PART

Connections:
3.3V: BARO1.1 (VDD), BARO1.2 (PS), C16.2, C17.2, C18.2, IMU1.P$1 (RESV), IMU1.P$8 (VDDIO), IMU1.P$13 (VDD), IMU1.P$22 (NCS), R2.1, R3.1; also elsewhere on the board
GND: BARO1.3 (GND), BARO1.4 (CSB), BARO1.5 (CSB1), C16.1, C17.1, C18.1, C19.2, IMU1.P$20 (RESV); also elsewhere on the board
P6: BARO1.7 (SDI/SDA), IMU1.P$24 (SDA/SDI), R2.2; also elsewhere on the board
P7: BARO1.8 (SCLK), IMU1.P$23 (SCL/SCLK), R3.2; also elsewhere on the board
P8: IMU1.P$12 (INT); also elsewhere on the board
P11: IMU1.P$11 (FSYNC); also elsewhere on the board
REGOUT: C19.1, IMU1.P$10 (REGOUT)

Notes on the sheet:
MPU9250
SDA
SCL
INT
FSYNC


Board: 4 copper layers, 18.0 x 18.0 mm, 54 parts (1 on the bottom side), 34 nets.

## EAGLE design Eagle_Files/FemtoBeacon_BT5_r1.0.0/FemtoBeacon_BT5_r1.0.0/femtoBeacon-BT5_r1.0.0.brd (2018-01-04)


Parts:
ANT: 0479480001
C1, C2: 10pF; _0402MP
C3: 0.8pF; _0402MP
C4: 0.5pF; _0402MP
C5, C7, C8, C12: 0.1uF; _0402MP
C6, C18, C19, C20: 4.7uF; _0402MP
C11: 100pF; _0402MP
C14, C15: 1.0uF; _0402MP
C16, C17: 12pF; _0402MP
C21, C22: 2.2uF; _0402MP
C23: 0.47uF; _0402MP
FB1, FB2: FERRITE_0603MP; _0603MP
FID1, FID2, FID3: FIDUCIAL; FIDUCIAL_1MM
IC: NRF52840
L1: 3.3nH; _0402MP
L2, L4: 10uH; _0402MP
L3: 15nH; _0402MP
LDO_VREG: MCP1700T-3302E/TT
RES1: 330; RESPACK_4X0603
U$1: 1X5_ROUND
U$7: LRTB_R48G
U$27: 1X7_ROUND
USB: USB_MICROB; USB_MICROB_PACKAGE
X1: 32MHz; FA-128
X2: 32.768kHZ; ABS06-107-32.768KHZ-T

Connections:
ANT: C3.2, IC.H23 (ANT), L1.1
BLUE: IC.W24 (P1.02), RES1.4 (1)
CS: IC.AC19 (P0.23), U$27.P$7 (7); also elsewhere on the board
D23: C11.1, IC.D23 (DEC3)
DCCH: IC.AB2 (DCCH), L4.2
DEC1: C5.1, IC.C1 (DEC1)
DEC3V3: C19.1, IC.AC5 (DEC3V3)
FSYNC_PIN: IC.AC21 (P0.25); also elsewhere on the board
GND: C1.2, C2.1, C3.1, C4.1, C5.2, C6.2, C7.2, C8.2, C11.2, C12.1, C14.1, C15.2, C16.1, C17.2, C18.2, C19.2, C20.2, C21.2, C22.2, C23.2, FB2.2, IC.B7 (VSS), IC.F23 (VSS_PA), IC.VSS (VSS_DIE_PAD), LDO_VREG.GND (1), U$1.P$1 (1), U$7.1 (GND), U$27.P$1 (1), X1.2 (GND), X1.4 (GND); also elsewhere on the board
GND_IN: FB2.1, USB.5 (GND), USB.6 (GND2), USB.7 (GND4), USB.8 (GND5), USB.9 (GND6), USB.10 (GND7), USB.11 (GND3)
GREEN: IC.U24 (P1.04), RES1.3 (1)
INT_WAKE: IC.J1 (P0.04/AIN2); also elsewhere on the board
MISO: IC.AD18 (P0.22), U$27.P$6 (6); also elsewhere on the board
MOSI: IC.AC17 (P0.21), U$27.P$3 (3); also elsewhere on the board
unnamed: FB1.2, USB.1 (V)
unnamed: RES1.5 (2), U$7.4 (B)
unnamed: RES1.6 (2), U$7.3 (G)
unnamed: RES1.7 (2), U$7.2 (R)
unnamed: IC.B3 (DCC), L2.2
unnamed: L2.1, L3.2
unnamed: C15.1, IC.B5 (DEC4), L3.1
P0.18/RESET: IC.AC13 (P0.18/RESET), U$1.P$3 (3), U$27.P$5 (5)
RED: IC.R24 (P1.06), RES1.2 (1)
RF: ANT.ANT (1), C4.2, L1.2
SCK: IC.AC15 (P0.19), U$27.P$4 (4); also elsewhere on the board
SWDCLK: IC.AA24 (SWDCLK), U$1.P$4 (4)
SWDIO: IC.AC24 (SWDIO), U$1.P$5 (5)
USB_DM: IC.AD4 (D-), USB.2 (D-)
USB_DP: IC.AD6 (D+), USB.3 (D+)
VDD: C6.1, C7.1, C8.1, C12.2, C14.2, C18.1, C20.1, C21.1, IC.A22 (VDD), IC.AD2 (VBUS), IC.AD14 (VDD), IC.AD23 (VDD), IC.B1 (VDD), IC.W1 (VDD), IC.Y2 (VDDH), L4.1, LDO_VREG.VOUT (2), U$1.P$2 (2), U$27.P$2 (2); also elsewhere on the board
VIN: C22.1, C23.1, FB1.1, LDO_VREG.VIN (3)
XC1: C1.1, IC.B24 (XC1), X1.1 (XIN)
XC2: C2.2, IC.A23 (XC2), X1.3 (XOUT)
XL1: C17.1, IC.D2 (P0.00/XL1), X2.2 (XTALOUT)
XL2: C16.2, IC.F2 (P0.01/XL2), X2.1 (XTALIN)


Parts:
BARO: MS5611-01BA03
C9: 10nF; _0402MP
C10, C13, C24: 0.1uF; _0402MP
IMU: MPU-9250; QFN_3X3MM
R1, R2: 10k; _0402MP
SJ1: SOLDERJUMPERCLOSED; SOLDERJUMPER_CLOSEDWIRE
SJ2: SOLDERJUMPER_2WAY; SOLDERJUMPER_2WAY_OPEN_NOPASTE

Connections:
CS: BARO.4 (CSB), BARO.5 (CSB1), IMU.P$22 (NCS); also elsewhere on the board
FSYNC: IMU.P$11 (FSYNC), SJ2.2
FSYNC_PIN: SJ2.3; also elsewhere on the board
GND: BARO.3 (GND), C9.1, C10.1, C13.2, C24.1, IMU.P$18 (GND), IMU.P$20 (RESV), R1.1, R2.1; also elsewhere on the board
INT: IMU.P$12 (INT), SJ1.2
INT_WAKE: SJ1.1; also elsewhere on the board
MISO: BARO.6 (SDO), IMU.P$9 (AD0/SDO); also elsewhere on the board
MOSI: BARO.7 (SDI/SDA), IMU.P$24 (SDA/SDI); also elsewhere on the board
unnamed: R1.2, SJ2.1
unnamed: C10.2, IMU.P$10 (REGOUT)
PS: BARO.2 (PS), R2.2
SCK: BARO.8 (SCLK), IMU.P$23 (SCL/SCLK); also elsewhere on the board
VDD: BARO.1 (VDD), C9.2, C13.1, C24.2, IMU.P$1 (RESV), IMU.P$8 (VDDIO), IMU.P$13 (VDD); also elsewhere on the board

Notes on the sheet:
INT: Totem-pole or Open Drain
PS - PULL DOWN = SPI
PS - PULL UP = I2C



Board: 4 copper layers, 33.0 x 40.6 mm, 49 parts (2 on the bottom side), 40 nets.

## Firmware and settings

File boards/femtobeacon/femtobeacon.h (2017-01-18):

/**
 * \file
 *
 * \brief FemtoBeacon board definition
 *
 * Copyright (c) 2014 Atmel Corporation. All rights reserved.
 *
 * \asf_license_start
 *
 * \page License
 *
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
 * 3. The name of Atmel may not be used to endorse or promote products derived
 *    from this software without specific prior written permission.
 *
 * 4. This software may only be redistributed and used in connection with an
 *    Atmel microcontroller product.
 *
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
 * \asf_license_stop
 *
 */
 /**
 * Support and FAQ: visit <a href="http://www.atmel.com/design-support/">Atmel Support</a>
 */

#ifndef FEMTOBEACON_H_INCLUDED
#define FEMTOBEACON_H_INCLUDED

#include <conf_board.h>
#include <compiler.h>

#ifdef __cplusplus
extern "C" {
#endif

/**
 * \ingroup group_common_boards
 * \defgroup FEMTOBEACON_group SAM R21 Xplained Pro board
 *
 * @{
 */

void system_board_init(void);

/**
 * \defgroup FEMTOBEACON_features_group Features
 *
 * Symbols that describe features and capabilities of the board.
 *
 * @{
 */

/** Name string macro */
#define BOARD_NAME                "FEMTOBEACON"

/** \name Resonator definitions
 *  @{ */
#define BOARD_FREQ_SLCK_XTAL      (32768U)
#define BOARD_FREQ_SLCK_BYPASS    (32768U)
#define BOARD_FREQ_MAINCK_XTAL    0 /* Not Mounted */
#define BOARD_FREQ_MAINCK_BYPASS  0 /* Not Mounted */
#define BOARD_MCK                 CHIP_FREQ_CPU_MAX
#define BOARD_OSC_STARTUP_US      15625
/** @} */

/** \name LED0 definitions
 *  @{ */
#define LED0_PIN                  PIN_PA19
#define LED0_ACTIVE               false
#define LED0_INACTIVE             !LED0_ACTIVE
#define LED0 LED0_PIN
/** @} */

/** \name SW0 definitions
 *  @{ */
#define SW0_PIN                   PIN_PA28
#define SW0_ACTIVE                false
#define SW0_INACTIVE              !SW0_ACTIVE
#define SW0_EIC_PIN               PIN_PA28A_EIC_EXTINT8
#define SW0_EIC_MUX               MUX_PA28A_EIC_EXTINT8
#define SW0_EIC_PINMUX            PINMUX_PA28A_EIC_EXTINT8
#define SW0_EIC_LINE              8
/** @} */

/**
 * \name LED #0 definitions
 *
 * Wrapper macros for LED0, to ensure common naming across all Xplained Pro
 * boards.
 *
 *  @{ */
#define LED_0_NAME                "LED0 (yellow)" # Not used on FemtoBeacon
#define LED_0_PIN                 LED0_PIN
#define LED_0_ACTIVE              LED0_ACTIVE
#define LED_0_INACTIVE            LED0_INACTIVE
#define LED0_GPIO                 LED0_PIN

#define LED_0_PWM_MODULE          TC3
#define LED_0_PWM_CHANNEL         1
#define LED_0_PWM_OUTPUT          1
#define LED_0_PWM_PIN             PIN_PA19E_TC3_WO1
#define LED_0_PWM_MUX             MUX_PA19E_TC3_WO1
#define LED_0_PWM_PINMUX          PINMUX_PA19E_TC3_WO1

#define LED_0_PWM4CTRL_MODULE     TCC0
#define LED_0_PWM4CTRL_CHANNEL    3
#define LED_0_PWM4CTRL_OUTPUT     3
#define LED_0_PWM4CTRL_PIN        PIN_PA19F_TCC0_WO3
#define LED_0_PWM4CTRL_MUX        MUX_PA19F_TCC0_WO3
#define LED_0_PWM4CTRL_PINMUX     PINMUX_PA19F_TCC0_WO3
/** @} */

/** Number of on-board LEDs */
#define LED_COUNT                 1


/**
 * \name Button #0 definitions
 *
 * Wrapper macros for SW0, to ensure common naming across all Xplained Pro
 * boards.
 *
 *  @{ */
#define BUTTON_0_NAME             "SW0"
#define BUTTON_0_PIN              SW0_PIN
#define BUTTON_0_ACTIVE           SW0_ACTIVE
#define BUTTON_0_INACTIVE         SW0_INACTIVE
#define BUTTON_0_EIC_PIN          SW0_EIC_PIN
#define BUTTON_0_EIC_MUX          SW0_EIC_MUX
#define BUTTON_0_EIC_PINMUX       SW0_EIC_PINMUX
#define BUTTON_0_EIC_LINE         SW0_EIC_LINE
/** @} */

/** Number of on-board buttons */
#define BUTTON_COUNT 1

/** \name Extension header #1 pin definitions
 *  @{
 */
#define EXT1_PIN_3                PIN_PA06
#define EXT1_PIN_4                PIN_PA07
#define EXT1_PIN_5                PIN_PA13
#define EXT1_PIN_6                PIN_PA28
#define EXT1_PIN_7                PIN_PA18
#define EXT1_PIN_8                PIN_PA19
#define EXT1_PIN_9                PIN_PA22
#define EXT1_PIN_10               PIN_PA23
#define EXT1_PIN_11               PIN_PA16
#define EXT1_PIN_12               PIN_PA17
#define EXT1_PIN_13               PIN_PA05
#define EXT1_PIN_14               PIN_PA04
#define EXT1_PIN_15               PIN_PB03
#define EXT1_PIN_16               PIN_PB22
#define EXT1_PIN_17               PIN_PB02
#define EXT1_PIN_18               PIN_PB23
/** @} */

/** \name Extension header #1 pin definitions by function
 *  @{
 */
#define EXT1_PIN_ADC_0            EXT1_PIN_3
#define EXT1_PIN_ADC_1            EXT1_PIN_4
#define EXT1_PIN_GPIO_0           EXT1_PIN_5
#define EXT1_PIN_GPIO_1           EXT1_PIN_6
#define EXT1_PIN_PWM_0            EXT1_PIN_7
#define EXT1_PIN_PWM_1            EXT1_PIN_8
#define EXT1_PIN_GPIO_3           EXT1_PIN_9
#define EXT1_PIN_GPIO_4           EXT1_PIN_10
#define EXT1_PIN_I2C_SDA          EXT1_PIN_11
#define EXT1_PIN_I2C_SCL          EXT1_PIN_12
#define EXT1_PIN_UART_RX          EXT1_PIN_13
#define EXT1_PIN_UART_TX          EXT1_PIN_14
#define EXT1_PIN_SPI_SS_0         EXT1_PIN_15
#define EXT1_PIN_SPI_MOSI         EXT1_PIN_16
#define EXT1_PIN_SPI_MISO         EXT1_PIN_17
#define EXT1_PIN_SPI_SCK          EXT1_PIN_18
/** @} */

/** \name Extension header #1 ADC definitions
 *  @{
 */
#define EXT1_ADC_MODULE           ADC
#define EXT1_ADC_0_CHANNEL        6
#define EXT1_ADC_0_PIN            PIN_PA06B_ADC_AIN6
#define EXT1_ADC_0_MUX            MUX_PA06B_ADC_AIN6
#define EXT1_ADC_0_PINMUX         PINMUX_PA06B_ADC_AIN6
#define EXT1_ADC_1_CHANNEL        7
#define EXT1_ADC_1_PIN            PIN_PA07B_ADC_AIN7
#define EXT1_ADC_1_MUX            MUX_PA07B_ADC_AIN7
#define EXT1_ADC_1_PINMUX         PINMUX_PA07B_ADC_AIN7
/** @} */

/** \name Extension header #1 PWM definitions
 *  @{
 */
#define EXT1_PWM_MODULE           TC3
#define EXT1_PWM_0_CHANNEL        0
#define EXT1_PWM_0_PIN            PIN_PA18E_TC3_WO0
#define EXT1_PWM_0_MUX            MUX_PA18E_TC3_WO0
#define EXT1_PWM_0_PINMUX         PINMUX_PA18E_TC3_WO0
#define EXT1_PWM_1_CHANNEL        1
#define EXT1_PWM_1_PIN            PIN_PA19E_TC3_WO1
#define EXT1_PWM_1_MUX            MUX_PA19E_TC3_WO1
#define EXT1_PWM_1_PINMUX         PINMUX_PA19E_TC3_WO1
/** @} */

/** \name Extension header #1 PWM for Control definitions
 *  @{
 */
#define EXT1_PWM4CTRL_MODULE      TCC0
#define EXT1_PWM4CTRL_0_CHANNEL   2
#define EXT1_PWM4CTRL_0_OUTPUT    2
#define EXT1_PWM4CTRL_0_PIN       PIN_PA18F_TCC0_WO2
#define EXT1_PWM4CTRL_0_MUX       MUX_PA18F_TCC0_WO2
#define EXT1_PWM4CTRL_0_PINMUX    PINMUX_PA18F_TCC0_WO2
#define EXT1_PWM4CTRL_1_CHANNEL   3
#define EXT1_PWM4CTRL_1_OUTPUT    3
#define EXT1_PWM4CTRL_1_PIN       PIN_PA19F_TCC0_WO3
#define EXT1_PWM4CTRL_1_MUX       MUX_PA19F_TCC0_WO3
#define EXT1_PWM4CTRL_1_PINMUX    PINMUX_PA19F_TCC0_WO3
/** @} */
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

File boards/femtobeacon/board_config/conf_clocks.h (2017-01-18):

/**
 * \file
 *
 * \brief SAM R21 Clock configuration
 *
 * Copyright (C) 2014 Atmel Corporation. All rights reserved.
 *
 * \asf_license_start
 *
 * \page License
 *
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
 * 3. The name of Atmel may not be used to endorse or promote products derived
 *    from this software without specific prior written permission.
 *
 * 4. This software may only be redistributed and used in connection with an
 *    Atmel microcontroller product.
 *
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
 * \asf_license_stop
 *
 */
 /**
 * Support and FAQ: visit <a href="http://www.atmel.com/design-support/">Atmel Support</a>
 */
#include <clock.h>

#ifndef CONF_CLOCKS_H_INCLUDED
#  define CONF_CLOCKS_H_INCLUDED

/* System clock bus configuration */
#  define CONF_CLOCK_CPU_CLOCK_FAILURE_DETECT     false
#  define CONF_CLOCK_FLASH_WAIT_STATES            0
#  define CONF_CLOCK_CPU_DIVIDER                  SYSTEM_MAIN_CLOCK_DIV_1
#  define CONF_CLOCK_APBA_DIVIDER                 SYSTEM_MAIN_CLOCK_DIV_1
#  define CONF_CLOCK_APBB_DIVIDER                 SYSTEM_MAIN_CLOCK_DIV_1

/* SYSTEM_CLOCK_SOURCE_OSC8M configuration - Internal 8MHz oscillator */
#  define CONF_CLOCK_OSC8M_PRESCALER              SYSTEM_OSC8M_DIV_1
#  define CONF_CLOCK_OSC8M_ON_DEMAND              true
#  define CONF_CLOCK_OSC8M_RUN_IN_STANDBY         false

/* SYSTEM_CLOCK_SOURCE_XOSC configuration - External clock/oscillator */
#  define CONF_CLOCK_XOSC_ENABLE                  false
#  define CONF_CLOCK_XOSC_EXTERNAL_CRYSTAL        SYSTEM_CLOCK_EXTERNAL_CRYSTAL
#  define CONF_CLOCK_XOSC_EXTERNAL_FREQUENCY      12000000UL
#  define CONF_CLOCK_XOSC_STARTUP_TIME            SYSTEM_XOSC_STARTUP_32768
#  define CONF_CLOCK_XOSC_AUTO_GAIN_CONTROL       true
#  define CONF_CLOCK_XOSC_ON_DEMAND               true
#  define CONF_CLOCK_XOSC_RUN_IN_STANDBY          false

/* SYSTEM_CLOCK_SOURCE_XOSC32K configuration - External 32KHz crystal/clock oscillator */
#  define CONF_CLOCK_XOSC32K_ENABLE               false
#  define CONF_CLOCK_XOSC32K_EXTERNAL_CRYSTAL     SYSTEM_CLOCK_EXTERNAL_CRYSTAL
#  define CONF_CLOCK_XOSC32K_STARTUP_TIME         SYSTEM_XOSC32K_STARTUP_65536
#  define CONF_CLOCK_XOSC32K_AUTO_AMPLITUDE_CONTROL  false
#  define CONF_CLOCK_XOSC32K_ENABLE_1KHZ_OUPUT    false
#  define CONF_CLOCK_XOSC32K_ENABLE_32KHZ_OUTPUT  true
#  define CONF_CLOCK_XOSC32K_ON_DEMAND            true
#  define CONF_CLOCK_XOSC32K_RUN_IN_STANDBY       false

/* SYSTEM_CLOCK_SOURCE_OSC32K configuration - Internal 32KHz oscillator */
#  define CONF_CLOCK_OSC32K_ENABLE                false
#  define CONF_CLOCK_OSC32K_STARTUP_TIME          SYSTEM_OSC32K_STARTUP_130
#  define CONF_CLOCK_OSC32K_ENABLE_1KHZ_OUTPUT    true
#  define CONF_CLOCK_OSC32K_ENABLE_32KHZ_OUTPUT   true
#  define CONF_CLOCK_OSC32K_ON_DEMAND             true
#  define CONF_CLOCK_OSC32K_RUN_IN_STANDBY        false

/* SYSTEM_CLOCK_SOURCE_DFLL configuration - Digital Frequency Locked Loop */
#  define CONF_CLOCK_DFLL_ENABLE                  false
#  define CONF_CLOCK_DFLL_LOOP_MODE               SYSTEM_CLOCK_DFLL_LOOP_MODE_OPEN
#  define CONF_CLOCK_DFLL_ON_DEMAND               false

/* DFLL open loop mode configuration */
#  define CONF_CLOCK_DFLL_COARSE_VALUE            (0x1f / 4)
#  define CONF_CLOCK_DFLL_FINE_VALUE              (0xff / 4)

/* DFLL closed loop mode configuration */
#  define CONF_CLOCK_DFLL_SOURCE_GCLK_GENERATOR   GCLK_GENERATOR_1
#  define CONF_CLOCK_DFLL_MULTIPLY_FACTOR         6
#  define CONF_CLOCK_DFLL_QUICK_LOCK              true
#  define CONF_CLOCK_DFLL_TRACK_AFTER_FINE_LOCK   true
#  define CONF_CLOCK_DFLL_KEEP_LOCK_ON_WAKEUP     true
#  define CONF_CLOCK_DFLL_ENABLE_CHILL_CYCLE      true
#  define CONF_CLOCK_DFLL_MAX_COARSE_STEP_SIZE    (0x1f / 4)
#  define CONF_CLOCK_DFLL_MAX_FINE_STEP_SIZE      (0xff / 4)

/* SYSTEM_CLOCK_SOURCE_DPLL configuration - Digital Phase-Locked Loop */
#  define CONF_CLOCK_DPLL_ENABLE                  false
#  define CONF_CLOCK_DPLL_ON_DEMAND               true
#  define CONF_CLOCK_DPLL_RUN_IN_STANDBY          false
#  define CONF_CLOCK_DPLL_LOCK_BYPASS             false
#  define CONF_CLOCK_DPLL_WAKE_UP_FAST            false
#  define CONF_CLOCK_DPLL_LOW_POWER_ENABLE        false

#  define CONF_CLOCK_DPLL_LOCK_TIME               SYSTEM_CLOCK_SOURCE_DPLL_LOCK_TIME_NO_TIMEOUT
#  define CONF_CLOCK_DPLL_REFERENCE_CLOCK         SYSTEM_CLOCK_SOURCE_DPLL_REFERENCE_CLOCK_REF0
#  define CONF_CLOCK_DPLL_FILTER                  SYSTEM_CLOCK_SOURCE_DPLL_FILTER_DEFAULT

#  define CONF_CLOCK_DPLL_REFERENCE_FREQUENCY     32768
#  define CONF_CLOCK_DPLL_REFEREMCE_DIVIDER       1
#  define CONF_CLOCK_DPLL_OUTPUT_FREQUENCY        48000000

/* Set this to true to configure the GCLK when running clocks_init. If set to
 * false, none of the GCLK generators will be configured in clocks_init(). */
//! [conf_clock_sysclk_settings] 
#  define CONF_CLOCK_CONFIGURE_GCLK               true
//! [conf_clock_sysclk_settings]
/* Configure GCLK generator 0 (Main Clock) */
//! [conf_clock_pll1_settings]
#  define CONF_CLOCK_GCLK_0_ENABLE                true
#  define CONF_CLOCK_GCLK_0_RUN_IN_STANDBY        false
#  define CONF_CLOCK_GCLK_0_CLOCK_SOURCE          SYSTEM_CLOCK_SOURCE_OSC8M
#  define CONF_CLOCK_GCLK_0_PRESCALER             1
#  define CONF_CLOCK_GCLK_0_OUTPUT_ENABLE         false
//! [conf_clock_pll1_settings]

/* Configure GCLK generator 1 */
#  define CONF_CLOCK_GCLK_1_ENABLE                false
#  define CONF_CLOCK_GCLK_1_RUN_IN_STANDBY        false
#  define CONF_CLOCK_GCLK_1_CLOCK_SOURCE          SYSTEM_CLOCK_SOURCE_OSC8M
#  define CONF_CLOCK_GCLK_1_PRESCALER             1
#  define CONF_CLOCK_GCLK_1_OUTPUT_ENABLE         false

/* Configure GCLK generator 2 (RTC) */
#  define CONF_CLOCK_GCLK_2_ENABLE                false
#  define CONF_CLOCK_GCLK_2_RUN_IN_STANDBY        false
#  define CONF_CLOCK_GCLK_2_CLOCK_SOURCE          SYSTEM_CLOCK_SOURCE_OSC32K
#  define CONF_CLOCK_GCLK_2_PRESCALER             32
#  define CONF_CLOCK_GCLK_2_OUTPUT_ENABLE         false

/* Configure GCLK generator 3 */
#  define CONF_CLOCK_GCLK_3_ENABLE                false
#  define CONF_CLOCK_GCLK_3_RUN_IN_STANDBY        false
#  define CONF_CLOCK_GCLK_3_CLOCK_SOURCE          SYSTEM_CLOCK_SOURCE_OSC8M
#  define CONF_CLOCK_GCLK_3_PRESCALER             1
#  define CONF_CLOCK_GCLK_3_OUTPUT_ENABLE         false

/* Configure GCLK generator 4 */
#  define CONF_CLOCK_GCLK_4_ENABLE                false
#  define CONF_CLOCK_GCLK_4_RUN_IN_STANDBY        false
#  define CONF_CLOCK_GCLK_4_CLOCK_SOURCE          SYSTEM_CLOCK_SOURCE_OSC8M
#  define CONF_CLOCK_GCLK_4_PRESCALER             1
#  define CONF_CLOCK_GCLK_4_OUTPUT_ENABLE         false

/* Configure GCLK generator 5 */
#  define CONF_CLOCK_GCLK_5_ENABLE                false
#  define CONF_CLOCK_GCLK_5_RUN_IN_STANDBY        false
#  define CONF_CLOCK_GCLK_5_CLOCK_SOURCE          SYSTEM_CLOCK_SOURCE_OSC8M
#  define CONF_CLOCK_GCLK_5_PRESCALER             1
#  define CONF_CLOCK_GCLK_5_OUTPUT_ENABLE         false
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

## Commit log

2015-05-09 Initial work on the FemtoBeacon board configs, and examples with IMU
    [atmel_samd21e18a.cfg]
2015-05-17 Cleaning up, adding sam-r21-imu example work
2015-05-17 Adding in EAGLE PCB board design files, modifying the blink example
    [atmel_samr21e18a.cfg, configuration.h, femtoBeacon_r2.0.0.brd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]
2015-05-17 Moving the sam-r21-blinky folder to sam-r21-blink
    [atmel_samd21e18a.cfg]
2015-05-17 Adding the blink example back in
    [atmel_samd21e18a.cfg]
2015-05-17 Updating examples, and renaming openocd config files accordingly
    [atmel_samr21e18a.cfg]
2015-05-24 Adding in FemtoBeacon Dongle (SAM R21 w/ Antenna, no IMU and barometer)
    [femtoBeacon_dongle_r2.0.0.brd, femtoBeacon_dongle_r2.0.0.sch]
2016-03-18 Committing current work on FemtoBeacon (zigbee/mesh) r2.0.1, and USB dongle
    [femtoBeacon_dongle_r2.0.1.brd, femtoBeacon_dongle_r2.0.1.sch, femtoBeacon_r2.0.0.brd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]
2016-03-22 Updating femtoBeacon dongle r2.0.1
    [femtoBeacon_dongle_r2.0.1.brd, panel_oshpark_femtoBeacon_r2.0.0.csv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]
2017-11-17 Revision 2.0.7 of the coin, with USB Host and RGB LED, plus u.FL connector
    [femtoBeacon_PRO_r3.0.0_single_sided.brd, femtoBeacon_PRO_r3.0.0_single_sided.csv, femtoBeacon_PRO_r3.0.0_single_sided.sch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]
2017-11-17 Adding Blender 3D case model
    [femtoBeacon_r2.0.3_casing_v0.0.2.blend]
2018-01-04 Adding FemtoBeacon coin r2.0.7, and FemtoBeacon dongle r2.0.6
    [479480001-molex-2.4GHz-smd-omnidirectional.igs, 479480001-molex-2.4GHz-smd-omnidirectional.prt, 479480001-molex-2.4GHz-smd-omnidirectional.stp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]
2018-01-04 A ton of work.
    [20180103_femtobeacon_dongle_r2_0_6_rgb.octopart-bom.csv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]
2018-01-05 Adding dimension data to FemtoBeacon coin r2.0.7, adding stencil and PCB jig model (Blender 3D and STL file for Cura)
    [femtoBeacon_r2.0.7_RGB_OTG.brd, femtoBeacon_r2.0.7_SOLDER_PASTE_JIG-Cube_001.stl, femtoBeacon_r2.0.7_SOLDER_PASTE_JIG.blend]
2018-01-05 Minor update to Blender 3D file
    [femtoBeacon_r2.0.7_SOLDER_PASTE_JIG.blend]
2018-01-12 Adding initial Taiyo Yuden BT5 module based FemtoBeacon revision 2.0.0 design, adding FemtoBeacon Dongle r2.0.6 solder paste/stencil jig (Blender 3D, Cura slice) and FemtoBeacon coin r2.0.7 solder pa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
    [femtoBeacon_BT5_coin-bom-eagle_pcb.csv, femtoBeacon_BT5_coin.brd, femtoBeacon_BT5_coin.csv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]
2018-01-12 Minor update to the Blender 3D modle of femtoBeacon dongle r2.05 solder paste stencil jig
    [femtoBeacon_dongle_r2.0.6_SOLDER_PASTE_JIG.blend]
2018-01-12 Adding in new Cura files for the solder paste stencil jigs
2018-01-12 Updating the femtoBeacon dongle r2.0.6 solder paste jig
    [femtoBeacon_dongle_r2.0.6_SOLDER_PASTE_JIG-Cube.stl, femtoBeacon_dongle_r2.0.6_SOLDER_PASTE_JIG.blend]
2018-01-12 Adjusting Cura slice to improve first layer 3D print

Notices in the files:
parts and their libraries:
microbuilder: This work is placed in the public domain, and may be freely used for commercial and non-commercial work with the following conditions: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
